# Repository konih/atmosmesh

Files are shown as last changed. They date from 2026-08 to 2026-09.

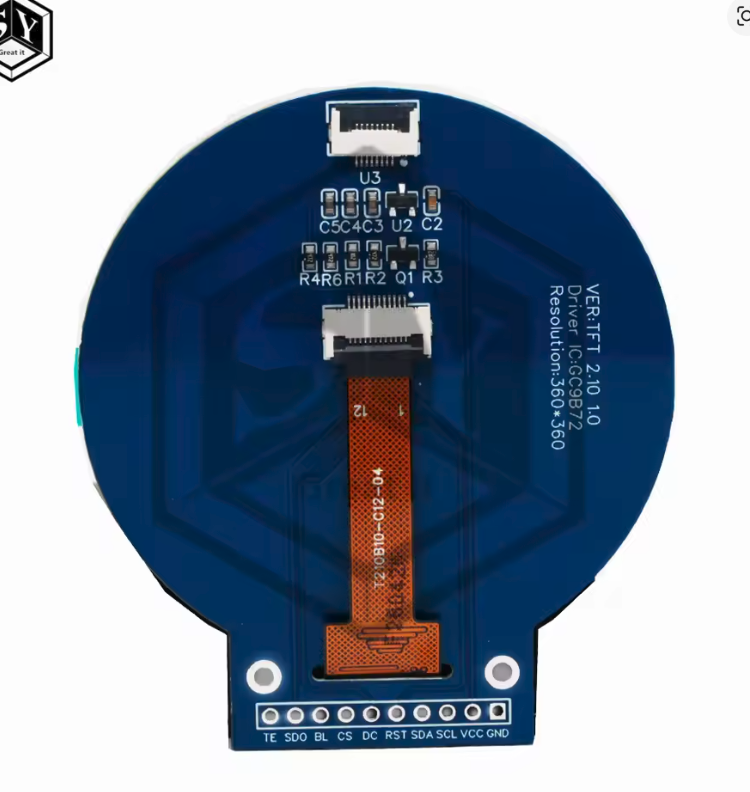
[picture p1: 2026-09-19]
docs/assets/inventory/gc9b72-round-tft-back-2026-09-19.png

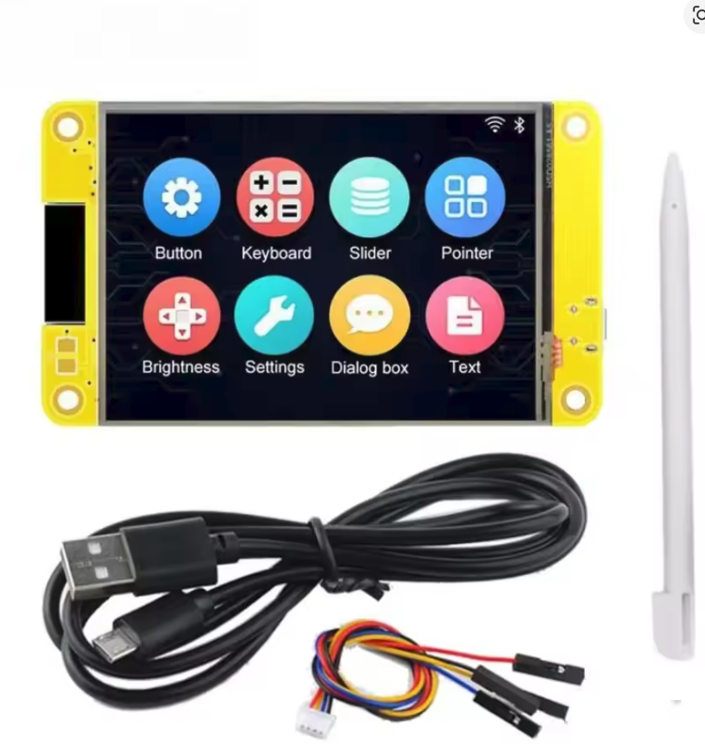
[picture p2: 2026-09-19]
docs/assets/inventory/esp32-2432s028-cyd-kit-2026-09-19.png

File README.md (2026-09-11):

<p align="center">
  AtmosMesh mark
</p>

<h1 align="center">AtmosMesh</h1>

<p align="center"><em>Local air sensing, connected as a mesh.</em></p>

<p align="center">
  
  
  
  
  
  
  
  
</p>

AtmosMesh is a family of local air-sensing firmware products, now spanning several product
variants (v1, Grove v1.5, Aqua, Room, Spot); none supersedes another.

## Firmware products

| Product | Product ID | Product variant | Controller | Sensor/display scope | Canonical build |
| --- | --- | --- | --- | --- | --- |
| **AtmosMesh v1** — **ARCHIVED** (D-034; physical station disassembled 2026-08-31) | `atmosmesh-v1` | `esp32-full-station` | ESP32-WROOM-32 | Full station: SSD1306, BMP280, AM2302, SDS011, MQ135, PIR/beeper, optional VEML7700, MQTT | `task build-v1` (not part of `task build-all`) |
| **AtmosMesh Grove v1.5** | `atmosmesh-grove-v1.5` | `atmosmesh-v1.5` | ESP8266EX / 4 MB NodeMCU-style board | Compact node: 128×32 SSD1306, BMP180, DHT11, uncalibrated D7 RC light, D0/D6 status LED, duty-cycled raw YL-38 ADC, MQTT | `task build-v1-5` |

The products share one PlatformIO project and host-tested core, with explicit composition roots
instead of copied firmware trees. See [ADR-0001](docs/adr/0001-multi-product-firmware-composition.md).

AtmosMesh v1 is **archived, not deleted** ([D-034](agent-context/decisions.md)): the physical
station was disassembled and its code/mentions are retired from the live fleet, but the source,
its tests, and the shared MQTT contract/composition pattern it established remain in the repo.
It was never a finished product — its wiring was never fully approved for unattended or
mains-powered use — and it is **not** a certified health, fire, gas, or life-safety instrument.

## AtmosMesh v1 measurements

| Sensor | Quantity | Notes |
| --- | --- | --- |
| SDS011 | PM2.5, PM10 | UART2 only (GPIO16/17). 5 V heater, 3.3 V UART |
| AM2302 / DHT22 | Temperature, humidity | GPIO18, 3V3 |
| BMP280 | Pressure, temperature | I²C 0x76 on GPIO21/19, 3V3 |
| Mini OLED (D-001) | Local live page | I²C 0x3C, SDA GPIO5, SCL GPIO4, **3V3 only** |
| MQ135 | Relative gas trend | Analog GPIO34 through a divider. **Never labelled CO₂ or ppm** |
| VEML7700 | Illuminance | Optional, I²C 0x10 on the BMP280 bus. Not fitted yet |
| PIR + beeper | Occupancy cue | GPIO33 / GPIO25 |

```text
SDS011 ─┐
AM2302 ─┤
BMP280 ─┼─> ESP32 ── OLED (local)
MQ135  ─┤       └─ MQTT (planned) ──> Mosquitto ──> Home Assistant
VEML   ─┘                         └─ metrics ─> Prometheus ─> Grafana
```

## Safety (read this first)

- ESP32 GPIOs and the `3V3` pin are **not 5 V tolerant**.
- SDS011 and MQ135 take **5 V power**; their *signals* stay at 3.3 V.
- SDS011 is **UART2 only**. Never GPIO1/TX0 or GPIO3/RX0 — those are the USB-UART
  used by `task flash` / `task monitor`.
- MQ135 analog goes through a measured divider before GPIO34. The live breadboard
  is 10 kΩ series + 20 kΩ to GND.
- Open mains PCBs stay off the breadboard and must be enclosed before they are
  energised. Mains switching is out of scope.
- Confirm every module's markings before you copy a pin table from this repo.

Full rules: [`AGENTS.md`](AGENTS.md) and [`docs/hardware/power.md`](docs/hardware/power.md).

## Quick start

Host tests need PlatformIO and Python 3.11 or 3.12 (not Homebrew 3.14):

```bash
task bootstrap-agent-python   # creates .venv with pyserial + esptool
task test                     # native Unity tests (no hardware)
task build-all                # both first-class product images
task build-v1                 # AtmosMesh v1 / ESP32
task build-v1-5               # AtmosMesh Grove v1.5 / ESP8266
```

Canonical device actions are `task flash-v1`, `task monitor-v1`, `task flash-v1-5`, and
`task monitor-v1-5`. Existing `build`/`flash`/`monitor` and `*-grove` tasks remain compatibility
aliases. Override the serial port with `ESP_PORT=/dev/…`.

Do not run `python -m esptool` with system Python. Direct wrapper: `./scripts/esp-tool version`.

Firmware details, OLED constructor, and the live pin map:
[`firmware/README.md`](firmware/README.md).

## Hardware

| Path | What |
| --- | --- |
| [`docs/hardware/inventory.md`](docs/hardware/inventory.md) | Confirmed parts and open questions |
| [`docs/elektronik-inventar.md`](docs/elektronik-inventar.md) | Full electronics stock inventory, including parts not currently assigned to a product |
| [`docs/hardware/datasheets/`](docs/hardware/datasheets/README.md) | Manufacturer datasheets and retained kit manuals |
| [`docs/hardware/power.md`](docs/hardware/power.md) | 5 V / 3.3 V domains |
| [`docs/hardware/oscilloscope-hantek-dso2d15.md`](docs/hardware/oscilloscope-hantek-dso2d15.md) | Bench scope: panel, probe setup, and the ripple / I²C / UART / rail recipes |
| [`hardware/kicad/`](hardware/kicad/README.md) | Bench carrier (KiCad 10): OLED, sensors, extras strip, fully routed. **Do not fabricate** until DevKit pin order is photographed |

The carrier board uses a **10 k / 15 k** MQ135 divider (3.0 V max on GPIO34).
Firmware still matches the **breadboard 10 k / 20 k** until that board replaces
the breadboard.

## Repository layout

| Path | Purpose |
| --- | --- |
| `firmware/` | One PlatformIO project, explicit product roots, shared core and native tests |
| `docs/adr/` | Architecture decision records |
| `docs/history/` | Superseded project notes and concept artifacts retained for provenance |
| `hardware/kicad/` | Bench-station carrier schematic and PCB |
| `docs/` | Architecture, hardware facts, datasheets |
| `deploy/` | Kubernetes / home-automation config (not packaged yet) |
| `tests/` | Host-side checks |
| `agent-context/` | Stories, decisions, and live session notes |
| `AGENTS.md` | Safety boundaries and workflow for humans and agents |

## Status

AtmosMesh v1 bench firmware drives the OLED (U8g2 SSD1306 ALT0), BMP280, AM2302,
SDS011 UART2, MQ135 ADC, PIR, and beeper. MQTT, Home Assistant, and the cluster
path are still ahead. Grove v1.5 hardware has runtime communication evidence for BMP180 and DHT11;
OLED controller initialization passed but pixels need visual confirmation. Cooperative D7 RC light
timing and Grove MQTT/HA discovery are implemented and host/build-tested. Reviewed Grove soil
firmware has produced two raw ADC 214 cycles about 30 seconds apart. The installed D6 red / D0
green LED is operator-confirmed common-anode; soil direction/threshold calibration, switched-rail
electrical behavior, MQTT receipt and OLED pixels remain unconfirmed
([roadmap](agent-context/roadmap.md)).

## License and contributors

[MIT](LICENSE). People: [CONTRIBUTORS.md](CONTRIBUTORS.md). Security:
[SECURITY.md](SECURITY.md).

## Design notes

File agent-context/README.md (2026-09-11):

# Agent context dashboard

Committed live context for humans and coding agents. Stable constraints live in `../AGENTS.md`;
this dashboard records what changes between sessions.

**Last updated:** 2026-08-28

## Active work

| Story | Status | Objective | Next action |
| --- | --- | --- | --- |
| [ROOM-01](stories/ROOM-01.md) | Blocked | Protected 60×80 mm room-station carrier and complete build plan | Obtain exact controller/SHT41/PIR/buzzer front/back photos before routing or fabrication |
| [RLS-01](stories/RLS-01.md) | Ready | Identify exact hardware and approve a safe wiring table | Photos + enclosed 5 V measurement |
| [V15-03](stories/V15-03.md) | Blocked | Finish Grove OLED/BMP180/DHT11 validation | Confirm OLED pixels |
| [V15-04](stories/V15-04.md) | Blocked | Validate bounded uncalibrated D7 RC light response | Bright/dark/saturation/timeout evidence |
| [V15-05](stories/V15-05.md) | Blocked | Validate Grove MQTT and HA discovery | Broker/HA/reconnect evidence |
| [V15-06](stories/V15-06.md) | Blocked | Add bi-color status and duty-cycled raw soil ADC | LED and switched-rail electrical validation |
| [V15-07](stories/V15-07.md) | Blocked | Replace cryptic Grove OLED rows with labelled measurements | Operator visual confirmation |
| [V15-08](stories/V15-08.md) | Blocked | Add reversible Grove OLED/LED visual diagnostic | Independent review, then operator inspection |
| [V15-09](stories/V15-09.md) | Blocked | Add calibration-safe Grove soil/system LED status | Visual confirmation and controlled dry/wet thresholds |
OLED VCC must be **3.3 V**. OLED SDA is GPIO5, SCL GPIO4 (0x3C proven). GPIO5 idle-high is usually OK for flash.

## Current blockers

- Exact ESP32 **devboard** silkscreen (`VIN`/`5V` vs `3V3`) is not confirmed (chip is ESP32-D0WDQ6).
- OLED: SSD1306 at **0x3C** on SDA=GPIO5 SCL=GPIO4 (serial-proven). Default firmware is U8g2 **SSD1306 ALT0** (sequential COM). SH1106 remains a compile fallback.
- BMP280 breakout is 6-pin (VCC GND SCL SDA CSB SDO); onboard regulator / 5 V VCC still unconfirmed.
- Candidate 5 V AC/DC `5V07 / 12V04` is unverified (5 V/700 mA vs 12 V) and still an open mains PCB.
- Shared-rail peak current (~650 mA) vs 700 mA module rating is unresolved.
- MQ135 module output range has not been measured.
- Firmware framework: PlatformIO (D-006). Cluster packaging still open (OQ-002).
- Grove OLED initialization passes at 0x3C/128×32, but visible pixels are not yet confirmed.
- Reviewed Grove head `4e4a820` is flashed. Serial proves uncalibrated D7 values of 420–492 µs, but
  bright/dark/saturation/timeout behavior and MQTT broker/HA receipt remain unvalidated.
- Grove V15-06 serial again reports raw ADC 214 with `samples=5 power=off`. The operator has now
  confirmed the fitted D6 red / D0 green LED is common-anode; only active-LOW diagnostic output
  produced the intended colors. Soil direction/threshold calibration, broker/HA receipt,
  switched-rail voltage/current, physical power-off and OLED pixels remain unconfirmed.
- Reviewed V15-09 head `8fca62d` is now flashed. Serial proves the canonical profile drove logical
  common-anode amber (`red=LOW green=LOW`) for raw soil ADC 213 with calibration disabled. Visible
  colour for this canonical run, physical power-off and dry/wet calibration references remain
  operator-unconfirmed.

## Next operator inputs

1. Photograph the front and back of the ESP32 (including `VIN`/`5V`/`3V3` labels), both mini-OLEDs,
   BMP280, DHT22, SDS011 plus adapter/cable, MQ135, and the `5V07 / 12V04` AC/DC (AC pads vs DC pads).
2. Enclose the AC/DC primary **before** applying 230 V. Measure DC out with no ESP32 attached.
3. Record whether a dummy-load measurement is possible and the observed voltage/ripple.
4. For Grove, visually confirm the flashed V15-07 four-labelled-measurement-row layout.
5. Exercise the Grove LDR under bright/dark and saturation/timeout conditions.
6. Measure controlled dry/wet raw soil values to establish direction and thresholds; verify the YL
   switched-rail voltage/current and physical power-off, then confirm MQTT broker/HA receipt and
   reconnect behavior.

Do not connect the proposed complete circuit before these checks. Do not put mains on a breadboard.

The separate **AtmosMesh Grove v1.5** board is an ESP8266EX with 4 MB flash. After authorization
and independent review, the coordinator replaced its AT firmware with AtmosMesh Grove on
2026-08-24. A second reviewed flash confirmed the explicit stable product ID at runtime. BMP180
passed runtime sampling; OLED initialized at 0x3C but pixels need visual proof. DHT11 later produced
valid frames on D5/GPIO14 (communication pass only, not accuracy proof). Details are in V15-03.

## Key context

| Topic | File |
| --- | --- |
| Delivery order | [roadmap.md](roadmap.md) |
| Decisions and open questions | [decisions.md](decisions.md) |
| Unbuilt product concepts / idea backlog | [project-ideas.md](project-ideas.md) |
| Story contracts | [stories/](stories/) |
| Hardware facts | [../docs/hardware/inventory.md](../docs/hardware/inventory.md) |
| Power architecture | [../docs/hardware/power.md](../docs/hardware/power.md) |
| Datasheets / spec comparison | [../docs/hardware/datasheets/](../docs/hardware/datasheets/), [../docs/hardware/spec-comparison.md](../docs/hardware/spec-comparison.md) |
| System architecture | [../docs/architecture.md](../docs/architecture.md) |
| Architecture decisions | [../docs/adr/](../docs/adr/) |
| Firmware | [../firmware/README.md](../firmware/README.md) |

## Workflow

1. Read `../AGENTS.md`, this dashboard, and the active story.
2. Claim a story only when all dependencies are done.
3. Update the story with evidence as criteria are verified.
4. Update the roadmap and dashboard together when status changes.
5. Add a dated handoff when stopping mid-story.

## Status legend

- `Ready`: dependencies satisfied; safe to claim.
- `Blocked`: waiting on another story, evidence, or operator input.
- `In flight`: actively being worked; owner/session recorded.
- `Done`: all acceptance criteria have evidence.
- `Optional`: outside the MVP unless explicitly promoted.

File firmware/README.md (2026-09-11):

# Firmware

PlatformIO + Arduino builds two independent, first-class products from one project:

| Product | Stable product ID | Product variant | Composition root | Canonical environment |
| --- | --- | --- | --- | --- |
| **AtmosMesh v1** — **ARCHIVED** (D-034; physical station disassembled), full ESP32 station | `atmosmesh-v1` | `esp32-full-station` | `src/products/atmosmesh_v1.cpp` | `atmosmesh-v1` (not in `task build-all`) |
| **AtmosMesh Grove v1.5** — compact ESP8266 node | `atmosmesh-grove-v1.5` | `atmosmesh-v1.5` | `src/products/atmosmesh_grove_v1_5.cpp` | `atmosmesh-grove-v1_5` |
| **AtmosMesh Spot** — ESP32-C3 SuperMini OLED presence node | `atmosmesh-spot-v1` | `atmosmesh-spot-v1` | `src/products/atmosmesh_spot_v1.cpp` | `atmosmesh-spot-v1` |

Neither product replaces the other. The composition model and version semantics are defined by the
accepted [ADR-0001](../docs/adr/0001-multi-product-firmware-composition.md).

PlatformIO source filters select the existing ESP32 runtime from its named composition root and a
separate thin, profiled Grove root. Grove health states and display formatting live under
`include/atmosmesh/` and are exercised by the same `native` host tests; Grove is not a wholesale
copy of the ESP32 application. This slice does not refactor or describe the legacy ESP32 entrypoint
as thin/profile-driven.

## Commands

Prefer `task` from the repository root so the shared agent venv is on `PATH` (`python` +
`pyserial` + `esptool`). Do not use Homebrew or Xcode `python -m esptool`.

From `firmware/` (only after `scripts/with-agent-python` or the venv `bin` is first on `PATH`):

```bash
pio test -e native          # host unit tests (required)
pio run -e atmosmesh-v1             # canonical ESP32 product
pio run -e atmosmesh-grove-v1_5     # canonical Grove product
pio run -e esp32dev                  # compatibility environment
pio run -e esp8266-grove             # compatibility environment
pio device monitor --port /dev/cu.usbserial-0001 --baud 115200
```

From the repository root use `task build-v1`, `task build-v1-5`, or `task build-all`. Canonical
device actions are `flash-v1`/`monitor-v1` and `flash-v1-5`/`monitor-v1-5`; the existing
`build`/`flash`/`monitor` and `*-grove` tasks remain compatibility aliases. The Room product adds
`build-room`/`flash-room`/`monitor-room`/`clean-room`.

After explicit authorization and independent review, the coordinator flashed AtmosMesh Grove on
2026-08-24. The former AT firmware was replaced. Reviewed head `c880afe`, including RC light, MQTT,
LED and soil support, was later flashed successfully. Serial/raw sampling evidence is described
below; visual, electrical and broker-side validation remains incomplete.

## AtmosMesh Grove v1.5 wiring

The default ID is `atmosmesh-grove-0001`; IDs remain device-based, never room names. A read-only
probe found an ESP8266EX with a 26 MHz crystal and 4 MB flash. The NodeMCU-style profile is:

Current firmware emits all identity concepts separately:

```text
product=AtmosMesh Grove product_id=atmosmesh-grove-v1.5 variant=atmosmesh-v1.5 station_id=atmosmesh-grove-0001
```

| Device | Module pin | ESP8266MOD | Notes |
| --- | --- | --- | --- |
| SSD1306 128×32 | SDA | `D2` / GPIO4 | I²C 0x3C, then 0x3D fallback |
| SSD1306 128×32 | SCL | `D3` / GPIO0 | Shared bus; boot-strap caveat below |
| BMP180 | SDA | `D2` / GPIO4 | I²C 0x77 |
| BMP180 | SCL | `D3` / GPIO0 | Shared bus |
| DHT11 | DATA | `D5` / GPIO14 | Valid communication observed; readings remain uncalibrated |
| Bare LDR RC | Measurement node | `D7` / GPIO13 | `3V3 → LDR → 1 kΩ → node`; 100 nF node-to-GND |
| Bi-color LED red | Color channel | `D6` / GPIO12 | Separate ~330 Ω resistor |
| Bi-color LED green | Color channel | `D0` / GPIO16 | Separate ~330 Ω resistor |
| YL-38 high-side switch | 2N3906 PNP base | `D1` / GPIO5 | Active LOW via 2.2 kΩ; external 100 kΩ base-emitter pull-up |
| YL-38 | AO | `A0` through 47 kΩ / 15 kΩ | 100 nF (`104`) A0-to-GND; DO unused |
| All modules | VCC/GND | `3V3` / GND | Never power their GPIO pull-ups from 5 V |

Firmware deliberately calls `Wire.begin(4, 0)`; it does not silently rewrite the physical wiring.
`D3` is GPIO0, an ESP8266 boot strap. It must stay **HIGH during reset**. If a module or fault holds
SCL low, the board enters the ROM downloader rather than starting AtmosMesh. Moving SCL to D1/GPIO5
would now conflict with the V15-06 soil control pin and requires an explicit hardware/profile
redesign; it is not the v1.5 wiring implemented here.

The 32-pixel display uses all four rows for labelled measurements, for example:

```text
T:25.0C RH:36%
P:982.7hPa
Light:401us
Soil:214
```

The page has no product row or anonymous health bits; identity and detailed health remain on serial
and the bi-color LED. Missing values retain their labels (`T:--`, `RH:--`, `P:ERR`, `Light:--`,
`Soil:--`), while valid numeric zero remains visible. Temperature is DHT11 `temperature_c`; BMP
temperature is not added to the public display/MQTT contract. Light stays raw microseconds and soil
stays raw ADC, never lux or moisture percent. Each line is bounded to 21 characters for the 5×7
font on the 128-pixel display.
Every sensor cycle probes BMP180 address 0x77: loss immediately invalidates the prior sample, while
return triggers reinitialization before a value can become valid again. Serial startup identifies
the product/station, exact pins, GPIO0 warning and every init/read state.

### Temporary OLED/LED visual diagnostic

The canonical `task build-v1-5` image always keeps the four live sensor rows above. For an operator
measurement of the physical active area and installed bi-color LED, an explicit temporary image
compiles `ATMOSMESH_GROVE_VISUAL_DIAGNOSTIC=1`:

```bash
task build-grove-visual-diagnostic
# After independent review and explicit authorization only:
ESP_PORT=/dev/cu.usbserial-0001 task flash-grove-visual-diagnostic
ESP_PORT=/dev/cu.usbserial-0001 task monitor-grove-visual-diagnostic
```

The selected diagnostic and logical geometry are announced before OLED probing, so even a missing
or failed display cannot hide which image is running:

```text
visual-diagnostic: selected oled=full-area geometry=128x32 led=red-green-amber-off phase=2000ms
```

After successful OLED initialization, the image fills the complete logical 128×32 framebuffer with
ON pixels and suppresses every later live-page redraw while sensors, LED and networking keep
running. Serial separately reports `oled-diagnostic: fill applied geometry=128x32 pixels=all-on`.
Missing-address and initialization failures instead report `fill not-applied` with
`reason=oled-not-found` or `reason=oled-init-failed`; the selection banner still appears.

At the same time, the installed D6 red / D0 green LED repeats two seconds red, two seconds green,
two seconds amber (both channels), then two seconds off. Each transition reports the expected color
and actual polarity-aware pin levels. The installed/default common-anode red phase is:

```text
visual-diagnostic-led: color=red D6=LOW D0=HIGH
```

The explicit common-cathode override inverts those levels while preserving the visible sequence.

This is a reversible diagnostic, not a product default. Leave it running until the operator
explicitly asks to restore normal firmware, then use a reviewed `task flash-v1-5`. A filled logical
framebuffer and commanded LED levels do not by themselves prove the size/condition of the physical
lit area or the visible LED colors.

The LDR is uncalibrated digital RC timing: firmware discharges D7 for 1 ms, releases it as an input,
then advances a cooperative time-to-high state machine with a 200 ms hard timeout. A valid
`light_charge_us` value is raw microseconds and **lower means brighter**. Immediate/saturated,
timeout or disconnected states are unavailable. MAX4466 remains dropped.

The firmware samples D7 synchronously immediately after changing it from driven-low to input. If
the released line is already HIGH, that cycle is saturated/unavailable rather than a small plausible
charge time. Normal charge timing continues cooperatively on subsequent loop ticks.

### Bi-color health LED

The installed and canonical Grove profile is common-anode: red D6/GPIO12 and green D0/GPIO16 are
active LOW. Each channel requires its own approximately 330 Ω resistor. Startup prints the exact
compiled polarity and HIGH/LOW levels. No WS2812 library is used. Alternative common-cathode
hardware remains an explicit build-only override:

```bash
task build-grove-common-cathode
```

The normal LED priority is deterministic:

| Priority | Color | Meaning |
| ---: | --- | --- |
| 1 | Red | DHT/BMP or explicit light/soil acquisition error |
| 2 | Red | MQTT is configured but offline; intentionally unconfigured MQTT is neutral |
| 3 | Red | Valid calibration classifies the raw soil value as dry |
| 4 | Amber (red + green) | Soil sample missing, calibration disabled/invalid, or calibrated needs-watering band |
| 5 | Green | Soil is calibrated acceptable and every higher-priority condition is healthy |

A boot-time DHT/BMP value is unknown until the first acquisition attempt and is not itself an
error: with MQTT intentionally unconfigured, the missing pre-soil state is amber. Once a DHT/BMP
cycle has actually run, a missing core reading is red. Configured-but-offline MQTT retains its
higher red priority even during startup.

A light value that is merely uncalibrated or immediately saturated does not by itself turn the LED
red. Before the first soil sample, and after a valid raw sample without validated calibration, the
LED stays amber rather than guessing moisture.

Soil calibration is compile-time metadata. The four macros are
`ATMOSMESH_GROVE_SOIL_CALIBRATION_ENABLED` (`0`/`1`),
`ATMOSMESH_GROVE_SOIL_RAW_DIRECTION` (`1` higher-is-wetter, `2` lower-is-wetter),
`ATMOSMESH_GROVE_SOIL_DRY_CUTOFF_RAW`, and
`ATMOSMESH_GROVE_SOIL_ACCEPTABLE_CUTOFF_RAW`. Both cutoffs must be raw ADC values in `0..1023`.
Higher-is-wetter requires `dry < acceptable`; lower-is-wetter requires `dry > acceptable`.
Unknown direction, out-of-range/equal cutoffs, or direction-inconsistent ordering fails safe to
uncalibrated amber. Serial reports `soil-led-status`, reason, raw value, validation, direction and
cutoffs. MQTT and Home Assistant remain raw-only.

The canonical `atmosmesh-grove-v1_5` environment (and its `esp8266-grove`,
`-visual-diagnostic`, and `-common-cathode` variants) compiles with calibration **enabled**,
from operator dry/wet observation, 2026-08-26: `ATMOSMESH_GROVE_SOIL_RAW_DIRECTION=2`
(lower-is-wetter), `ATMOSMESH_GROVE_SOIL_DRY_CUTOFF_RAW=200`,
`ATMOSMESH_GROVE_SOIL_ACCEPTABLE_CUTOFF_RAW=100` — raw ADC 200+ reads dry (red), raw ADC 100
or below reads well-watered (green), the band between reads needs-watering (amber). The
`native` host-test environment keeps calibration disabled, so its default-disabled unit tests
still exercise the fail-safe path.

### YL-38 raw ADC and switched power

The operator confirmed and physically wired a 2N3906 PNP high-side switch: emitter=3V3,
collector=YL-38 VCC, base=D1/GPIO5 through 2.2 kΩ, with an external 100 kΩ base-to-emitter pull-up.
GPIO5 drives only the base and is active LOW—never power the YL board from a GPIO. If YL VCC is
wired directly to 3V3, firmware cannot prevent continuous power and makes no duty-cycle claim.

YL AO reaches A0 through a conservative 47 kΩ top / 15 kΩ bottom divider; 100 nF (`104`) from A0
to GND filters noise. Grounds are common and YL DO is unused. This divider keeps 3.3 V AO
near 0.80 V for a bare 1.0 V ESP8266 ADC. Some NodeMCU boards already divide A0, so the combined
attenuation and raw counts depend on the exact board. Firmware therefore exposes only
`soil_adc_raw`, never calibrated moisture or percent.

Firmware latches D1 HIGH before enabling OUTPUT, waits 30 seconds between cycle starts, then drives
the PNP base control LOW, settles 100 ms, takes five samples 5 ms apart, averages them, and returns
the control pin HIGH immediately. Normal power-on time is 120 ms / 30 s = 0.4%; the 250 ms fail-off
deadline bounds the cooperative policy to 0.84% (rounded-up documented bound 0.9%). MQTT/DNS/TCP
work is not started while YL power is active. Before the first completed cycle the field is
unavailable/omitted; raw ADC zero after a completed cycle is a valid numeric reading.

### Grove MQTT contract

With generated credentials present, the Grove transport uses ESP8266WiFi and pinned PubSubClient
2.8 over the shared host-tested MQTT contract/session. Without credentials, networking is disabled
and sensors/OLED continue.

| Piece | Grove value |
| --- | --- |
| State | `home/air/atmosmesh-grove-0001/state` (not retained) |
| Availability/LWT | `home/air/atmosmesh-grove-0001/availability` (`online`/`offline`, retained) |
| Discovery | `homeassistant/sensor/atmosmesh_grove_0001/<object_id>/config` (retained) |
| Entities | `temperature_c`, `humidity_pct`, `pressure_hpa`, `light_charge_us`, `soil_adc_raw` |

State omits invalid values, so missing is distinct from a valid numeric zero. The light entity is
named **Uncalibrated RC Light Charge Time**, uses `µs`, and has no illuminance device class.
The soil entity is **Soil Probe ADC Raw**, uses `ADC count`, and has no moisture device class,
percentage or calibration claim. Every connect replays discovery, followed by retained online
availability and any pending state. Broker
retries back off from 1 to 30 seconds. DNS lookup and TCP connection share a 1000 ms transport
budget instead of the ESP8266 core's roughly five-second default. PubSubClient's subsequent MQTT
response wait is separately bounded to one second, so a complete failed attempt can occupy roughly
two seconds before the reconnect backoff resumes local work.

### Room MQTT contract

The Room image is ESP32, so it uses `esp-mqtt` over the same host-tested contract/session as
AtmosMesh v1 — not Grove's PubSubClient. Without credentials, networking is disabled and the
sensors and TFT continue.

| Piece | Room value |
| --- | --- |
| State | `home/air/atmosmesh-room-0001/state` (not retained, every 5 s) |
| Availability/LWT | `home/air/atmosmesh-room-0001/availability` (`online`/`offline`, retained) |
| Discovery | `homeassistant/{sensor,binary_sensor}/atmosmesh_room_0001/<object_id>/config` (retained) |
| Entities | `temperature_c`, `humidity_pct`, `illuminance_lx`, `pm25`, `pm10`, `motion`, `pm_alarm` |

Room uses the nested `{value, unit, valid, age_ms}` payload shape and `value_template`s of the
form `… if value_json.x.valid else none`, so an entity goes **unavailable** rather than reporting
a number the sensor did not produce. This matters more here than on Grove: an SDS011 that has
stopped sending frames must not appear in Home Assistant as clean air, and a PIR still inside its
60 s warm-up must not publish "no motion" as though it were a measurement. Particulates are
likewise invalid until the sensor's 30 s spin-up has elapsed.

`motion` is a `binary_sensor` with device class `occupancy`. `pm_alarm` is a `binary_sensor` with
device class `problem` and carries the same latch that sounds the beeper, so an automation can
react to what the room heard. State is published every 5 s, and immediately whenever `motion` or
`pm_alarm` changes, so neither waits out the interval.

The client sets an explicit client id (`atmosmesh-room-0001`), a 45 s keepalive and a 30 s
network timeout. The stock 15 s/10 s pair tore the session down about every ten seconds at the
roughly −75 dBm this board sees; `expire_after` stays 90 s, so Home Assistant still marks entities
unavailable long before a dead board could look live. Wi-Fi association is retried with a fresh
`WiFi.begin()` every 30 s while unassociated — a single `begin()` can sit in `WL_DISCONNECTED`
indefinitely on this board.

### Controlled hardware result (2026-08-24)

- Latest reviewed head `4e4a820` flashed successfully: esptool wrote 310,224 bytes, verified the
  hash and hard-reset the ESP8266EX/26 MHz board. More than 30 seconds of serial reported
  `mqtt: connected`, logical LED status `green/healthy`, DHT11 25.0 °C / 36% RH, BMP180
  25.3–25.7 °C / 982.1–982.4 hPa, raw light 420–492 µs and
  `soil: ok adc_raw=214 samples=5 power=off`. These are firmware/runtime diagnostics only: broker
  receipt/HA entities, visible LED colour/polarity and the visible four-row OLED layout remain
  operator-unconfirmed.
- OLED: controller initialization passed at 0x3C as 128×32; pixels remain visually unconfirmed.
- BMP180: runtime passed repeatedly; latest paired observation was 25.6 °C / 983.9–984.0 hPa.
- DHT11: later reported 32.0 °C / 32% RH then 31.0 °C / 32% RH on D5/GPIO14. This proves
  communication, not accuracy or calibration.
- RC light: serial showed uncalibrated 389–452 µs values; controlled bright/dark/saturation/timeout
  response remains pending. MQTT broker/HA receipt and reconnect behavior are not yet validated.
- YL-38: serial showed two cycles about 30 seconds apart, each
  `soil: ok adc_raw=214 samples=5 power=off`. This proves raw acquisition and the firmware OFF action,
  not calibration, switched-rail voltage/current or physical power-off.
- Bi-color LED wiring was subsequently confirmed by the operator as D6 red / D0 green,
  common-anode: only the active-LOW/inverted diagnostic produced the intended colors. Soil
  calibration and its threshold-driven colors remain unvalidated.
- Independently approved canonical head `8fca62d` was then flashed successfully. Serial reported
  raw soil ADC 213 and logical amber with common-anode output levels `red=LOW green=LOW`, reason
  `soil-calibration-needed`, calibration disabled, direction unknown and both thresholds unset.
  This is logical policy/pin-drive evidence, not visible colour, physical power-off or calibration
  evidence; those operator checks remain pending.
- The first captured banner from reviewed head `a681990` contained product name, variant and station
  ID but no separate `product_id`. A second reviewed flash of final head `50ca2f3` captured the exact
  four-field banner documented above.

## AtmosMesh Spot (SP-01 / SP-02)

ESP32-C3 SuperMini with the 0.42 inch OLED on the 14 × 20 carrier
([wiring](../hardware/kicad/atmosmesh-spot/wiring.md)). One 3.3 V domain, USB powered. Needs
`espressif32` 7.x (Arduino core 3.x, RISC-V toolchain); the shared agent venv does not carry
PlatformIO on Linux, see `tools/c3scan/README.md` for the venv recipe and two gotchas.

```bash
pio run -e atmosmesh-spot-v1                                   # build
pio run -e atmosmesh-spot-v1 -t upload --upload-port /dev/ttyACM0   # flash over native USB
pio device monitor --port /dev/ttyACM0 --baud 115200
```

or `task build-spot` / `ESP_PORT=/dev/ttyACM0 task flash-spot` / `task monitor-spot`. The board
enumerates as `Espressif USB JTAG/serial debug unit` (303a:1001); the user needs `dialout`.

| Device | SuperMini pin | GPIO | Notes |
| --- | --- | --- | --- |
| OLED SSD1306 72×40 | on board | SDA 5 / SCL 6 | `0x3C`, U8g2 `72X40_ER`, 100 kHz |
| SHT41 (`SHT4X` board) | `5` / `6` | same bus | `0x44`, raw I²C, host-tested CRC |
| VEML7700 (`HW-900`) | `5` / `6` | same bus | `0x10`, Adafruit driver, auto-ranging lux |
| HLK-LD2410S `OT2` | `3` | GPIO3 | presence, HIGH = somebody, `INPUT_PULLDOWN` |
| HLK-LD2410S `OT1` (its TX) | `RX` | GPIO20 | UART0 RX, 115200 8N1, minimal + standard frames |
| HLK-LD2410S `RX` | `TX` | GPIO21 | UART0 TX |
| DS18B20 probe | `4` | GPIO4 | 1-Wire, powered mode, 4.7 kΩ on the carrier |
| BOOT button / IO8 LED | on board | GPIO9 / GPIO8 | next display page / heartbeat toggle |

**U8g2 on Arduino core 3.x:** construct the display **without** pin numbers and start `Wire`
yourself. Given pins, U8g2's GPIO init calls `pinMode()` on SDA and SCL, the core's peripheral
manager hands the pins back from the I²C driver, and `oled.begin()` never returns — observed on
the first unit on 2026-09-05 (sensors answered before the OLED init, nothing after).

**The radar's UART, four things learned the hard way (2026-09-05):**

1. **Never leave a pull-down on the RX pin.** The C3 attaches UART0 RX to GPIO20 through its
   direct mux and does not touch the pull resistors, so a `pinMode(20, INPUT_PULLDOWN)` from a
   wiring check stays on the line. The LD2410S's `OT1` is a weak driver: it reads LOW against
   that pull-down and HIGH against a pull-up, and its frames only decode with the pull-up. The
   firmware reads the line against both pulls at boot (`pull-down->LOW pull-up->HIGH` is the
   healthy reading on this module; LOW under the pull-up means a joint), then leaves
   `GPIO_PULLUP_ONLY` on RX after `Serial0.begin()`.
2. **The module needs a break to start streaming.** After a reset it sends two or three frames
   and waits; a 200 ms low on its RX (our TX) starts the continuous report. The boot kick is
   break plus end-configuration, and the same nudge repeats if the stream stops; a full
   enable/read-version/output-mode/end sequence follows if that fails. Every ACK is logged.
3. **IDF logging is silenced** (`esp_log_level_set("*", ESP_LOG_NONE)`): the IDF console is
   UART0, i.e. the radar's RX, and the module answers log lines with an enable-config ACK every
   time esp-mqtt retried. The ROM and bootloader lines at reset still reach it; they are what
   produced the "ACK at every reset" that first proved the transmitter alive.
4. **The VEML7700 is read at a fixed gain (1/4, 100 ms) without waiting.** `VEML_LUX_AUTO`
   took 5.1 s per sample in a dark room and stalled the radar drain, the presence poll and the
   button. Every 5 s line ends with the slowest loop stage; it is now the 43 ms OLED redraw.

`radar: OT1 line … pull-down->LOW pull-up->LOW - HELD LOW` is the one boot line that means a
wiring fault; RX LOW with TX HIGH under the pull-down means `OT1` landed on the TX pin (the UART
is then run crossed for that boot and the log says so).

### Spot MQTT contract

Same `esp-mqtt` transport as Room, through `esp32_mqtt_runtime.cpp`, which takes the product
contract as a parameter (Room still runs its own file). Without credentials the sensors and OLED
continue and networking stays off.

| Piece | Spot value |
| --- | --- |
| State | `home/air/atmosmesh-spot-0001/state` (not retained, every 5 s, immediately on a presence flip) |
| Availability/LWT | `home/air/atmosmesh-spot-0001/availability` (`online`/`offline`, retained) |
| Discovery | `homeassistant/{sensor,binary_sensor}/atmosmesh_spot_0001/<object_id>/config` (retained) |
| Entities | `temperature_c`, `humidity_pct`, `illuminance_lx`, `probe_temperature_c`, `presence_distance_cm`, `presence_state`, `wifi_rssi_dbm`, `presence` |

Nested `{value, unit, valid, age_ms}` payloads as on Room. `presence` is a `binary_sensor` with
device class `occupancy` from `OT2` through a 50 ms debounce and a 5 s hold, valid once a radar
is known to be attached (frames seen, or `OT2` ever high) and the 10 s warm-up is over.
`presence_distance_cm` (device class `distance`) and `presence_state` (the radar's raw byte:
0/1 nobody, 2/3 somebody; the manual defines nothing finer) come from the UART report and are
valid only while frames keep arriving. `probe_temperature_c` goes unavailable after three bad
scratchpads and the probe is searched for again every 10 s. Wi-Fi TX power is limited to
8.5 dBm at start-up (the SuperMini's ceramic antenna drops off the network at full power).

### First unit (2026-09-05)

Soldered carrier: bus scan `0x10 0x3C 0x44`. Product image: SHT41 27.7 °C / 61 %RH, VEML7700
9–68 lx, DS18B20 probe 24.9 °C, presence occupied from `OT2`, Wi-Fi −72 dBm channel 11 with the
limit applied, `mqtt: connected` as `atmosmesh-spot-0001`; RAM 12.6 %, flash 72.7 %. The radar's
`OT1` was genuinely open at first (the pin floated, no edge on any free GPIO, no ACK to a version
command); the operator reflowed the module's chip, after which the four points above were found
one by one. End state: `<- ack end-config status=0` at boot and a continuous minimal-frame stream
(about 3–4 frames/s, distance and state on the display and in MQTT). The SHT41 sits about 3 K
above the probe and climbs as the board warms. The radar kept reporting a target at ~71 cm after
the operator said they had left the room — the empty-room test in SP-01 is next.

## AtmosMesh v1 bench OLED wiring (D-001)

Mini I²C SSD1306 on the DevBoard (serial-proven 0x3C):

| OLED | ESP32 |
| --- | --- |
| VCC | **3V3 only** |
| GND | GND |
| SDA | D5 / GPIO5 (firmware retries GPIO4 if this mapping is silent) |
| SCL | D4 / GPIO4 |

Boot diagnostic: five 2 px bars at y=0, 16, 32, 48, 62 for ~1.5 s (`oled: bars y=0,16,32,48,62 —
say which you see`), then a **3-row** live page packed into the **lower 32 px** (glyph tops at
y=34/46/58): T/RH, hPa/gas index, PM2.5/PM10. Serial prints `oled: flip=0` (rebuild with
`-DATMOSMESH_OLED_FLIP=1` if COM is inverted). Serial still prints full BMP T/P, AM2302, SDS011
PM, and MQ135 **raw ADC / GPIO volts** (never CO₂). Firmware prefers I²C **0x3C**, then **0x3D**.
LCD backpack addresses (0x27/0x3F) are not the display.

**Default constructor is `U8G2_SSD1306_128X64_ALT0_F_HW_I2C` (sequential COM).** Do not send
mux `0x2F`. Do not use `U8G2_SSD1306_128X32_UNIVISION_F_HW_I2C` as the default — that only
lights the top ~32 px of 128×64 glass. I²C clock is **100 kHz**. **OLED VCC = 3V3**; 5 V on
VCC with pull-ups to VCC can kill GPIO5/4.

## AtmosMesh v1 sensor wiring (operator 2026-08-14)

| Device | ESP32 | Notes |
| --- | --- | --- |
| GY-BMP280 SDA | GPIO21 | VCC=3V3, CSB=3V3, SDO=GND → 0x76 |
| GY-BMP280 SCL | GPIO19 | Not GPIO22 |
| AM2302 DATA | GPIO18 | VDD=3V3. GPIO18 high matches the 3.3 V flash-voltage strap; keep idle-high |
| SDS011 TX | GPIO16 / RX2 | Sensor TX → **D16/RX2**. VCC=**5 V**. UART **3.3 V**. **Not** TX2, **not** RX0/GPIO3 |
| SDS011 RX | GPIO17 / TX2 | ESP32 TX2 → sensor RX (commands). Do not put sensor TX on TX2. **Not** TX0/GPIO1 |
| MQ135 AOUT | GPIO34 via divider | Analog, not UART. Neither RX2/TX2 nor RX0/TX0 |
| Beeper SIG | GPIO25 | 3-pin VCC/GND/SIG. 50 ms HIGH at boot; 50 ms on PIR rising edge |
| PIR D-SUN OUT | GPIO33 | 3-pin. Digital. Was reserved 27 — **use 33** |
| VEML7700 lux | GPIO21/19 (Wire1) | I²C **0x10** with BMP280. VCC 3V3. **Not fitted yet.** No extra GPIO |

Two I²C buses: OLED on Wire (GPIO5/4), BMP280 on Wire1 (GPIO21/19). UART2 is SDS011 only.
**Do not wire SDS011 (d011v2) to RX0/TX0** (GPIO3/GPIO1). Those pins are the CP2102 USB-UART used
by `task flash` / `task monitor`. Firmware uses `Serial2` on GPIO16/17 and will not move to UART0.

**MQ135 is analog, not UART, and not a CO₂ sensor.** Heater power is **5 V**, never `3V3`. Analog
belongs on GPIO34 after the divider. Operator bench (2026-08-14): **10 kΩ series** AOUT→GPIO34,
**20 kΩ** GPIO34→GND. GPIO sees **2/3** of AOUT. At 5 V AOUT the pin sits at **3.33 V** — at the
ESP32 3.3 V max there is **no headroom**. Firmware logs `mq135: raw=… gpio_mv=… aout_mv=…` (estimated
AOUT from the inverse ratio). If raw stays ~0, check AOUT/GND/5 V heater wiring. **Never apply 5 V
to GPIO34.** Serial also warns; do not label the reading `CO2` or `ppm`.

GPIO5 (OLED SDA) has an internal pull-up and wants idle-high at boot; that is usually compatible
with I²C. GPIO18 (AM2302) idle-high is OK (3.3 V flash voltage).

**VEML7700 lux** shares **Wire1** with BMP280 (SDA=GPIO21, SCL=GPIO19), I²C **0x10**, VCC **3V3**.
The part is **not fitted yet**: boot logs `veml7700: not found (ok until fitted)` and the OLED shows
`-- lx` on the hPa line. When present: serial `veml7700: lux=…` and e.g. `1013 hPa   123 lx`.
**No microphone. No clap.** GPIO22 and GPIO35 are unused.

## Layout

| Path | Role |
| --- | --- |
| `include/atmosmesh/` | Shared headers, product metadata and host-testable contracts |
| `src/products/atmosmesh_v1.cpp` | AtmosMesh v1 composition root; existing ESP32 runtime moved without behavior changes |
| `src/products/atmosmesh_grove_v1_5.cpp` | Thin AtmosMesh Grove v1.5 composition root |
| `src/display_text.cpp` | Host-testable OLED string clipping (128×64 / 128×32 pages) |
| `src/oled_profile.cpp` | Host-testable controller/geometry/COM selection (SSD1306 vs SH1106) |
| `src/oled_address.cpp` | Host-testable SSD1306 address selection (0x3C then 0x3D) |
| `src/bmp_address.cpp` | Host-testable BMP280 address pick |
| `src/am2302_frame.cpp` | Host-testable AM2302 checksum/parse |
| `src/sds011_frame.cpp` | Host-testable SDS011 `AA C0 … AB` checksum/parse |
| `src/i2c_bus.cpp` | ESP32 I²C scan |
| `src/mq135_scale.cpp` | Host-testable ADC→mV and 2/3-divider inverse (never CO₂) |
| `src/digital_edge.cpp` | Host-testable PIR debounce + serial labels |
| `src/veml7700_text.cpp` | Host-testable VEML7700 0x10 / lux OLED+serial formatters |
| `src/mqtt_contract.cpp` | Host-testable MQTT topics, state JSON, HA discovery payloads |
| `src/mqtt_session.cpp` | Host-testable reconnect backoff and publish sequencing |
| `src/mqtt_runtime.cpp` | ESP32-only async Wi-Fi + `esp_mqtt` (excluded from native) |
| `src/grove_mqtt_runtime.cpp` | Thin ESP8266WiFi/PubSubClient Grove transport (excluded from native) |
| `include/atmosmesh/product_profile.hpp` | Host-tested identity and explicit pin/geometry metadata for both products |
| `src/grove_status.cpp` | Shared, host-tested Grove missing/value/health formatting |
| `src/grove_visual_diagnostic.cpp` | Host-tested temporary OLED-fill and LED-cycle policy/logging |
| `src/rc_light.cpp` | Host-tested cooperative RC discharge/time-to-high policy |
| `src/soil_sampler.cpp` | Host-tested cooperative active-low power/sample/fail-off policy |
| `src/status_led.cpp` | Host-tested health/color/polarity mapping |
| `include/atmosmesh/secrets.hpp.example` | Copy to gitignored `secrets.hpp` for Wi-Fi/MQTT |
| `test/test_native/` | Unity sensor/OLED tests (`pio test -e native`) |
| `test/test_mqtt/` | Unity MQTT contract/session tests |

## MQTT / Wi-Fi credentials for both products

Preferred: put secrets in a **gitignored** `.envrc` at the main checkout (see `.envrc.example`):

```bash
export WIFI_SSID="your-ssid"
export WIFI_PASSWORD="your-wifi-password"
export MQTT_HOST="kum3-lan-address"
export MQTT_PORT="1883"
export MQTT_USER="homeassistant"
export MQTT_PASSWORD="from-kumulus-sops"
```

Then `direnv allow` and use `task build-v1`, `task build-v1-5`, `task build-room`, or
`task build-all` (and the matching
reviewed flash command only when authorized). Both product build/flash tasks run
`scripts/gen-secrets-from-env`, which writes gitignored
`firmware/include/atmosmesh/secrets.hpp` (also works from a git worktree by reading the
main-checkout `.envrc`).

Alternative: copy `include/atmosmesh/secrets.hpp.example` → `secrets.hpp` by hand.
Without Wi-Fi + MQTT credentials, either image still samples sensors and drives the OLED;
networking is skipped. Topics and HA discovery are in `docs/architecture.md` (D-007/D-013).

## Bluetooth mouse jiggler

The standalone C3 OLED image is documented in [jiggler.md](../docs/jiggler.md).
Build with `task build-jiggler`; it replaces the sensor-station application on that board.

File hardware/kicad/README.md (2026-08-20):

# AtmosMesh bench station — KiCad PCB

A 2-layer, all-through-hole carrier board for the **bench** revision: an ESP32-WROOM-32 DevKit sits
in two 1×15 sockets, the three 3.3 V sensors get proper connectors, and the future 5 V sensors get
connectors in a visually and electrically separated block. **No mains on this board** — the AC/DC
module stays off-board and enclosed ([`docs/hardware/power.md`](../../docs/hardware/power.md)).

Board outline is **139 × 58 mm**, 1.6 mm, 2 copper layers, GND poured on both.

## Files

| Path | What it is |
| --- | --- |
| `atmosmesh-bench/atmosmesh-bench.kicad_pro` | Project file — open this one |
| `atmosmesh-bench/atmosmesh-bench.kicad_sch` | Single-sheet schematic (A3) with named nets |
| `atmosmesh-bench/atmosmesh-bench.kicad_pcb` | Board: placement, netlist, outline, keepout, GND pours |
| `atmosmesh-bench/atmosmesh.kicad_sym` | Project symbol library (all symbols, vendored) |
| `atmosmesh-bench/atmosmesh.pretty/` | Project footprint library (all footprints, vendored) |
| `atmosmesh-bench/sym-lib-table`, `fp-lib-table` | Point the project at those two libraries |
| `atmosmesh-bench/atmosmesh-bench-schematic.pdf` | Rendered schematic, for review without KiCad |

## Opening it

Written in **KiCad 9 file format** (`.kicad_sch` 20250114, `.kicad_pcb` 20241229,
`.kicad_sym` 20241209) and validated with **KiCad 10.0.5**. Opens in KiCad 9 and 10.

```sh
open -a KiCad hardware/kicad/atmosmesh-bench/atmosmesh-bench.kicad_pro
```

Every symbol and footprint is **vendored into the project** (`atmosmesh:*`), so nothing depends on a
global library table — the project opens, ERCs and DRCs identically on any machine. The geometry of
the standard parts is copied verbatim from the KiCad 10.0.5 stock libraries; only the ESP32 DevKit
socket is original.

## Authoritative pin map (operator, 2026-08-14)

This is the **rewired bench** map. It supersedes every earlier D2/GPIO18 arrangement.

| Function | ESP32 pin | Net | Socket pin | Connector |
| --- | --- | --- | --- | --- |
| OLED 0x3C I²C **SDA** (D-001) | **GPIO5** (D5) | `SDA_LCD` | U1.23 | J1.3 |
| OLED 0x3C I²C **SCL** (D-001) | **GPIO4** (D4) | `SCL_LCD` | U1.26 | J1.4 |
| OLED VCC / GND | — | `+3V3` / `GND` | U1.30 / U1.29 | J1.2 / J1.1 |
| BMP280 **SDA** | **GPIO21** | `SDA_SENS` | U1.20 | J2.4 |
| BMP280 **SCL** | **GPIO19** (D19) | `SCL_SENS` | U1.21 | J2.3 |
| BMP280 **CSB** → 3V3 (I²C mode) | — | `+3V3` | — | J2.5 |
| BMP280 **SDO** → GND (addr **0x76**) | — | `GND` | — | J2.6 |
| BMP280 VCC | — | `+3V3` | U1.30 | J2.1 |
| AM2302 / DHT22 **DATA** | **GPIO18** (D18) | `DHT_DATA` | U1.22 | J3.2 |
| AM2302 VDD / GND | — | `+3V3` / `GND` | — | J3.1 / J3.3 |
| SDS011 TXD → ESP32 RX2 | GPIO16 | `PM_TX` | U1.25 | J4.3 |
| SDS011 RXD ← ESP32 TX2 | GPIO17 | `PM_RX` | U1.24 | J4.4 |
| MQ135 analog out | — | `MQ_AOUT` | — | J5.3 → R2 |
| MQ135 divider output | GPIO34 (ADC1, input-only) | `MQ_ADC` | U1.4 | R2/R3 |
| DevKit `VIN`, through JP1 | — | `ESP_VIN` | U1.15 | JP1.2 |
| Beeper **SIG** | **GPIO25** | `BEEP_SIG` | U1.8 | J_BEEP.3 |
| Beeper VCC (3V3 default, JP_BEEP → +5V) | — | `BEEP_VCC` | — | J_BEEP.1 / JP_BEEP.2 |
| PIR D-SUN **SIG** (digital in, **not 27**) | **GPIO33** | `PIR_OUT` | U1.7 | J_PIR.3 |
| PIR VCC (3V3 default, JP_PIR → +5V for HC-SR501) | — | `PIR_VCC` | — | J_PIR.1 / JP_PIR.2 |
| VEML7700 lux **SCL** (shared sensor bus) | **GPIO19** | `SCL_SENS` | U1.21 | J_VEML.3 |
| VEML7700 lux **SDA** (shared sensor bus, addr 0x10) | **GPIO21** | `SDA_SENS` | U1.20 | J_VEML.4 |
| VEML7700 VCC / GND (3V3 only) | — | `+3V3` / `GND` | — | J_VEML.1 / J_VEML.2 |
| **GPIO2** | **GPIO2** | *no-connect* | U1.27 | — |

`R1` is the **10 kΩ pull-up from `DHT_DATA` to `+3V3`**. `R4`/`R5` are optional 4k7 pull-ups on the
sensor I²C bus, fitted as **DNP** because the GY-BMP280 breakout already carries pull-ups.

### Named nets

`+3V3` `+5V` `GND` `ESP_VIN` · `SDA_LCD` `SCL_LCD` · `SDA_SENS` `SCL_SENS` · `DHT_DATA` ·
`PM_TX` `PM_RX` · `MQ_AOUT` `MQ_ADC` · `LED_A` ·
`BEEP_VCC` `BEEP_SIG` · `PIR_VCC` `PIR_OUT`

Signals use **global labels**, so the board net names match the sheet exactly (no `/` prefix).
Deliberately unused pins carry no-connect flags and therefore appear as KiCad's
`unconnected-(…)` nets on the board — that is intended, not an omission.

### J7 — 3.3 V flying-lead harness

An alternative to the socket: bring the DevKit in on jumper wires if its pin order turns out to
differ from the assumption below. **Populate U1 or J7, never both.**

| 1 | 2 | 3 | 4 | 5 | 6 | 7 | 8 | 9 | 10 | 11 | 12 |
| --- | --- | --- | --- | --- | --- | --- | --- | --- | --- | --- | --- |
| +3V3 | GND | GPIO4 | GPIO5 | GPIO18 | GPIO19 | GPIO21 | GPIO16 | GPIO17 | GPIO34 | GND | +3V3 |

### Extras strip — J_BEEP / J_PIR / J_VEML (2026-08-14)

Live extras from the breadboard (`agent-context/extra-peripherals.md`), placed in their own silk
box at the right board edge. `J_BEEP` and `J_PIR` are **1×3, pin order VCC / GND / SIG**; SIG is
always 3.3 V. `J_BEEP` (silk `BEEPER`, SIG=GPIO25) and `J_PIR` (silk `D-SUN PIR`, SIG=GPIO33 —
**not 27**) get a 3-pin VCC-select jumper (`JP_BEEP` / `JP_PIR`: 1=+3V3 default, 2=VCC out,
3=+5V — 5 V position only for 5 V-powered modules). `J_VEML` (silk `VEML7700 LUX`) is a 1×4
VCC/GND/SCL/SDA header on the **shared sensor I²C bus** (GPIO21/GPIO19, same bus as the BMP280;
VEML7700 addr 0x10, BMP280 0x76 — no clash), 3V3-only. The HC-20/DC-20 mic was removed from the
bench (2026-08-14); GPIO22 and GPIO35 are free. **No J_TFT** — the colour TFT was dropped.

## Electrical rules built into the board

1. **No 5 V on any ESP32 GPIO or on `+3V3`.** The 5 V nets touch only J6 (input), J4/J5 (future
   sensors), C1/C4, R6/D1, JP1, and pin 3 of the VCC-select jumpers JP_BEEP / JP_PIR. **Common GND
   only** — the two domains share nothing else. The jumpers feed module **power** only; SIG pins
   are always 3.3 V.
2. `+3V3` is an **output** of the DevKit's onboard LDO (U1.30). Nothing back-feeds it; the 3.3 V AC/DC
   spare must not be paralleled onto it.
3. **`JP1` stays OPEN on the bench.** It is the only path from the 5 V rail to the DevKit `VIN`.
   Close it only after the AC/DC module has been measured and enclosed, and **never together with
   USB** — USB/VIN coexistence on this board is unverified.
4. The 5 V block is fenced off on the silkscreen (`5V DOMAIN - NEVER TO A GPIO`) and sits in the
   bottom-right corner, physically away from the 3.3 V connectors.
5. `MQ135` on the schematic still shows `R2`/`R3` as 10 k / 15 k (3.0 V at 5.0 V in). The **live
   bench** (2026-08-14) is **10 kΩ series + 20 kΩ to GND** → 3.33 V at 5.0 V AOUT, **no GPIO
   headroom**. Firmware logs that warning. Never put 5 V on GPIO34, and never label MQ135 as CO₂.

### GPIO2

**GPIO2 is left free and unconnected** — it is a download strap and must stay unloaded so USB
flashing works without unplugging anything. There is no display jumper any more: the display (OLED,
D-001) moved to GPIO5/GPIO4, so the old "unplug to flash" workaround is gone. GPIO5 is also a
strap, but the module's I²C pull-up keeps it idle-high, which is the correct boot level.

## Before you fabricate: verify the DevKit pin order

The DevKit's silkscreen has **not been photographed yet**
([`docs/hardware/inventory.md`](../../docs/hardware/inventory.md) still lists the board name and pin
labels as unconfirmed). `U1` assumes the common DOIT-style 30-pin order, USB at the `+Y` end:

- **Left row, pins 1–15:** EN, GPIO36/VP, GPIO39/VN, GPIO34, GPIO35, GPIO32, GPIO33, GPIO25, GPIO26,
  GPIO27, GPIO14, GPIO12, GPIO13, GND, VIN
- **Right row, pins 16–30:** GPIO23, GPIO22, GPIO1/TX0, GPIO3/RX0, GPIO21, GPIO19, GPIO18, GPIO5,
  GPIO17/TX2, GPIO16/RX2, GPIO4, GPIO2, GPIO15, GND, 3V3

The board also carries `VERIFY DEVKIT PINOUT / GPIO2 FREE` on the front silkscreen. If the physical
board differs, fix `U1`'s pin names in `atmosmesh.kicad_sym` (the footprint pads are positional, so
only the symbol mapping changes) — or ignore the socket and wire through **J7**. Two row spacings are
provided: `ESP32_DevKit_1x15x2_P25.40mm` (placed) and `ESP32_DevKit_1x15x2_P22.86mm` (0.9 in
variants).

## State of the board — placed AND routed

The board is **fully routed**: all signal and power nets are on copper, GND is carried by the
poured zones on `F.Cu` and `B.Cu` (fills are saved in the file). Routing was generated
programmatically (grid router, 0.25/0.32 mm clearance, 0.4 mm signals / 0.6 mm power per the
netclasses) and verified with KiCad DRC: **0 violations at all severities, 0 unconnected items,
0 schematic parity issues**. 27 vias total; B.Cu carries short crossings only, so the ground
plane stays largely intact.

- Edge cuts, four M3 mounting holes, and a `User.Drawings` keepout marking the DevKit body plus
  the USB cable exit (the module deliberately overhangs the bottom edge so the cable clears the
  PCB).
- Every footprint carries a `path` link to its schematic symbol, so **Update PCB from
  Schematic** matches existing footprints instead of re-adding them.
- Review the routes in pcbnew before fabricating — they are machine-generated; eyeball the
  5 V / 3V3 domain boundaries and re-run DRC after any manual edit.

## Validation with kicad-cli

The macOS app bundle does **not** put `kicad-cli` on `PATH`. Use the absolute path:

```sh
export KCLI=/Applications/KiCad/KiCad.app/Contents/MacOS/kicad-cli
cd hardware/kicad/atmosmesh-bench

# version
"$KCLI" version

# Electrical rules check, all severities, non-zero exit if anything is found
"$KCLI" sch erc --severity-all --exit-code-violations \
  -o atmosmesh-bench-erc.rpt atmosmesh-bench.kicad_sch

# Design rules check, including schematic/PCB parity, with zones refilled in memory
"$KCLI" pcb drc --severity-all --schematic-parity --refill-zones \
  -o atmosmesh-bench-drc.rpt atmosmesh-bench.kicad_pcb

# Netlist and a reviewable schematic PDF
"$KCLI" sch export netlist -o atmosmesh-bench.net atmosmesh-bench.kicad_sch
"$KCLI" sch export pdf -o atmosmesh-bench-schematic.pdf atmosmesh-bench.kicad_sch
```

The PCB file is KiCad 10 format (the schematic still opens in KiCad 9 and 10). Zone fills are
saved in the file; refill with `B` in pcbnew after moving anything.

## Fabrication output — gerbers **and drill**

A gerber set without drill files is a board with **no holes**: JLCPCB's viewer shows a bare outline
and the order is rejected. `pcb export gerbers` never emits drill data — `pcb export drill` is a
**separate command** and is the step that is easy to forget. Always run both, and always upload the
zip that this recipe builds rather than hand-picking files.

```sh
export KCLI=/Applications/KiCad/KiCad.app/Contents/MacOS/kicad-cli
cd hardware/kicad/atmosmesh-bench
rm -rf gerbers && mkdir gerbers

# 1. Copper / mask / silk / paste / outline. Protel extensions are what JLCPCB expects.
"$KCLI" pcb export gerbers --check-zones \
  -l F.Cu,B.Cu,F.Paste,B.Paste,F.Silkscreen,B.Silkscreen,F.Mask,B.Mask,Edge.Cuts \
  -o gerbers atmosmesh-bench.kicad_pcb

# 2. Excellon drill — separate PTH/NPTH, plus a drill map and a hit report to review.
"$KCLI" pcb export drill --format excellon --drill-origin absolute \
  --excellon-units mm --excellon-zeros-format decimal --excellon-separate-th \
  --generate-map --map-format pdf \
  --generate-report --report-path gerbers/atmosmesh-bench-drill-report.rpt \
  -o gerbers atmosmesh-bench.kicad_pcb

# 3. One zip — this is the file to upload.
(cd gerbers && zip -j atmosmesh-bench-jlcpcb.zip \
  *.gtl *.gbl *.gts *.gbs *.gto *.gbo *.gtp *.gbp *.gm1 *.drl *.gbrjob)
```

Pass **no origin flags to either command**. Both default to the absolute page origin, so leaving
them alone is what keeps holes aligned to pads; `--use-drill-file-origin` on the gerber side would
plot copper against a different datum and produce the classic "holes offset from pads" rejection.

`gerbers/` is gitignored — it is regenerated output, not source.

### Verify before uploading

Existence of a `.drl` is not enough. Check all three:

1. **Hole counts** — read `atmosmesh-bench-drill-report.rpt`. Expect **132 plated** holes
   (including 27 × 0.4 mm, the vias) and **4 unplated** at **3.2 mm** — the M3 mounting holes. A
   missing NPTH file passes a naive existence check and still ships a board you cannot bolt down.
2. **Alignment** — the drill coordinates must sit inside the `Edge_Cuts` outline. Edge cuts span
   X `100.0 … 239.0`, Y `-118.0 … -60.0` mm; the four M3 holes sit at X `104.0`/`235.0`,
   Y `-64.0`/`-114.0` — 4 mm in from each edge. Drill near zero while the outline sits at an
   offset (or vice versa) means the origins diverged — see the flag warning above.
3. **File count** — the zip must hold **12** files: 9 gerbers, `PTH.drl`, `NPTH.drl`, `.gbrjob`.

Note that `.gbrjob` lists only the gerber layers; it never references the drill files, so it cannot
be used to confirm step 1.

### Results — KiCad 10.0.5, 2026-08-14

| Check | Result |
| --- | --- |
| `sch erc --severity-all` | **0 violations** (0 errors, 0 warnings) |
| `pcb drc --severity-all` | **0 violations** |
| Netlist ↔ PCB pad diff | **104 pins, 0 mismatches** |
| `pcb drc --schematic-parity` | **0 parity issues** |
| Unconnected items | **0** — fully routed |

## Follow-up: firmware matches — except the MQ135 divider constant

[`firmware/include/atmosmesh/pins.hpp`](../../firmware/include/atmosmesh/pins.hpp) now matches this
board's GPIO map (`kOledSdaGpio = 5`, `kOledSclGpio = 4`, `kSensorSclGpio = 19`,
`kAm2302DataGpio = 18`, SDS011 on GPIO16/17, MQ135 on GPIO34). J1 is the **OLED** header
(D-001); the historical `SDA_LCD`/`SCL_LCD` net names were kept to avoid churning the netlist.

One deliberate divergence remains: **R3 is 15 kΩ on this board** (10 k/15 k divider → 3.0 V max on
GPIO34), while firmware `kMq135GndOhms = 20000` matches the **live breadboard's** 10 k/20 k
divider (3.33 V at 5 V AOUT — no headroom). When this carrier board replaces the breadboard, set
`kMq135GndOhms = 15000` in the same change — see `agent-context/INBOX.md`.

## Provenance

Standard part geometry is copied from the KiCad 10.0.5 stock libraries (`Connector_Generic`,
`Connector`, `Device`, `Mechanical`, `power`, `Connector_PinHeader_2.54mm`, `Resistor_THT`,
`Capacitor_THT`, `LED_THT`, `TerminalBlock_Phoenix`, `MountingHole`) into the project libraries, with
3D-model references dropped. The ESP32 DevKit socket symbol and its two footprints are original —
KiCad ships no 30-pin ESP32 DevKit part. The initial geometry was laid out programmatically; from
here on **the KiCad files are the source of truth** and should be edited in KiCad.

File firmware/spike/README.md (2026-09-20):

# AtmosMesh Aura — one-day bring-up spike

**This is not the product and it is not a second firmware.** It is a throwaway ESPHome
configuration whose only job is to answer, in one day and with no C++ written, five questions that
the [Aura design](../../docs/design/atmosmesh-aura.md) otherwise leaves open until story AU-09.

Chosen by the operator on 2026-09-20 in response to the
[adversarial review](../../agent-context/inbox/2026-09-20-aura-adversarial-review.md), whose
verdict was BLOCK. The review's CRITICAL C3 was that ESPHome had never been evaluated, and an
argument about it cannot be settled by more argument. This spike settles it with a board.

Delete this directory once the questions below have answers recorded in `inventory.md`.

## What it answers

| # | Question | Otherwise answered at | How this answers it |
| --- | --- | --- | --- |
| Q1 | Which display controller is fitted, ILI9341 or ST7789? | AU-01 | A full-width RGB test card. Geometry and colour identify the part empirically |
| Q2 | Does the CN1 I²C bus work, and do all three sensors ACK? | AU-02 | `scan: true` prints every responding address at boot |
| Q3 | How bad is the self-heating offset? | **AU-09** | A live template sensor showing AHT20 (on the hot gas module) minus BME280 (on the pigtail) |
| Q4 | Is typing a password on resistive touch tolerable for a gift? | AU-05 | An LVGL keyboard and text field. A human types a real password and judges |
| Q5 | Is ESPHome's LVGL good enough to skip seven stories of C++? | never | You look at it |

Q3 and Q5 are the valuable ones. Q3 is the risk §4.1 calls *"a broken gift"* and the plan does not
test until story nine. Q5 is the BLOCK.

## Running it

ESPHome is **not** part of this repo's toolchain and this spike does not make it one. It is
installed in the workspace tooling directory alongside PlatformIO:

```bash
# one-off, if the venv is not there yet
python3 -m venv /home/koni/Projects/PlatformRelay/.tooling/python/esphome
/home/koni/Projects/PlatformRelay/.tooling/python/esphome/bin/pip install esphome

# validate the config without a board
.tooling/python/esphome/bin/esphome config firmware/spike/aura-bringup.yaml

# flash over USB — use ONE of the two USB sockets, never both
.tooling/python/esphome/bin/esphome run firmware/spike/aura-bringup.yaml
```

**Before flashing, take the stock backup seriously.** Unit 1's is already at
`PlatformRelay/.tooling/firmware-backups/esp32-2432s028_20500d34463c_stock-factory_2026-09-19.bin`.
If you use the *other* unit, back it up first — its MAC is not yet recorded anywhere.

Run it **once with no Wi-Fi in range or the AP unjoined.** That is requirement G4, and the sensors
and display must work anyway. If they do not, that is a finding.

## Wiring for the spike

Only the CN1 4-pin header is used. Nothing here needs 5 V and nothing has a fan.

| CN1 pin | To |
| --- | --- |
| GND | both sensor modules' GND |
| GPIO27 | both modules' SDA |
| GPIO22 | both modules' SCL |
| 3V3 | both modules' VIN/VCC |

Put the **BME280 at the far end of the pigtail**, as physically distant from the board as the cable
allows, and leave the **ENS160+AHT20 module wherever is convenient** — the point of Q3 is to measure
the difference between a sensor in still, warm air and one out in the room.

Expected I²C scan: `0x38` (AHT20, fixed), `0x52` or `0x53` (ENS160), `0x76` (BME280, SDO low).
A missing address is a wiring or pull-up problem, not a dead sensor. The breakouts carry their own
10 kΩ pull-ups, so do not add more until a scan has actually failed.

## If the display stays black or wrong

In order, because the cheap checks come first:

1. **Blank, backlight on** — the panel is being lit but not addressed. Suspect the SPI pin map
   before anything else; it is community reference, not measured.
2. **Photographic-negative colours** — uncomment `invert_colors: true`.
3. **Garbled, shifted, or a dead band at one edge** — switch `model: ILI9341` to `model: ST7789V`.
   The dual USB sockets on these units point that way, and it is the fault the `cyd-dashboard`
   firmware already showed on this board.
4. **Taps land in the wrong place** — expected. Adjust the `calibration:` block and record the
   numbers; the product will need them stored per unit regardless.

## Record the answers here, then in `inventory.md`

Fill this in as you go. An empty cell is an honest answer; a guessed one is not.

| Question | Result | Notes |
| --- | --- | --- |
| Q1 display controller | | ILI9341 / ST7789V, and whether `invert_colors` was needed |
| Q1 which unit | | MAC, so this is attributable to a board |
| Q2 I²C addresses seen | | verbatim from the boot log |
| Q2 pull-ups needed? | | were the on-module 10 kΩ enough |
| Q3 **offset, AHT20 − BME280** | | after ≥ 30 min warm, steady state. **This is the AU-09 number** |
| Q3 BME280 vs a real thermometer | | the offset that actually matters to a recipient |
| Q4 typing verdict | | tolerable / irritating / unacceptable as a gift |
| Q4 touch calibration values | | the four numbers that worked |
| Q5 LVGL verdict | | is this close enough to skip the bespoke build |
| ENS160 warm-up observed | | how long until TVOC/AQI stopped being nonsense |
| LVGL `buffer_size` that worked | | **direct input to the RAM budget the review says is missing** |
| Flash size of the built image | | ESPHome prints it. Compare against a 1.28 MB OTA slot |

## What this spike deliberately does not do

- **No MQTT, no Home Assistant, no credentials.** There is nothing to leak from this file, and the
  fleet broker password must not appear in it — see D-038 for the decision about the *product*.
- **No LDR reading.** ESP32 errata 3.11: sampling ADC1 briefly pulls GPIO36/39 low, and those are
  the touch IRQ and MISO. Mixing that in would confound Q4. Test night-dimming separately, after
  the touch verdict is in.
- **No controller ID-register read.** ESPHome cannot do it, which is itself a small finding for Q5.
  Empirical identification is good enough to unblock the design; AU-01 can still read the register
  properly if the bespoke route wins.
- **It does not settle the flash and RAM budget.** It gives two real data points — a working
  `buffer_size` and an image size — where the design currently has estimates.

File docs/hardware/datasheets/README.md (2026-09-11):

# Datasheets

Manufacturer PDFs retrieved on **2026-08-14** for the AtmosMesh planned bill of materials.
Use these, not vendor-blog summaries, when comparing voltages, logic levels, and current.

Chip-level sheets describe the **silicon**. Breakout modules (GY-BMP280, 4-pin OLED, MQ135
board) add regulators, pull-ups, and pin order that these files cannot confirm. RLS-01 photos
still win for connector orientation.

Start with [spec-comparison.md](../spec-comparison.md).

## Files

| File | Part | Issuer | Document |
| --- | --- | --- | --- |
| [4duino-sensorkit-40-in-1-manual.pdf](4duino-sensorkit-40-in-1-manual.pdf) | 4duino SensorKit 40 in 1 | 4duino | Retained kit manual; exact edition and publication date are not stated in the vault record |
| [espressif-esp32-wroom-32.pdf](espressif-esp32-wroom-32.pdf) | ESP32-WROOM-32 module (ESP32-D0WDQ6, 4 MB flash) | Espressif | Datasheet v3.7, NRND |
| [espressif-esp32-soc.pdf](espressif-esp32-soc.pdf) | ESP32 series SoC | Espressif | Series datasheet v5.3 |
| [silabs-cp2102.pdf](silabs-cp2102.pdf) | CP2102/9 USB-UART | Silicon Labs | CP2102/9 data sheet |
| [nova-sds011.pdf](nova-sds011.pdf) | SDS011 laser PM sensor | Nova Fitness | Specification V1.3 |
| [aosong-am2302-dht22.pdf](aosong-am2302-dht22.pdf) | DHT22 / AM2302 | Aosong (SparkFun copy) | DHT22 product sheet |
| [aosong-am2302.pdf](aosong-am2302.pdf) | AM2302 wired module | Aosong (Adafruit copy) | AM2302 product sheet |
| [bosch-bmp280.pdf](bosch-bmp280.pdf) | BMP280 pressure sensor | Bosch Sensortec | BST-BMP280-DS001-26 |
| [winsen-mq135.pdf](winsen-mq135.pdf) | MQ135 semiconductor gas sensor | Winsen | Manual v1.4 |
| [solomon-ssd1306.pdf](solomon-ssd1306.pdf) | SSD1306 OLED controller | Solomon Systech | Candidate for the 4-pin OLED |
| [sino-wealth-sh1106.pdf](sino-wealth-sh1106.pdf) | SH1106 OLED controller | Sino Wealth | Candidate for the 4-pin OLED |
| [hi-link-hlk-ld2410s-user-manual.pdf](hi-link-hlk-ld2410s-user-manual.pdf) | HLK-LD2410S 24 GHz low-power presence radar | Shenzhen Hi-Link | User manual V1.3 (retrieved 2026-09-04) |
| [hi-link-hlk-ld2410s-serial-protocol.pdf](hi-link-hlk-ld2410s-serial-protocol.pdf) | HLK-LD2410S | Shenzhen Hi-Link | Serial communication protocol V1.00, 2024-08-23 (retrieved 2026-09-04) |
| [hi-link-hlk-ld2410s-operation-guide.pdf](hi-link-hlk-ld2410s-operation-guide.pdf) | HLK-LD2410S | Shenzhen Hi-Link | Operation Guide 1.0: wiring to a CH340 board, default report, health check by command, tool FAQ (retrieved 2026-09-05) |

### HLK-LD2410S — what the manual settles (read 2026-09-04)

Table 2-1 and Table 3-2 of the user manual, confirmed identical in section 1 of the protocol
document:

| Fact | Value | Where |
| --- | --- | --- |
| Supply | 3.0–3.6 V, typ. 3.3 V, on J2 pin 1 `3V3` | Table 2-1, Table 3-2 |
| Current | average 0.04 / 0.12 / 0.6 mA (min / typ / max, "office scene"); the tool screenshots on page 4 show peaks near 118 mA | Table 2-1, section 2 |
| J2 pin order, as printed on the silkscreen | 1 `3V3`, 2 `GND`, 3 `OT1` = UART_TX, 4 `RX` = UART_RX, 5 `OT2` = "IO which is used to report the detection status: the high level is manned, and the low level is unmanned" | Table 3-2 |
| Logic level of `OT1`, `RX`, `OT2` | 0–3.3 V | Table 3-2 |
| J1 | SWD (GND, DIO, CLK, 3V3), not for the carrier | Table 3-1 |
| UART | 115200 baud, 1 stop bit, no parity, little-endian | Protocol section 2 |
| Minimal report frame (default) | `6E` · state (0/1 nobody, 2/3 somebody) · distance 2 bytes cm · `62` | Protocol Table 2-1 |
| Standard frame | head `F4 F3 F2 F1`, length, type `0x01`, state, distance, reserved, 64 energy bytes, tail `F8 F7 F6 F5` | Protocol Table 2-1 |
| Range | 10 m moving, 4 m stationary (wall-mounted at 1.5 m); refresh cycle 1–60 s configurable | Table 2-1 |
| Size, temperature | 20 × 20 mm, −40 to 85 °C; 10 dBm EIRP; 24–24.25 GHz | Table 2-1 |

**Consequence:** the module is a 3.3 V part end to end. It may be fed from a 3.3 V rail and its
`OT2` and `OT1` may drive a 3.3 V GPIO directly; nothing on it can put more than 3.3 V on a pin.
The presence pin is `OT2`, not `OT1` — `OT1` is the UART transmit line. Header pitch is not stated;
the photographs show a standard five-pin header, to be measured on the part.

### HLK-LD2410S — what the Operation Guide adds (read 2026-09-05)

- **Reports continuously by default**, not on change: the guide's serial-tool capture shows
  `6E 02 23 00 62` repeating at the report rate, with `6E 00 00 00 62` once the target leaves.
- **Health check:** send enable-configuration `FD FC FB FA 04 00 FF 00 01 00 04 03 02 01`;
  a working module replies and stops reporting for its 3 s configuration window. No reply on a
  correctly wired module is a hardware fault, not a mode.
- **No low-power switch, no jumper setting.** Every parameter (distances, report rates, response
  speed, no-one delay, thresholds) is written over UART. Nothing is selected by a pad.
- **The pads on the module** (wiring photo, page 1): three small footprints in a column between
  the chip and the header at the `RX`/`OT1` height, under the `HLK-LD2410S` silkscreen. On
  Hi-Link's reference unit the top and bottom carry a resistor and the middle one is empty, and
  that unit works — so those are the series links of the UART lines (and one option left open),
  and a missing or open link in the `OT1` position leaves the header pin floating. That is the
  first thing to meter on a module whose `OT2` works and whose `OT1` is silent (SP-01, first
  unit, 5 September 2026 — an open joint, fixed by reflowing the chip).
- **`OT1` is a weak driver** (first unit, measured): it reads LOW against the ESP32-C3's internal
  pull-down (~45 kΩ) and HIGH against its pull-up, and frames only decode with a pull-up on the
  line. Give it a pull-up (the host's internal one, or 10 kΩ to 3V3 on the carrier), never a
  pull-down.
- **A break on `RX` starts the stream.** After the host resets, the module sends two or three
  frames and then waits; holding its `RX` low for 200 ms makes it report continuously. It also
  answers any unparseable bytes on `RX` (boot-loader text, IDF logs) with the enable-config ACK,
  so keep the host's console off that pin.

## Provenance

| File | Retrieved from | SHA-256 |
| --- | --- | --- |
| 4duino-sensorkit-40-in-1-manual.pdf | Moved from the personal Obsidian vault on 2026-09-05; original download URL was not recorded | `811c922695b69c23fa92c742d6180df83bea8bc07c8282131a6d96513e2fcb53` |
| espressif-esp32-wroom-32.pdf | https://www.espressif.com/sites/default/files/documentation/esp32-wroom-32_datasheet_en.pdf | `a88f0a4376106498732580d8371009b4e6260358db2e9f3ab2deb0ee3e4fa5b6` |
| espressif-esp32-soc.pdf | https://www.espressif.com/sites/default/files/documentation/esp32_datasheet_en.pdf | `a7917e6b47528c9dcab06837a49d452e582751335797db879f1cf2d17cd29adf` |
| silabs-cp2102.pdf | https://www.silabs.com/documents/public/data-sheets/CP2102-9.pdf | `f025d9c738e4906544bbae493d5ff4a8d9746df247c92a329f4ed94799220e59` |
| nova-sds011.pdf | https://www-sd-nf.oss-cn-beijing.aliyuncs.com/官网下载/SDS011 laser PM2.5 sensor specification-V1.4.pdf | `4bf53f81b5eb5978c12e923d3e44f71782367c193c8d1033c6c4b007cd73bac7` |
| aosong-am2302-dht22.pdf | https://www.sparkfun.com/datasheets/Sensors/Temperature/DHT22.pdf | `c91441a385cdf58f5f0ae50b194f294d5d1f0faeaac9a010efacb7ecf21be448` |
| aosong-am2302.pdf | https://cdn-shop.adafruit.com/datasheets/Digital+humidity+and+temperature+sensor+AM2302.pdf | `e2827d9b41ae5e3d578580bc4f9c13865169a2ea6336f5a85d8d13d0279b2b43` |
| bosch-bmp280.pdf | https://www.bosch-sensortec.com/media/boschsensortec/downloads/datasheets/bst-bmp280-ds001.pdf | `473ff27d9df698b4757e36b36209f83b9f637b592c999d5fabe2a9453a488da6` |
| winsen-mq135.pdf | https://www.winsen-sensor.com/d/files/PDF/Semiconductor Gas Sensor/MQ135 (Ver1.4) - Manual.pdf | `a881e0d8211f87b40d271f44d73d1dd9d2f8e7c6d516bc7ee92265f1d12a19c1` |
| solomon-ssd1306.pdf | https://cdn-shop.adafruit.com/datasheets/SSD1306.pdf | `d55f875357de96d8c0e92153a389acc57e8bab4db7a0687f2e0bd3362f0036f6` |
| sino-wealth-sh1106.pdf | https://www.displayfuture.com/Display/datasheet/controller/SH1106.pdf | `d872cf078afa1b3df7412bbd6f7aac3aa3db3236f747096d898df28c0b8af2cc` |
| hi-link-hlk-ld2410s-user-manual.pdf | Hi-Link's official Drive folder for the LD2410S (linked from https://www.hlktech.net/index.php?id=1176), file id `1eX8C0SujX_pARyRFToD1Ohh2PwLNKFlS`, fetched via https://drive.usercontent.google.com/download?id=1eX8C0SujX_pARyRFToD1Ohh2PwLNKFlS&export=download. The tinytronics mirror was behind a bot check | `6c4c2fd31c9c53fbc2d8d2552614cd997a559079ab38896080780d50603369a6` |
| hi-link-hlk-ld2410s-serial-protocol.pdf | Same folder, file id `1LFyf6w9nOxW7b5z0rg5I3mPkk2KjQviE`, fetched via https://drive.usercontent.google.com/download?id=1LFyf6w9nOxW7b5z0rg5I3mPkk2KjQviE&export=download | `8d120eccdb3b0a03ca3eaaa92c95d4f01623ee429d038ea1eeb2880908238e98` |
| hi-link-hlk-ld2410s-operation-guide.pdf | Same folder ("HLK-LD2410S Operation Guide1.0 .pdf"), downloaded by the operator on 2026-09-05 | `1839747e9098ed91d1f12f5aa77db2daa5fba598561d96ca9b75a3ad5275159a` |

The SDS011 URL is labelled V1.4; the PDF itself is **Version V1.3** (2015-10-09). Treat it as V1.3.

Adafruit’s file named `DHT22.pdf` is the **AM2303** sheet (DS18B20 temperature element, −40…125 °C). It was discarded. Do not use it for this project.

## Not included

- ESP32 hardware design guidelines PDF — Espressif’s former direct PDF URL now returns HTML.
- Exact ESP32 **devboard** schematic — USB probe identified a CP2102 + ESP32-D0WDQ6, not a named DevKit revision.
- GY-BMP280 / OLED / MQ135 **breakout** schematics — unknown until photos.
- 5 V bench supply — not selected.

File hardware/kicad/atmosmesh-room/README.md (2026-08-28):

# AtmosMesh Room carrier — provisional design

**DO NOT ENERGISE THIS BOARD YET.** The controller and every module connector order are now
identified, but no supply voltage or output swing has been measured on the 5 V modules. This project is a protected, reviewable starting point, not a wiring
approval.

The controller is the **ideaspark ESP32 1.14 inch TFT LCD board** (ESP32-WROOM-32), confirmed from
[`docs/hardware/ideaspark-esp32-tft-pinout.png`](../../../docs/hardware/ideaspark-esp32-tft-pinout.png).
Its 30 pins and their order are therefore no longer provisional: pads 1–15 are the left column and
16–30 the right column, both counted from the USB/button end. What remains unmeasured is the
physical **row spacing**: 25.4 mm is still an assumption, so MEASURE THE ROW SPACING before
cutting a socket or committing a hole pattern.

**The integrated display is SPI, not I²C.** It occupies GPIO23 (MOSI), GPIO18 (SCLK), GPIO15 (CS),
GPIO2 (DC), GPIO4 (RST) and GPIO32 (backlight). GPIO21/22 carry no onboard device, so the carrier
supplies the only I²C pull-ups it has.

## Files

| File | Purpose |
| --- | --- |
| `atmosmesh-room.kicad_pro` | KiCad 10 project; open this file |
| `atmosmesh-room.kicad_sch` | Reviewable electrical contract |
| `atmosmesh-room.kicad_pcb` | **Parked.** Kept only as a netlist/silkscreen cross-check — not the build target |
| `perfboard.md` | **The build target**: 31×27 hole plan, orientation rules and build order |
| `atmosmesh-room-perfboard-drawing.svg` | Zoomable front, mirrored back and logical wiring planning drawing |
| `atmosmesh-room-perfboard-drawing.png` | Rendered preview of the planning drawing |
| `validate_room_perfboard.py` | Deterministic structural check on the perfboard plan |
| `room.pretty/`, `fp-lib-table`, `sym-lib-table` | Local THT library contract |
| `BOM.csv` | Values, fitting policy and verification notes |
| `wiring.md` | Connector contract and staged pre-power checks |
| `validate_room_carrier.py` | Deterministic structural safety check |
| `generate_project.py` | Reproducible project generator; KiCad source remains editable |
| `requirements-generator.txt` | Pinned generator-only Python dependency |

## Safety architecture

- ESP32 GPIO and `3V3` must **never receive 5 V**.
- **Never wire GPIO23, 18, 15, 2, 4 or 32** — the dev board's own TFT drives them. GPIO12 is the
  flash-voltage strap (high at boot can stop the board starting) and GPIO1/GPIO3 are the CP2102
  USB-UART used by `task flash` and `task monitor`. `generate_project.py` refuses to emit a net on
  any of them and `validate_room_carrier.py` fails if one appears.
- GPIO21/SDA and GPIO22/SCL reach the external sensor branch through 330 Ω series resistors. Those
  resistors limit fault current and damp edges; they are not a measurement noise source.
- `R_PU_SDA` and `R_PU_SCL` (3.3 kΩ to 3.3 V) are the bus pull-ups. They are required because the
  display is SPI: nothing on the controller board pulls I²C up. They sit on the sensor side of the
  330 Ω resistors so the series resistance stays a fault limit rather than part of the pull-up
  divider. With both breakouts populated the parallel result is roughly 2.0 kΩ, about 1.6 mA at
  3.3 V, inside the I²C 3 mA sink limit, so they stay fitted rather than DNP. Every resistor value
  on this board is justified in `wiring.md`'s sizing table.
- Both sensors receive direct 3.3 V and local 220 nF decoupling. There is deliberately no diode or
  resistor in a sensor supply: a breakout's pull-ups reference its own VDD, so dropping sensor VDD
  drags the pull-ups down with it and buys nothing, while adding a droop path under the SHT41's
  measurement current bursts. The build uses 100 nF for `C1`, `C3`, `C4`
  and `C7` — the confirmed ceramic stock value, inside D-022's own 47–220 nF range.
- The confirmed five-pin VEML7700 connector is `VIN`, `3Vo`, `GND`, `SCL`, `SDA`: `VIN` receives
  3.3 V and `3Vo` is regulator output and remains NC.
- PIR power can come only from a confirmed USB/5 V pin, through `JP_PIR_5V` which is **DEFAULT
  OPEN**, then a 1N5819. PIR OUT drives a 2N3904 through 10 kΩ; GPIO33 sees only the collector and a
  10 kΩ pull-up to 3.3 V. Motion logic is active-low.
- The buzzer is a confirmed Keyes 3-pin module, header order `S`/`VCC`/`−`. GPIO25 drives `S`
  directly through `R_BEEP_S` 100 Ω, active HIGH, exactly as AtmosMesh v1 drives the same part. The
  low-side NPN and flyback diode are gone because the transducer is **self-oscillating inside the
  can** — the breakout PCB carries no parts, so the middle `VCC` pin is a no-op and GPIO25 sources
  the whole operating current. The evidence is that v1 sounds this part with a bare 50 ms DC
  `digitalWrite(HIGH)`, which neither a piezo disc nor a passive coil can do. That type is inferred,
  not measured: one ohmmeter reading across `S` and `−` settles it, and `R_BEEP_S` is **never
  raised** — see the table in `wiring.md` before changing anything.
- `JP_5V_SRC` selects where `+5V_DOMAIN` comes from: the board's `VIN` (pins 1–2) or an external
  bench supply on `J_5V_EXT` (pins 2–3). A 3-pin header takes exactly one shunt, so the two sources
  can never be bridged back into the host's USB port. Use the external, current-limited supply for
  first power-up and whenever the SDS011 fan runs.
- The SDS011 takes 5 V through `JP_SDS_5V`, **DEFAULT OPEN**, with **no series diode**: its minimum
  is 4.7 V and a Schottky at fan current drops below that. Its UART is crossed — sensor TXD to
  GPIO16/RX2, GPIO17/TX2 to sensor RXD — each through a 1 kΩ series resistor that bounds a driver
  fight to about 3.3 mA. The generator refuses both a straight-through UART and a diode on that
  rail.
- Three indicator LEDs show which domains are live. `D_LED_SDS` and `D_LED_PIR` draw **through**
  their own default-open jumpers, so a lit LED is direct evidence that the jumper it reports on is
  closed. Use red or green: a blue or white LED's ~3.0 V forward drop leaves too little across
  `R_LED_3V3` on the 3.3 V rail.
- No Zener clamp is used. This is now positively evidenced rather than assumed: the Zener
  assortment in `docs/elektronik-inventar.md` is the 1N47xx series starting at **1N4733 = 5.1 V**,
  which clamps far too late to protect a 3.3 V GPIO. A 3.3 V part (1N4728) is not held.

## The build target is perfboard

The operator builds this by hand on a **31 × 27 hole** perfboard, so no board is fabricated. The
schematic is the electrical contract and [`perfboard.md`](perfboard.md) is the build plan.

`atmosmesh-room.kicad_pcb` is **parked**: it is still generated from the netlist and still carries
the safety silkscreen, which is why its checks remain in `validate_room_carrier.py`, but its
placement is not maintained as a fabrication candidate. Do not order it.

## Placement and routing state

The VEML7700 sits at a board edge and must be optically shielded from the TFT backlight. The SHT41 sits at
the opposite ventilated edge, away from the ESP32 regulator, PIR electronics and buzzer. The 5 V
PIR block is fenced at the right edge. The antenna clearance is marked on `User.Drawings` and silk;
its final copper keepout/overhang cannot be fixed until the exact board orientation is photographed.

Copper is intentionally unrouted because the Ideaspark row spacing and orientation, plus each
module connector order, are unverified. This prevents a plausible-looking provisional drawing
from being mistaken for a fabrication-ready board. Do not "finish the ratsnest" by assuming a
generic ESP32 DevKit image.

The complete net table, double-sided through-hole placement guidance, assembly order, unpowered
checks, staged commissioning and stop conditions are in [`wiring.md`](wiring.md).

## Validation

From this directory:

```sh
python3.12 -m venv .generator-venv
.generator-venv/bin/pip install -r requirements-generator.txt
.generator-venv/bin/python generate_project.py
python3 validate_room_carrier.py
kicad-cli sch erc --severity-all --exit-code-violations \
  -o atmosmesh-room-erc.rpt atmosmesh-room.kicad_sch
kicad-cli pcb drc --severity-all --schematic-parity --refill-zones \
  -o atmosmesh-room-drc.rpt atmosmesh-room.kicad_pcb
kicad-cli sch export pdf -o atmosmesh-room-schematic.pdf atmosmesh-room.kicad_sch
```

DRC reports the deliberately unrouted nets as unconnected; schematic parity must remain clean and
there must be no other DRC violation. Routing stays blocked until the exact physical parts are
verified.

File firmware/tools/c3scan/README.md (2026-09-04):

# c3scan — I²C pin-pair scanner for the ESP32-C3 SuperMini OLED

A standalone PlatformIO project (its own `platformio.ini`, independent of `firmware/`) that
flashes the ESP32-C3 SuperMini OLED board and reports which SDA/SCL pin pair answers and at which
addresses. Written for SP-01's open question 1 ("which GPIOs carry the OLED?") and kept because
it is the quickest way to prove a fresh SuperMini and a fresh sensor before they go on a carrier.

It is also the first ESP32-C3 build in this repository: `platform = espressif32` 7.1.0 with the
Arduino core 3.20017 and the RISC-V toolchain built it on 2026-09-04 (the SP-02 toolchain spike,
in effect).

## Use

From this directory, with a PlatformIO venv on `PATH` (the shared agent venv does not carry
PlatformIO; `uv venv && uv pip install platformio pip` in a scratch directory is enough):

```sh
pio run                      # build only
pio run -t upload            # flash over the board's native USB (/dev/ttyACM0)
pio device monitor           # 115200 baud; a scan pass prints every 15 s
```

The board enumerates as `Espressif USB JTAG/serial debug unit` (303a:1001) on `/dev/ttyACM0`.
That device belongs to `root:dialout`; the user flashing needs to be in `dialout` (log out and
in after `sudo usermod -aG dialout $USER`) or the port opened for the session
(`sudo chmod a+rw /dev/ttyACM0`).

## What it prints

Chip model, revision and MAC, then for each of the pin pairs `(5,6) (6,5) (4,3) (3,4) (7,10)
(10,7) (2,1) (1,2) (0,1) (1,0) (20,21) (21,20) (8,9) (9,8)` the addresses that ACK between
`0x08` and `0x77`, with the usual suspects named (`0x3C` OLED, `0x44` SHT4x, `0x10` VEML7700,
`0x76` BME/BMP280). With nothing plugged into the module the only expected hit is the on-board
OLED at `0x3C`; the pair it appears on is the answer to SP-01's open question 1.

## PlatformIO gotchas seen on 2026-09-04

- A venv created with `uv` has no `pip`; PlatformIO 6.x needs it to install `tool-esptoolpy`
  2.41100.x (a pip package now) and otherwise fails with `MissingPackageManifestError`. Fix:
  `uv pip install --python <venv>/bin/python pip`, delete `~/.platformio/packages/tool-esptoolpy`,
  run again.
- The build flags `-DARDUINO_USB_MODE=1 -DARDUINO_USB_CDC_ON_BOOT=1` are what make `Serial`
  talk over the board's native USB; without them the output goes to the unconnected UART0 pins.

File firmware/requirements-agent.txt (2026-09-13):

# Host-side ESP32 tools. Import name for pyserial is `serial`.
# Install into a venv, not with system python:
#   task bootstrap-agent-python
#   # or: python3.12 -m venv .venv && .venv/bin/pip install -r firmware/requirements-agent.txt
pyserial==3.5
esptool==5.4.0

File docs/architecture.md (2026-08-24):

# Architecture

## Product variants

AtmosMesh keeps the existing **AtmosMesh v1** ESP32 station entrypoint and full sensor/MQTT stack.
**AtmosMesh Grove v1.5** is the smaller ESP8266 variant (`atmosmesh-grove-0001` by default) with a
thin profiled entrypoint for its 128×32 OLED, BMP180, DHT11 and uncalibrated D7 RC light response.
The Grove root also composes a polarity-aware D0/D6 status LED and cooperative D1-switched raw
YL-38 ADC policy; neither adds calibrated moisture claims.
PlatformIO source filters keep target transports/runtimes separate, while measurement validity,
display decisions, MQTT identity/discovery/state formatting and reconnect sequencing are shared,
host-testable utilities. This does not claim the legacy ESP32 composition root is thin/profile-driven.

Both composition roots are explicitly named under `firmware/src/products/`; the ESP32 source was
moved there without behavior changes. Compile-time identity metadata now exists for both products,
while incremental ESP32 adoption remains migration work. The full proposal, alternatives and
version rules are in [ADR-0001](adr/0001-multi-product-firmware-composition.md).

Grove v1.5 has its own ID-based MQTT product contract and a thin ESP8266WiFi/PubSubClient transport;
hardware network validation remains pending. It does not inherit claims for ESP32-only SDS011,
MQ135, PIR, VEML7700 or beeper devices. YL-38 uses the operator-wired 2N3906 PNP high-side switch
and divided A0 raw input; runtime validation remains pending. MAX4466 is dropped.

## Context

The system has three independently testable boundaries:

1. **Device:** sensors, local display, validation, health, Wi-Fi, and MQTT publication.
2. **Messaging/platform:** broker, persistence, metrics ingestion, and service health.
3. **User experience:** Home Assistant entities, Grafana history, and alerting.

## Intended data flow

```text
Sensors -> validation -> device state -> OLED
                                  └-> MQTT state + availability
                                                    ├-> Home Assistant
                                                    └-> metrics bridge -> Prometheus -> Grafana
```

## Device power (station target)

See `docs/hardware/power.md` and decision D-005. One enclosed isolated 5 V rail feeds ESP32 `VIN`/`5V`
and 5 V sensors. The DevBoard LDO feeds 3.3 V logic and small 3.3 V loads. GPIOs are 3.3 V; 5 V
signals are not connected directly. Bench flashing stays on USB until that rail is enclosed and
measured.

## Device responsibilities

- Sample sensors independently; one failed sensor must not block the others.
- Carry value, unit, validity, and age as separate concepts.
- Never convert a missing value into numeric zero.
- Keep the local display useful while Wi-Fi or MQTT is unavailable.
- Reconnect with bounded backoff and publish MQTT Last Will availability.
- Avoid credentials in source-controlled files.

## MQTT contract (RLS-05)

Frozen identity (no room name in any topic — Home Assistant areas are assigned later):

| Piece | Value |
| --- | --- |
| Device id | `atmosmesh-v1` |
| Station id | `atmosmesh-0001` |
| State topic | `home/air/atmosmesh-0001/state` (JSON, not retained) |
| Availability | `home/air/atmosmesh-0001/availability` (`online` / `offline`, retained + LWT) |
| Discovery | `homeassistant/{sensor\|binary_sensor}/atmosmesh_0001/<object_id>/config` (retained) |
| Broker | LAN plain MQTT `:1883`, username `homeassistant`, no TLS (kumulus Mosquitto) |

State JSON includes `"id":"atmosmesh-0001"` and `"device":"atmosmesh-v1"`. Each reading is
`{value, unit, valid, age_ms}`; invalid readings omit `value` entirely. MQ135 publishes
`gas_index` (unit `index`) and optional `mq135_raw` — never `co2` / `ppm`. Lux is omitted until
a light sensor is fitted. Discovery configs are re-published on every MQTT connect because the
kumulus broker runs with persistence off.

Credentials live in a gitignored `.envrc` (see `.envrc.example`). Both canonical product build and
flash tasks run `scripts/gen-secrets-from-env` to materialise
`firmware/include/atmosmesh/secrets.hpp`. Without those credentials, sensors and OLED
still run; Wi-Fi/MQTT stay off.

### Grove v1.5 MQTT contract (D-013)

| Piece | Value |
| --- | --- |
| Product id | `atmosmesh-grove-v1.5` |
| Station id | `atmosmesh-grove-0001` |
| State topic | `home/air/atmosmesh-grove-0001/state` (JSON, not retained) |
| Availability | `home/air/atmosmesh-grove-0001/availability` (`online` / `offline`, retained + LWT) |
| Discovery | `homeassistant/sensor/atmosmesh_grove_0001/<object_id>/config` (retained) |

Grove state uses optional scalar keys `temperature_c`, `humidity_pct`, `pressure_hpa` and
`light_charge_us`, plus raw `soil_adc_raw`; invalid readings are omitted while valid numeric zero
remains publishable. Home Assistant discovery covers exactly those five entities and is replayed on
every connect. Light is
an **uncalibrated RC charge time** in `µs`, lower meaning brighter; it is never lux/illuminance or
percent. Both product builds use the same generated, gitignored secrets. Missing credentials or
network/broker loss leaves local sensing and OLED work active.
Soil is an uncalibrated ADC count with no moisture device class or percent claim. Pending state
survives earlier discovery/availability failures, including the optional soil value.

The shared session separates planning a state action from acknowledging transport acceptance.
PubSubClient acknowledgement follows its successful boolean result; ESP-MQTT acknowledgement
follows a nonnegative publish message ID (`0` is QoS 0 success, `-1` is failure). A failed publish
therefore remains pending for retry instead of being lost, while an accepted state is not emitted on
every firmware loop tick.

## Deployment responsibilities

- Declarative, reproducible configuration.
- Persistent configuration/history where required.
- Secrets provided outside committed manifests.
- Health checks appropriate to each workload.
- A stable broker address reachable from the home network without exposing it publicly by default.

## Out of scope for the MVP

- Mains control, open mains on the bench, or safety automation.
- Certified environmental or health monitoring.
- Battery optimization.
- Custom PCB.
- 480×320 local graphical UI.
- True CO₂ until a confirmed NDIR sensor is available.

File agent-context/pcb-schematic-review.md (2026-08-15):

# AtmosMesh bench — schematic/PCB fix list (other-session)

> ## ⚠️ VERIFIED INVALID in the PCB session (2026-08-14, later) — do not apply §1–§4
>
> The geometric premise of the blocking fixes is wrong. KiCad **symbol libraries store pin
> offsets y-up, while the schematic sheet is y-down**: a placed pin sits at `anchor_y − rel_y`,
> not `anchor_y + rel_y`. Re-deriving every attachment with the correct convention shows the
> labels this review calls "off-pin" or "reversed" sit **exactly on the intended pins** (e.g.
> `MQ_ADC` at y=119.38 = 129.54 − 10.16 = **U1.4 GPIO34**, not U1.12).
>
> Evidence, current files:
> - `kicad-cli sch erc --severity-error --severity-warning`: **0 errors, 0 warnings** on the
>   untouched sheet. (Applying §1's moves produces 6 errors/6 warnings — tested, then reverted.)
> - Netlist export diffed pin-by-pin against PCB pad nets: **89 pins, 0 mismatches** — schematic
>   and board already agree completely, including U1, J1–J7, JP1 and all passives.
> - Consequence: `Update PCB from Schematic` would be a no-op net-wise; the §"Hard rule" hazard
>   does not exist. Routing can proceed whenever the DevKit pinout photo lands.
>
> What was real and is now **done**: §2/§6 J1 identity — Value `LCD1602_I2C` → `OLED_I2C` in
> schematic and PCB, silkscreen `LCD1602` → `OLED 0x3C` (module SDA/SCL order still to be
> photo-verified before copper). §5 R3 divider: real divergence, decision logged in `INBOX.md`
> (board stays 10 k/15 k; firmware switches to 15000 when the carrier board replaces the
> breadboard — not before, the live breadboard is physically 10 k/20 k). The stale
> `hardware/kicad/README.md` firmware paragraph was rewritten.

**Date:** 2026-08-14 (re-read of current files; PCB has grown / been re-laid-out, still unrouted).
**Do not fabricate. Do not flash. Do not merge or commit KiCad.** This file is the work order.

**Files (read-only until the PCB session edits them in KiCad):**

| Path | Role |
| --- | --- |
| `hardware/kicad/atmosmesh-bench/atmosmesh-bench.kicad_sch` | Single sheet; KiCad 9 sch format (`20250114`) |
| `hardware/kicad/atmosmesh-bench/atmosmesh-bench.kicad_pcb` | Placement + net names; **KiCad 10** (`20260206`, pcbnew 10.0). Title block: signals intentionally unrouted. No `segment`/`via` traces. |
| `hardware/kicad/atmosmesh-bench/atmosmesh.kicad_sym` | Vendored symbols, including `ESP32_DevKit_V1_Socket` |
| `firmware/include/atmosmesh/pins.hpp` | Authoritative GPIO map (main). `.worktrees/atmosmesh-oled-u8g2` GPIO numbers **match**; only the OLED driver comment differs. |

**Live bench truth (operator 2026-08-14) — firmware already matches this:**

| Function | Wiring | Nets (intended) |
| --- | --- | --- |
| Mini OLED 0x3C | SDA=GPIO5, SCL=GPIO4, VCC=3V3 | `SDA_LCD`, `SCL_LCD`, `+3V3` |
| GY-BMP280 | SDA=21, SCL=19, CSB=3V3, SDO=GND | `SDA_SENS`, `SCL_SENS` |
| AM2302 | GPIO18 | `DHT_DATA` |
| SDS011 | sensor TX→GPIO16, GPIO17→sensor RX, **5 V on sensor VCC only** | `PM_TX`, `PM_RX`, `+5V` |
| MQ135 | AOUT 10 kΩ series to GPIO34, 20 kΩ to GND (firmware `10000`/`20000`) | `MQ_AOUT`, `MQ_ADC` |
| GPIO2 | free (download strap) | no-connect on U1.27 |
| UART0 | USB/CP2102 only | U1.18 TX0 / U1.19 RX0 no-connect |
| 5 V | never on a GPIO | 5 V block only: J6, J4, J5, C1/C4, R6/D1, JP1 |

`hardware/kicad/README.md` still says firmware carries the *old* LCD/GPIO18 map. That paragraph is **stale**. `pins.hpp` on main is the live map.

---

## Hard rule — Do **not** Update PCB from Schematic

Until every U1 (and J1–J7) **symbol pin number** carries the net that the **pad of the same number** should have, **Tools → Update PCB from Schematic** will smash the board.

Today the **PCB pad nets follow the intended pinout** (README / silkscreen). The **schematic wires follow geometry as if pin 1 were at the bottom of each `Conn_01xN` / as if U1 EN/GPIO23 were at the VIN/3V3 end**. KiCad `Conn_01xN` and `ESP32_DevKit_V1_Socket` put **pin 1 at +Y (top of the symbol)**.

Evidence that the board is still the “good pad-number” side:

- U1 pad 4 = `MQ_ADC`, pad 20 = `SDA_SENS`, pad 21 = `SCL_SENS`, pad 22 = `DHT_DATA`, pad 23 = `SDA_LCD`, pad 24 = `PM_RX`, pad 25 = `PM_TX`, pad 26 = `SCL_LCD`, pad 27 unconnected (GPIO2), pad 29 `GND`, pad 30 `+3V3`.
- J2 pads: 1 `+3V3`, 2 `GND`, 3 `SCL_SENS`, 4 `SDA_SENS`, 5 `+3V3` (CSB), 6 `GND` (SDO).
- J1 pads: 1 `GND`, 2 `+3V3`, 3 `SDA_LCD`, 4 `SCL_LCD`.
- J4 pads: 1 `+5V`, 2 `GND`, 3 `PM_TX`, 4 `PM_RX`.

Fix the **schematic attachments** (move wires/labels onto the correct pin electrical points, or mirror/re-number). Then ERC. Only then update the PCB — and only if a pad net actually disagrees. Prefer **never** letting a bulk update rewrite U1.

If you only need copper: **route the existing PCB nets**; do not re-import.

---

## Blocking fixes (do these first)

Root cause for 1–4: labels were placed as if **pin 1 = bottom** (`−Y`). KiCad symbols use **pin 1 = top** (`+Y`). Several “last” pins landed **2.54 mm off the symbol**, so they are not on any pin (ERC can still be quiet if the orphan is a power symbol).

### 1. U1 — wires sit on the wrong pin numbers

Symbol `atmosmesh:ESP32_DevKit_V1_Socket` at `(95.25, 129.54)`. Electrical X: left `77.47`, right `113.03`. Pin 1 EN is at **+Y** (`y=147.32`), pin 15 VIN at **−Y** (`y=111.76`).

| Net (label) | Attached today (symbol pin / name) | Must attach to |
| --- | --- | --- |
| `ESP_VIN` | **U1.1 EN** (`y=147.32`) | **U1.15 VIN** (`y=111.76`) |
| `GND` (left) | **U1.2 GPIO36/VP** (`y=144.78`) | **U1.14 GND** (`y=114.30`) |
| `MQ_ADC` | **U1.12 GPIO12** (`y=119.38`) | **U1.4 GPIO34** (`y=139.70`) |
| `+3V3` (right) | **U1.16 GPIO23** (`y=147.32`) | **U1.30 3V3** (`y=111.76`) |
| `GND` (right) | **U1.17 GPIO22** (`y=144.78`) | **U1.29 GND** (`y=114.30`) |
| `SDA_SENS` | **U1.26 GPIO4** (`y=121.92`) | **U1.20 GPIO21** (`y=137.16`) |
| `SCL_SENS` | **U1.25 GPIO16/RX2** (`y=124.46`) | **U1.21 GPIO19** (`y=134.62`) |
| `DHT_DATA` | **U1.24 GPIO17/TX2** (`y=127.00`) | **U1.22 GPIO18** (`y=132.08`) |
| `SDA_LCD` | U1.23 GPIO5 (`y=129.54`) | **keep** (only signal that already matches) |
| `PM_RX` | **U1.22 GPIO18** (`y=132.08`) | **U1.24 GPIO17/TX2** (`y=127.00`) |
| `PM_TX` | **U1.21 GPIO19** (`y=134.62`) | **U1.25 GPIO16/RX2** (`y=124.46`) |
| `SCL_LCD` | **U1.20 GPIO21** (`y=137.16`) | **U1.26 GPIO4** (`y=121.92`) |

Leave **no-connect** on: EN, VP/VN, GPIO35–13, GPIO23/22, **GPIO1/TX0**, **GPIO3/RX0**, **GPIO2**, GPIO15. Today TX0/RX0/GPIO2 happen to be NC — keep them NC after the move.

**How:** select the wire + global label on each U1 pin and move them 1:1 onto the pin of the **name** in the third column. Do not rename pads in the footprint. Do not “fix” this by swapping pin numbers inside the symbol unless you also change the footprint pad order (you must not).

After this, a netlist pin-number export must match the PCB pad table above.

### 2. J1 — `SCL_LCD` is off-pin; header still named LCD1602

`J1` `Conn_01x04` at `(185.42, 39.37)`. Pin 1 at `+2.54` (`y=41.91`), pin 4 at `−5.08` (`y=34.29`).

| Pin | Intended | Schematic today |
| --- | --- | --- |
| J1.1 | `GND` | **`SDA_LCD`** (`y=41.91`) |
| J1.2 | `+3V3` | `+3V3` (`y=39.37`) — only this matches by accident |
| J1.3 | `SDA_LCD` | **`GND`** (`y=36.83`) |
| J1.4 | `SCL_LCD` | **no connection** — label `SCL_LCD` sits at `y=44.45` (**2.54 mm above pin 1**) |

PCB pads already have GND / 3V3 / SDA_LCD / SCL_LCD on 1–4. **Do not update PCB.** Move the four attachments onto pins 1–4.

**Rename** Value `LCD1602_I2C` → **`OLED_I2C`** (or `SSD1306_SH1106`). Silkscreen `LCD1602` on the PCB (`gr_text` near J1) must become **OLED**. D-001: 1602 is spare, not the station display.

**OLED pin order (GND-VCC-SDA-SCL vs GND-VCC-SCL-SDA):** J1 and the PCB silkscreen are **GND, 3V3, SDA=5, SCL=4**. Many 4-pin 0.96″ modules are **GND, VCC, SCL, SDA** (clock on pin 3). Photograph the module before copper. If the glass is SCL-then-SDA, either swap J1.3/J1.4 nets **or** document a crossed jumper — do not guess.

### 3. J2 — `SDO` GND is off-pin; SCL/SDA sit on the wrong pin numbers

`J2` `GY-BMP280` `Conn_01x06` at `(185.42, 69.85)`. Pin 1 at `+5.08` (`y=74.93`), pin 6 at `−7.62` (`y=62.23`).

| Pin | Intended (module + silkscreen) | Schematic today |
| --- | --- | --- |
| J2.1 VCC | `+3V3` | `+3V3` (this is the **CSB** row’s geometry — pin 1 is the *top*) |
| J2.2 GND | `GND` | **`SDA_SENS`** (`y=72.39`) |
| J2.3 SCL | `SCL_SENS` (GPIO19) | `SCL_SENS` (`y=69.85`) — matches because it is the middle |
| J2.4 SDA | `SDA_SENS` (GPIO21) | **`GND`** (`y=67.31`) |
| J2.5 CSB | `+3V3` | `+3V3` (`y=64.77`) |
| J2.6 SDO | `GND` (addr 0x76) | **no connection** — extra `GND` at `y=77.47` (**2.54 mm above pin 1**) |

PCB pads 1–6 are already the intended nets. Silkscreen `3V3 / GND / SCL=19 / SDA=21 / CSB / SDO` is the target. Move labels onto pin 1…6; put SDO’s `GND` on **J2.6**, not in space.

### 4. Same pin-1-at-top bug on J3, J4, J5, J7

Same `Conn_01xN` convention. PCB pads are the intended order; schematic pin numbers are reversed or missing the last pin.

**J3 AM2302** at `(185.42, 105.41)` — intended 1=`+3V3`, 2=`DHT_DATA`, 3=`GND`. Today pin 1=`GND`, pin 2=`DHT_DATA`, pin 3=`+3V3`.

**J4 SDS011** at `(185.42, 154.94)`:

| Pin | Intended | Schematic today |
| --- | --- | --- |
| J4.1 | `+5V` | **`PM_TX`** (`y=157.48`) |
| J4.2 | `GND` | `GND` |
| J4.3 | `PM_TX` (sensor TX → GPIO16) | **`+5V`** (`y=152.40`) |
| J4.4 | `PM_RX` (GPIO17 → sensor RX) | **off-pin** `y=160.02` |

**J5 MQ135** — intended 1=`+5V`, 2=`GND`, 3=`MQ_AOUT`, 4=NC. Today pin 1=`MQ_AOUT`, pin 2=`GND`, pin 3=`+5V`, NC flag at `y=195.58` (above pin 1). PCB pad 4 is already `unconnected-(J5-Pin_4-Pad4)`.

**J7 ESP32_Harness** `Conn_01x12` at `(299.72, 69.85)`, pin 1 at `+12.7` (`y=82.55`). Intended (README): 1 `+3V3` … 12 `+3V3`. Labels run `+3V3` at `y=57.15` (near **pin 11**) through `+3V3` at `y=85.09` (**2.54 mm above pin 1** — off-pin). PCB pads 1–12 already match the README table. Populate **U1 or J7, never both**.

### 5. R3 is still 15 kΩ; firmware is 20 kΩ

`R2` = `10k` series `MQ_AOUT`→`MQ_ADC`. `R3` = **`15k`** `MQ_ADC`→`GND`. Firmware `kMq135GndOhms = 20000`. Live breadboard is 10 k / 20 k.

| Ratio | GPIO at 5.0 V AOUT | Headroom vs 3.3 V abs max |
| --- | --- | --- |
| 10 k / 15 k (schematic now) | 3.00 V | 300 mV |
| 10 k / 20 k (bench + firmware) | 3.33 V | **none** |

**Recommendation:** keep **10 k / 15 k on copper** (R2=`10k`, R3=`15k`), then set firmware `kMq135GndOhms = 15000` and the AOUT reconstruction to 15/25 in the **same** change. Alternative: set R3=`20k` and leave firmware at 20000 — worse for GPIO stress, matches the breadboard only.

Do **one** pair everywhere (schematic value, silkscreen, `pins.hpp`, inventory). Do not ship 15 k on the board with 20 k in firmware.

### 6. J1 product identity + OLED SCL/SDA order

Covered under §2: rename LCD→OLED; confirm module pin 3/4 against a photo before locking copper. GPIO map (SDA=5, SCL=4) does not by itself define header order.

---

## Passive rationale (fit vs DNP)

| Ref | Value | Domain | Fit? | Why |
| --- | --- | --- | --- | --- |
| R1 | 10 k | 3V3 | **Fit** | AM2302 data pull-up to `+3V3` if the module has none. Harmless if the module already has one. |
| R2 | 10 k | 5 V analog | **Fit** | Series from `MQ_AOUT` to GPIO34. Never omit — 5 V AOUT must not hit the pin. |
| R3 | 15 k (see §5) | 5 V analog | **Fit** | Divider to GND. Must match firmware. |
| R4 | 4k7 DNP | 3V3 I²C | **DNP** | Optional `SDA_SENS` pull-up. GY-BMP280 already has pull-ups. Fitting both can over-stiffen the bus. Flag is already `dnp yes`. |
| R5 | 4k7 DNP | 3V3 I²C | **DNP** | Same for `SCL_SENS`. `dnp yes`. |
| R6 | 1 k | 5 V | **Fit** | Series for D1. 5 V domain only. |
| C1 | 100 µ / 16 V | 5 V | **Fit on PCB; optional on breadboard** | Bulk on `+5V`. SDS011 is a noisy 5 V load; keep on copper. Breadboard can skip if the PSU is stiff and local. |
| C2 | 10 µ | 3V3 | **Fit on PCB; optional on breadboard** | Bulk on DevKit `+3V3`. DevKit already has ceramics; extra bulk helps OLED/BMP280. |
| C3 | 100 n | 3V3 | **Fit on PCB; optional on breadboard** | HF on `+3V3`. |
| C4 | 100 n | 5 V | **Fit on PCB; optional on breadboard** | HF on `+5V`. |
| D1 | LED_5V | 5 V | **Fit** | Rail present indicator. Not a GPIO. |
| JP1 | VIN_LINK | 5 V → `ESP_VIN` | **Open on bench** | Close only after enclosed, measured PSU, and **never with USB**. |

OLED I²C pull-ups: not on this sheet (module + GPIO5 idle-high). Do not add a GPIO2 load.

---

## What is already OK (do not “fix”)

- **Firmware GPIO map** on `main` (`pins.hpp`) matches live bench. Worktree `.worktrees/atmosmesh-oled-u8g2` same GPIOs.
- **GPIO2** free: schematic NC on U1.27; PCB `unconnected-(U1-GPIO2-Pad27)`.
- **UART0** unused on copper: U1 pads 18/19 unconnected. Keep USB as the only UART0 user.
- **No 5 V net on a GPIO pad.** `+5V` touches J6, J4, J5, C1, C4, R6, D1, JP1 only. MQ135 hits GPIO34 only through R2/R3 as `MQ_ADC`.
- **R4/R5** already `dnp yes`.
- **PCB connector pad nets** already match the intended J1–J5 / J7 / U1 pinout. That is why a schematic→PCB update is dangerous, not because the copper pinout is unknown.
- **JP1** description: open on bench, never with USB.
- **BMP280 straps** on the *intended* J2 table: CSB=`+3V3`, SDO=`GND` → 0x76. Only the schematic *pin numbers* are wrong.
- Board still **unrouted** (ratsnest only). File growth is placement/silkscreen/KiCad 10 rewrite, not finished traces.

---

## Suggested edit order in KiCad

1. **U1 only** — move wires to the named pins in the table. ERC. Export netlist; diff U1 pin nets against the PCB pad list. **Do not update PCB.**
2. **J1–J5, J7** — same: move onto pin 1 = top. Park off-pin labels onto the last pin. Rename J1 OLED. ERC.
3. **R3 vs firmware** — pick 10k/15k (preferred) or 10k/20k; change the other side in the same session.
4. Silkscreen: `LCD1602` → OLED; confirm SCL/SDA legend vs module photo.
5. Only then: route, or Update PCB **with a pin-by-pin net diff**. Do not `--save-board` DRC if you still need KiCad 9 PCB files — this PCB is already KiCad 10.
6. Re-export `atmosmesh-bench-schematic.pdf` after the sheet is honest (PDF today will still show LCD1602 and the wrong U1 attachments).

## Out of scope for the PCB session

- Flashing, merging, committing product code (unless `pins.hpp` must change with R3=15k).
- Photographing the DevKit (U1 order is still provisional in the title block; silkscreen `VERIFY DEVKIT PINOUT`).
- Closing JP1 or paralleling a 3.3 V AC/DC onto `+3V3`.

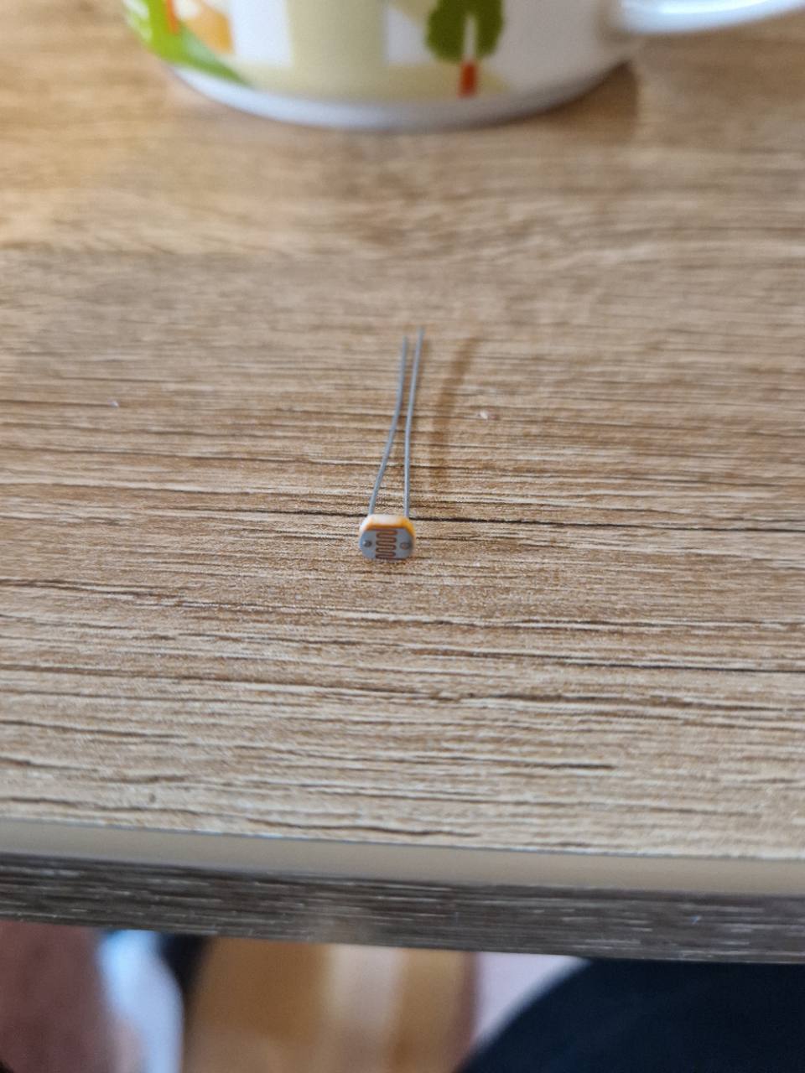
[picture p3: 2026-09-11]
docs/assets/inventory/electronics-ldr-2026-08-17.jpg

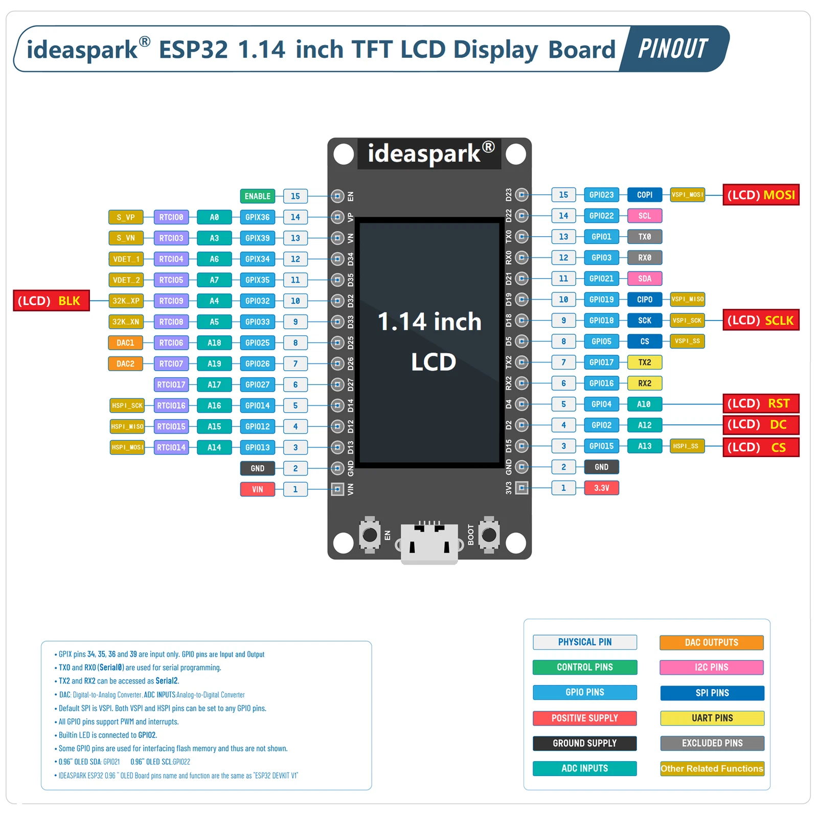
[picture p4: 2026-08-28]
docs/hardware/ideaspark-esp32-tft-pinout.png

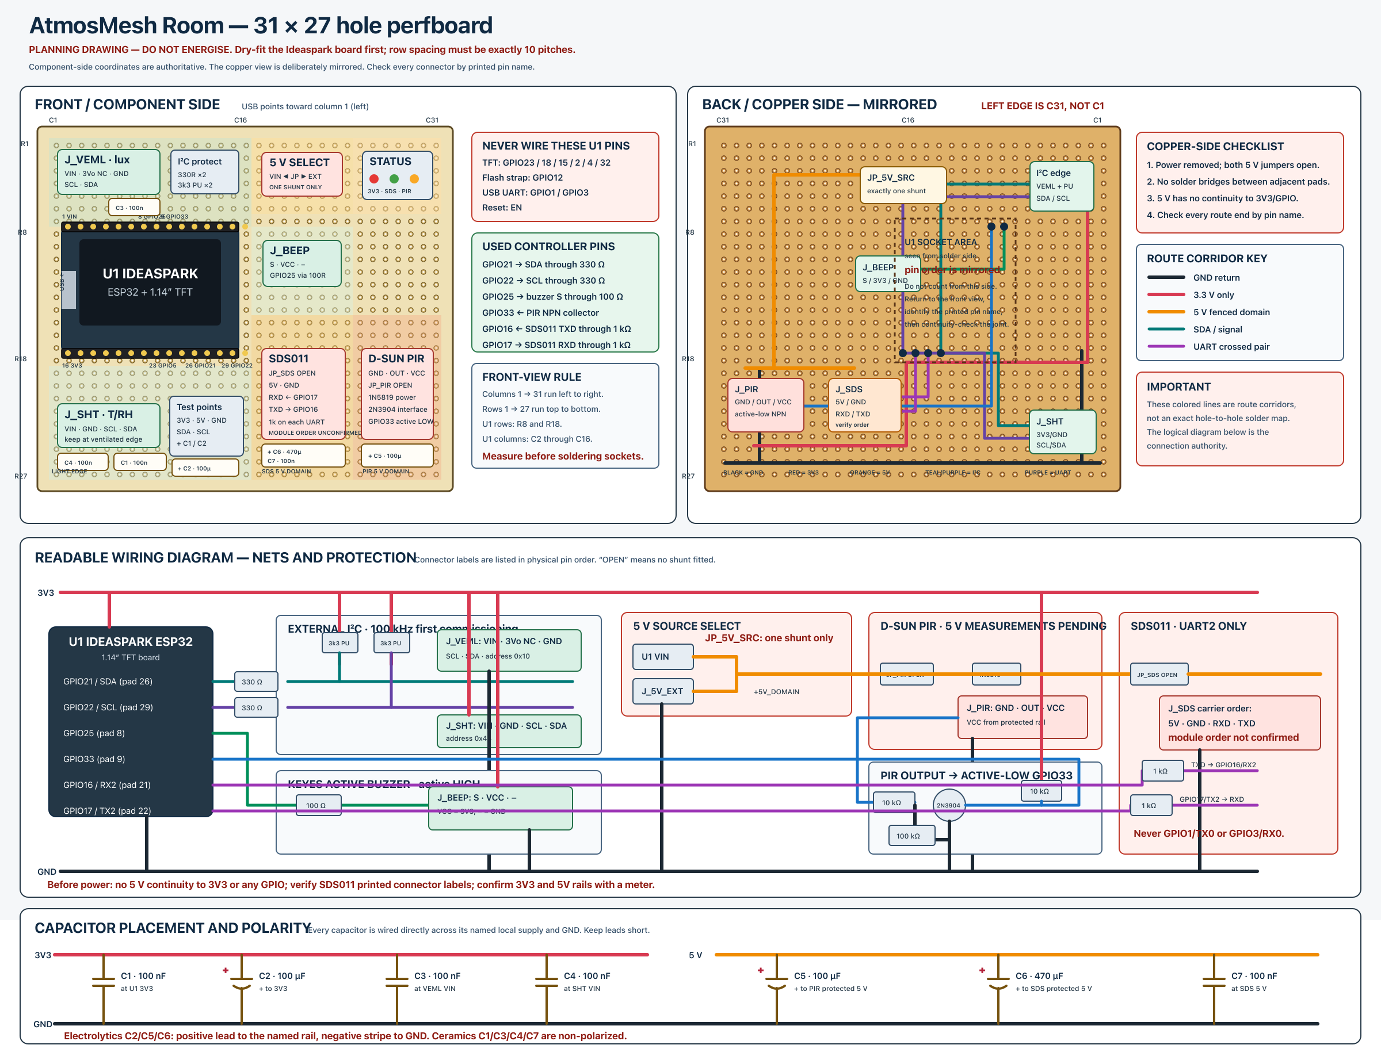
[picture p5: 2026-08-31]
hardware/kicad/atmosmesh-room/atmosmesh-room-perfboard-drawing.png

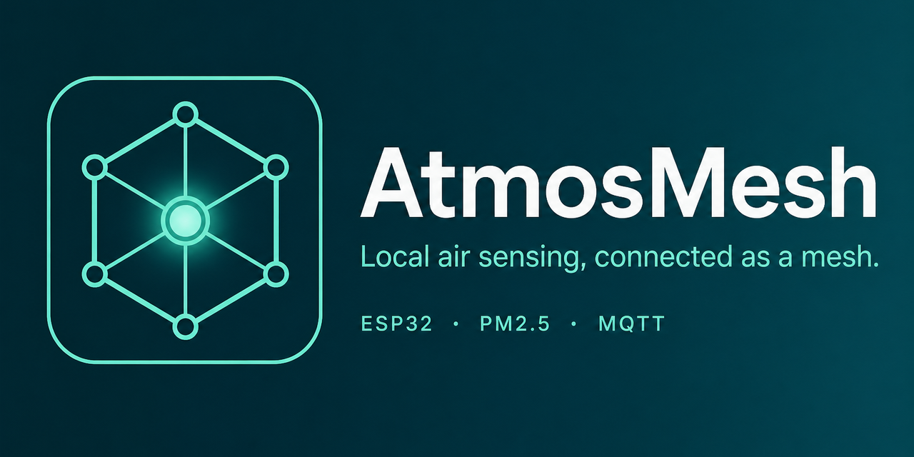
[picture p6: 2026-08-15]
docs/assets/social-preview.png

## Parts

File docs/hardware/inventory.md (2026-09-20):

# Known hardware and safety status

This file contains only project-relevant hardware. Exact module variants remain unverified until
RLS-01 records front/back photos and markings. Manufacturer PDFs and a chip-level comparison live
in [datasheets/](datasheets/README.md) and [spec-comparison.md](spec-comparison.md).

| Component | Intended role | Supply | Interface | Verification status |
| --- | --- | --- | --- | --- |
| ESP-WROOM-32 devboard | Controller, Wi-Fi, MQTT | Station: `VIN`/`5V` from the 5 V rail. Bench: USB until PSU is enclosed and measured | 3.3-V GPIO | USB probe 2026-08-14: ESP32-D0WDQ6 rev 1.0, 4 MB flash, CP2102, MAC `ac:67:b2:37:26:78`. `VIN`/`5V` silkscreen still pending |
| ESP8266EX / ESP8266MOD, NodeMCU-style D labels | **AtmosMesh Grove v1.5** controller | USB; fitted modules from `3V3` | 3.3-V GPIO | Probe: ESP8266EX, 26 MHz, 4 MB. Reviewed AtmosMesh Grove image flashed and booted 2026-08-24; former AT firmware replaced under authorization |
| SDS011 (Nova; board often labelled d011v2) | PM2.5 and PM10 | 5 V (4.7–5.3 V, > 1 W) | UART2 9600 8N1, 3.3-V TTL | **GPIO16/17 only.** Never RX0/TX0 (GPIO3/1) |
| DHT22 / AM2302 | Temperature and humidity | **3V3** | Single-wire data on GPIO18 | Operator: data = D18/GPIO18. Idle-high; 10 kΩ pull-up to 3V3 if the module has none |
| GY-BMP280 | Pressure and temperature | **3V3** (chip 1.71–3.6 V) | I²C (6-pin module) | Operator: VCC, GND, SCL, SDA, CSB, SDO. Straps below. Regulator/5 V still unconfirmed |
| Mini OLED, 4 pins | Station local status (D-001) | **3V3** | I²C **0x3C** (fallback 0x3D) | Serial 2026-08-14: ACK at 0x3C, SDA=GPIO5, SCL=GPIO4. Cheap 0.96" SSD1306: alternate COM 0x12 skips rows; firmware default is U8g2 SSD1306 ALT0 (COM 0x02 sequential). SH1106 is compile fallback ID=1 |
| LCD 1602 I²C | Not the product display | **3V3 only** if reused | I²C backpack 0x27/0x3F | Spare. Station firmware drives the OLED, not this panel |
| 2.54 mm Dupont connection assortment | Passive prototype interconnects | None (passive) | Male and female contacts/headers, single-row housings (~1–10 positions), and 40-pin male headers | Project stock confirmed sufficient; exact quantity not verified. Inspect each crimp, current requirement, and pin assignment before use |
| Radial aluminum electrolytic capacitor assortment | Passive filtering and energy storage | None (passive) | Polarized; 36 variants spanning 1–1500 µF and 10–63 V | Photo-confirmed label 2026-09-04: 925 pieces. Check polarity and rated voltage on each capacitor; never reverse-bias or exceed its voltage rating. No quality, ESR, or ripple-current rating inferred from the photo |
| Diode assortment kit | Passive rectification, protection, and switching | None (passive) | 100 pieces across 8 types: 1N4148 ×25, 1N4007 ×25, 1N5819 ×10, 1N5408 ×5, 1N5399 ×10, FR107 ×10, FR207 ×10, 1N5822 ×5 | User-read inventory 2026-09-04; not photo-verified. Before use, verify type, polarity/cathode band, and permitted voltage, current, and switching parameters from the actual marking and a matching datasheet; types are not interchangeable |
| MQ135 modules (~2 total) | Experimental gas trend | 5 V heater | Analog through divider | Bench 10 kΩ series + 20 kΩ to GND on GPIO34. Never label as CO₂. Approximate total stock user-confirmed 2026-09-04 |
| Open AC/DC `5V07 / 12V04` | Candidate station 5 V rail | 230 V AC primary | DC output unverified | **Must measure** before use. Family is 5 V/700 mA *or* 12 V/~400 mA. Open mains PCB — enclose first. See [power.md](power.md) |
| SANMIM SM-PLG06A / SM-104-3.3V-02 | Spare 3.3 V AC/DC | 230 V AC primary | 3.3 V | Not required for MVP; do not parallel with ESP32 `3V3`. Open mains PCB |

## Heltec WiFi LoRa 32 V2 — USB probe (2026-09-05)

`esptool` probe on `/dev/ttyUSB0` after the board arrived, full flash backup, then (operator go-ahead the same
day) a Meshtastic listener image for the coverage test.
Board plan and idea list: [lora-remote-node.md](lora-remote-node.md).

| Fact | Value |
| --- | --- |
| USB-UART | Silicon Labs CP2102 (`10c4:ea60`) |
| Chip | ESP32-D0WDQ6 revision v1.0, 40 MHz crystal — a **V2** board (the V3 is an ESP32-S3) |
| Flash | 8 MB, 3.3 V (manufacturer `ef`, device `4017`) |
| MAC | `3c:61:05:0e:04:ec` |
| Auto-reset | RTS works |
| Stock firmware | Heltec factory test; boot prints `LoRa Initial success!` and `ESP32ChipID=EC040E05613C`, then nothing more on serial |
| Backup | `PlatformRelay/.tooling/firmware-backups/heltec-wifi-lora32-v2_3c61050e04ec_stock-factory_2026-09-05.bin` (full 8 MB) |
| Current firmware | Meshtastic 2.7.26 `meshtastic-diy-v1` (written 2026-09-05: `*.factory.bin` at `0x0`, `mt-esp32-ota.bin` at `0x260000`, `littlefs-*.bin` at `0x300000`, all hash-verified). Region `EU_868`, LongFast, node `!050e04ec` |
| Radio init | `RF95 init success` on the diy-v1 pin map (cs 18, irq 26) — so the radio is SX127x class and the V2's LoRa SPI/DIO0 wiring matches diy-v1 |
| LoRa listen 2026-09-05 | ~10 min on 869.525 MHz LongFast across two windows: `num_packets_rx=0`, `num_packets_tx=0`, no other node in `--nodes`, noise floor −107 to −110 dBm. TX not yet seen on the serial log (see the bring-up handoff) |
| Radio, antenna, battery connector polarity, OLED | **Not verified** — need front/back photos and a meter before any wiring |

## User-confirmed component stock (2026-09-04)

These are rough stock counts, not wiring approval. Unless a row says otherwise, the identity was
read or described by the user without front/back photo verification. Exact module revision,
markings, supply, pin order, signal levels, and electrical limits remain unverified where noted;
inspect the actual part before it enters an RLS-01 or ROOM-01 wiring decision.

| Component | Quantity | User-stated identity / role | Verification and safety status |
| --- | ---: | --- | --- |
| Adjustable PIR motion module | 5 | HC-SR501 | Exact board revision, front/back markings, supply, pin order, and signal level unverified |
| ESP32-C6 module | 5 | Exact marking may be an ESP32-C6-MINI family part | Exact module identity, revision, and flash size are not photo-verified |
| Gas-trend sensor breakouts | 1 each | SGP41 (VOC/NOx trends) and GY-SGP40 (VOC trend) | Keep separate; exact breakout supply and pins unverified. Neither is a CO₂ sensor |
| Classic ESP32 DevKit | 2 | USB-C, CH340C, ESP-WROOM-32; seller-described Wi-Fi/Bluetooth dual-core boards | Exact board revision and pin labels unverified; never apply 5 V to GPIO or `3V3` |
| 0.96-inch 128×64 I²C OLED | 4 | Probably SSD1306; user reports 2 blue, 1 yellow, 1 white | Controller and board implementation unverified. Seller's 3.3–5 V claim is not wiring approval; use **3V3** until regulator and I²C pull-ups are checked |
| Loose narrow 128×32 OLED | 1 | Additional loose display; not the fitted Grove OLED | Controller, color, interface, supply, and pins unverified |
| Encapsulated DS18B20 temperature probe | 2 | Each has a 2.5 m cable; “waterproof” is a product claim | Cable colors and pin order must be verified before use; no ingress rating confirmed |
| PCB screw terminals | 30 total | 10 × 2-pin, 10 × 3-pin, 10 × 4-pin | Pitch and electrical ratings unverified |
| BME280 sensor breakout | 5 (6 with the one found later) | Humidity, pressure, and temperature; distinct from the known BMP280 | **One of six photo-verified 2026-09-04:** purple `GY-BM E/P 280`, 6-pin `VCC GND SCL SDA CSB SDO`, no regulator (3.3 V only), four 10 kΩ, SDO low → `0x76`; see the photo-pass row below. Compare the other five against that description before use; a board with a regulator or another pin order is a separate variant |
| ESP32-C3 SuperMini OLED developer board | 5 | ESP32-C3, 0.42-inch OLED, ceramic antenna | Exact board and OLED revisions unverified; chip family is C3, not C9 |
| 230 V AC to 5 V DC switching supply | 2 | One labelled/described 5 A; one labelled/described 1 A | Unverified inventory only. Check enclosure, isolation, terminals, and nameplate; never energize an open mains PCB. No mains wiring approval |
| Capacitive soil-moisture module | 5 | Board marking “Soil Sensor v2.0.0” | Supply, output range, pin order, sealing, and calibration unverified; raw output is not a moisture claim without calibration |
| RTC module | 1 | Exact type unknown | Identity, battery arrangement, supply, interface, and pins unverified |
| MQ-series gas modules | 1 each | MQ-7 and MQ-3; separate from the ~2 MQ135 modules above | Not CO₂ sensors. Verify exact module, 5 V heater requirements, output range, and signal conditioning before connection |
| Four-row I²C character LCD | 1 | Four visible rows; “LCM1602” was read from the module/backpack | Exact geometry, controller/backpack type, address, supply, and I²C levels unverified; do not classify it as 1602 from that marking alone |
| 24 GHz presence-radar module | 1 each | HLK-LD2450 and probably HLK-LD2410S | Exact suffixes, supply, pins, and signal levels unverified; inspect both sides before wiring |
| Sensirion SPS30 particulate sensor | 1 | SPS30; `DE50F3959A7612A8` is an individual device/batch identifier, not the model | Connector pin order, interface choice, and supply must be verified on the actual unit |
| JST-PH connector and cable set | 1 set | Receptacles/extensions and pre-crimped 24 AWG silicone wire | Pole counts, quantities, pin order, crimp quality, and current rating unverified |
| Clip-on ferrite core | 10 | Cable interference suppression | Material, impedance curve, usable frequency range, and fit unverified |
| CTK-014 universal oscilloscope probe set | 1 | Measurement accessory set | Contents and ratings must be checked before measurement |
| RXEF PPTC assortment | 50 total | 72 V max; 10 each: RXEF020 0.20 A, RXEF030 0.30 A, RXEF050 0.50 A, RXEF075 0.75 A, RXEF110 1.10 A | Listed currents are **hold currents**, not trip currents. Verify markings and datasheets; not for 230 V mains |
| Hantek DSO2D15 oscilloscope | 1 | Two-channel DSO2000-series bench scope with built-in generator | How to use it, and the project's ripple / I²C / UART / rail recipes: [oscilloscope-hantek-dso2d15.md](oscilloscope-hantek-dso2d15.md). Bandwidth, sample rate and firmware version still to be read off the instrument |
| G6000 oscilloscope probe | 1 | Switchable 1×/10× probe | Verify switch position, compensation, grounding, and voltage/category rating before measurement |
| VEML7700 light-sensor breakout | 3 (the German inventory says 4 — resolve at the next count) | I²C ambient-light modules; actual stock now present | **One photo-verified 2026-09-04:** `HW-900`, `VIN 3VO GND SCL SDA`, regulator + level shifter + `103` array; see the photo-pass row below and compare the others against it before use. Earlier note: the earlier “not fitted” bench result does not test these spares |
| BMI160 I²C module | 4 | 6 DoF: 3-axis accelerometer plus 3-axis gyroscope; no magnetometer | Exact breakout variant, address straps, supply, and pins unverified; “Tenstar” is at most a seller label |
| Sensirion SCD41 module | 1 | True CO₂ sensing by photoacoustic NDIR, plus temperature and relative humidity | Exact breakout, supply, and pin order require inspection before wiring; validate readings for the intended enclosure |
| INA226 current/voltage measurement module | 1 | Read as CJMCU-226 I²C breakout | Exact breakout variant, shunt value, supply, pins, common-mode range, and current range unverified |

## AtmosMesh Grove v1.5 — fitted 3.3 V slice (2026-08-24)

This is a separate ESP8266 product variant, not a replacement for the ESP32 station above.

| Component | Interface | Grove wiring | Status |
| --- | --- | --- | --- |
| 128×32 SSD1306 OLED | I²C, normally 0x3C (0x3D fallback) | SDA=`D2`/GPIO4, SCL=`D3`/GPIO0, VCC=`3V3` | **Initialization pass:** `oled: ok addr=0x3C geometry=128x32`; pixels not visually confirmed |
| BMP180 | I²C, 0x77 | Shares SDA=`D2`/GPIO4 and SCL=`D3`/GPIO0, VCC=`3V3` | **Runtime pass:** repeated; latest four samples, 24.6–24.7 °C and 984.3 hPa |
| Blue DHT11 | Single-wire | DATA=`D5`/GPIO14, VCC=`3V3` | **Communication pass:** valid frames observed (32.0→31.0 °C, 32% RH); not accuracy/calibration evidence |
| Bare LDR RC | Digital RC timing | `3V3 → LDR → 1 kΩ → D7`/GPIO13 node; 100 nF node-to-GND | **Runtime communication pass:** 389–452 µs observed. Bright/dark/saturation/timeout response pending; raw µs only, lower means brighter, never lux/percent |
| Bi-color LED | Two digital channels | Red=`D6`/GPIO12, green=`D0`/GPIO16; separate ~330 Ω resistors | **Operator-confirmed:** installed LED is common-anode/active LOW; only the inverted diagnostic produced the intended D6 red / D0 green colors. Canonical Grove profile now matches; common-cathode is an explicit alternative build |
| YL-38 + probe | Switched analog | AO→47 kΩ→A0, 15 kΩ A0→GND; 100 nF (`104`) A0→GND; DO unused | **Runtime raw pass:** two cycles about 30 s apart, each ADC 214 averaged from five samples. No calibration claim |
| 2N3906 PNP high-side switch | YL-38 VCC control | Emitter=3V3, collector=YL VCC, base=`D1`/GPIO5 through 2.2 kΩ, 100 kΩ base-emitter pull-up | Confirmed alternative physically wired by operator; active LOW, fail-safe OFF |

### Controlled Grove flash and boot (2026-08-24)

With explicit authorization and independent approval of head `a681990`, the coordinator ran
`ESP_PORT=/dev/cu.usbserial-0001 task flash-v1-5`. Esptool identified the same ESP8266EX, 26 MHz
crystal and 4 MB flash recorded earlier, wrote 287,920 bytes, verified the hash and hard-reset the
board. Boot reported:

```text
product=AtmosMesh Grove variant=atmosmesh-v1.5 station_id=atmosmesh-grove-0001
i2c: SDA=D2/GPIO4 SCL=D3/GPIO0 clock=100000 Hz
boot-warning: D3/GPIO0 must remain HIGH during reset
```

This replaced the working AT firmware under authorization. AtmosMesh v1 and its ESP32 were not
flashed or otherwise changed. For DHT11, do not infer a cause from the error alone: verify actual
DATA joint/pin, 3.3 V/GND orientation and a 4.7–10 kΩ pull-up (or resistor on the module). A serial
OLED init line proves controller communication, not visible pixels.

The captured `a681990` banner above had no separate stable product ID. After independent approval
of final head `50ca2f3`, the coordinator ran `task flash-v1-5` again. Esptool identified the same
ESP8266EX/4 MB board, wrote 287,952 bytes, verified the hash, hard-reset it and captured:

```text
product=AtmosMesh Grove product_id=atmosmesh-grove-v1.5 variant=atmosmesh-v1.5 station_id=atmosmesh-grove-0001
```

The I²C configuration and power/boot warnings were correct. OLED initialization again passed at
0x3C/128×32, but pixels remain visually unconfirmed. BMP180 passed four samples at 24.6–24.7 °C /
984.3 hPa. DHT11 remained unavailable in all four observed cycles.

`D3` is ESP8266 GPIO0, a boot strap. It must remain high during reset; if the I²C bus or a
module pulls it low, the board enters ROM download mode. Firmware preserves the actual wiring with
`Wire.begin(4, 0)` and logs the constraint rather than silently assigning another pin.

The DHT11 later returned valid frames on D5/GPIO14 while BMP180 reported 25.6 °C and
983.9–984.0 hPa. This is a communication pass, not DHT11 accuracy proof.

MAX4466 will not be used. The installed LDR uses bounded D7 RC timing; V15-06 assigns A0 only to the
divided YL-38 AO path and exposes raw ADC counts. GPIO never powers the YL board. If its VCC is tied
directly to 3V3, firmware cannot limit probe duty and must not claim corrosion control.

After independent approval of the light/MQTT product diff at `e5d83e1` and green CI, an authorized
follow-up upload rebuilt the image and generated secrets successfully. Before esptool opened the
port, `/dev/cu.usbserial-0001` disappeared; upload ended with `FileNotFoundError`. No chip connection
or write began, so zero bytes from `e5d83e1` reached the board and its prior firmware is unchanged.
At that point `ls /dev/cu.*` showed no USB serial device and ioreg showed hubs only. Reconnect and
confirm the serial port before retrying light/MQTT validation.

The USB serial device later reappeared. After independent approval of head `c880afe`, the
coordinator ran `ESP_PORT=/dev/cu.usbserial-0001 task flash-v1-5`. Esptool identified ESP8266EX,
26 MHz crystal and MAC `2c:3a:e8:43:7c:16`, wrote 310,288 bytes, verified the hash and hard-reset.
More than 60 seconds of 115200-baud serial contained two soil cycles about 30 seconds apart, both
exactly `soil: ok adc_raw=214 samples=5 power=off`. DHT11 was stable at 25.0 °C / 36–37% RH,
BMP180 at 24.4–24.5 °C / 982.6–982.8 hPa, uncalibrated light at 389–452 µs and core sensor health
was okay. The OFF text proves the firmware action, not switched-rail voltage or current. LED
colors/polarity, physical power-off, probe calibration, MQTT broker/HA receipt and OLED pixels
remain unconfirmed.

On 2026-08-24, reviewed head `4e4a820` was flashed to the same ESP8266EX/26 MHz board: esptool
wrote 310,224 bytes, verified the hash and hard-reset. More than 30 seconds of serial reported
`mqtt: connected`, logical status `green/healthy`, DHT11 25.0 °C / 36% RH, BMP180
25.3–25.7 °C / 982.1–982.4 hPa, raw light 420–492 µs and
`soil: ok adc_raw=214 samples=5 power=off`; DHT/BMP/light health was okay. This does not prove
broker-side receipt/HA entities, visible OLED pixels/layout,
switched-rail voltage/current, physical power-off or sensor calibration.

The later operator visual diagnostic established that the fitted D6 red / D0 green LED is
common-anode (active LOW). Raw soil ADC 214 is still not a moisture classification: calibration
direction and dry/warning/acceptable cutoffs remain unset pending controlled measurements.

Reviewed canonical head `8fca62d` was subsequently flashed on 2026-08-24. Esptool wrote 480,976
bytes and verified the image. Serial reported raw soil ADC 213 from five samples, followed by
logical common-anode amber (`red=LOW green=LOW`) because calibration was disabled, direction was
unknown and thresholds were unset. This validates the firmware policy and logical pin drive only;
visible LED colour, physical power-off and controlled dry/wet calibration references remain
pending.

## USB identity of the connected controller (2026-08-14)

Read-only `esptool` probe on `/dev/cu.usbserial-0001`. Nothing was flashed.

| Fact | Value |
| --- | --- |
| USB-UART | Silicon Labs CP2102 (`10c4:ea60`), serial `0001` |
| Chip | ESP32-D0WDQ6 revision v1.0 |
| Flash | 4 MB, 3.3 V |
| Crystal | 40 MHz |
| MAC | `ac:67:b2:37:26:78` |
| Auto-reset | RTS works (BOOT button not required for esptool) |

This matches the ESP32-WROOM-32 module datasheet (embedded ESP32-D0WDQ6, 4 MB flash, 40 MHz).
The **devboard** name and pin labels are still unconfirmed.

## GY-BMP280 — 6-pin module (operator, 2026-08-14)

Confirmed labels: **VCC, GND, SCL, SDA, CSB, SDO**. That is the usual GY-BMP280 (I²C + SPI).
Bosch sheet: I²C vs SPI is selected by CSB; the 7-bit address LSB is SDO. Neither strap may float.

| Module pin | Role | Bench wiring for I²C |
| --- | --- | --- |
| VCC | Module supply | ESP32 **3V3** (not 5 V until a regulator on the breakout is photographed) |
| GND | Ground | ESP32 GND |
| SCL | I²C clock | **GPIO19** (operator, 2026-08-14). Not GPIO22 |
| SDA | I²C data | **GPIO21** |
| CSB | Interface select | **3V3** — high = I²C. Low = SPI. Leave-open is invalid |
| SDO | I²C address LSB | **GND** → address **0x76**. Tie to 3V3 → 0x77 |

CSB and SDO are local straps to 3V3/GND. They do not go to ESP32 GPIOs for I²C.

If VCC is 5 V and the module’s I²C pull-ups sit on VCC, SDA/SCL become 5 V and will damage the ESP32. Until the back of the board is photographed, **3V3 only**.

## Provisional signal map — not approved for construction

| Signal | ESP32 pin | Notes |
| --- | --- | --- |
| I²C SDA (GY-BMP280) | GPIO21 | Operator, 2026-08-14 |
| I²C SCL (GY-BMP280) | GPIO19 | Operator, 2026-08-14. Not GPIO22 or GPIO18 |
| BMP280 CSB | 3V3 | I²C mode; not an ESP32 GPIO |
| BMP280 SDO | GND | Address 0x76; not an ESP32 GPIO |
| I²C SDA (SSD1306 OLED) | GPIO5 / D5 | D-001; serial-proven 0x3C. Idle-high pull-up is usually OK for boot |
| I²C SCL (SSD1306 OLED) | GPIO4 / D4 | Power OLED VCC from 3V3, never 5 V |
| AM2302 data | GPIO18 / D18 | Operator, 2026-08-14. Idle-high OK (3.3 V flash-voltage strap) |
| SDS011 TX | GPIO16 / RX2 | Sensor TX → ESP32 RX2. **Not** RX0 / GPIO3 |
| SDS011 RX | GPIO17 / TX2 | ESP32 TX2 → sensor RX. **Not** TX0 / GPIO1 |
| USB console (CP2102) | GPIO1 TX0, GPIO3 RX0 | `task flash` / `task monitor` only. Leave the USB cable as the only UART0 user |
| MQ135 analog | GPIO34 / ADC1 | Input-only. Bench divider **10 kΩ series + 20 kΩ to GND** (GPIO = 2/3 AOUT). 5 V AOUT → **3.33 V** on GPIO34 — **no headroom**. Never 5 V on the pin. Not UART. Firmware logs raw/mV, never CO₂ |

## Bench mix-up (2026-08-14) — SDS011 on RX0/TX0

Operator wired **d011v2** (SDS011 v2) to **RX0/TX0** (GPIO3/GPIO1). That is the USB-UART used for
`task flash` / `task monitor`. Firmware talks to SDS011 on **UART2 only** (`Serial2` on GPIO16/17);
it will not be moved to UART0. Unplug the sensor from RX0/TX0 immediately. Correct: sensor TX →
GPIO16, GPIO17 → sensor RX, **5 V on sensor VCC only**, UART **3.3 V**. USB cable stays on the
DevKit as the only UART0 user. A live SDS011 on UART0 garbles the boot log, can stall the app
(OLED looks “dead”), and fights the CP2102.

## Bench mix-up (2026-08-14) — MQ135 vs SDS011 on UART2

Operator wired a module called “MQ13” to RX2/TX2 (GPIO16/17). **MQ135 is analog AOUT + 5 V heater;
it has no UART.** SDS011 is the UART sensor on those pins (sensor TX → GPIO16, ESP TX → GPIO17).
Firmware does not bit-bang analog on GPIO16/17. If the gas board is still on RX2/TX2, unplug it
before applying 5 V. OLED blanking with a live `oled: init ok` is not explained by UART2; a 5 V
short onto GPIO can brown out `3V3` and blank the glass — serial on 2026-08-14 showed **no**
brownout and I²C 0x3C/0x76 still present.

## Bench bring-up (2026-08-17) — 3V3 sensors pass, both 5 V sensors fail

First capture with everything soldered, 20 s window, board stable (`rst:0x1 (POWERON_RESET)`,
one boot banner, no loop). Follows the LDO replacement in
[incident-2026-08-17-ldo.md](incident-2026-08-17-ldo.md).

| Sensor | Rail | Result |
| --- | --- | --- |
| AM2302 | 3V3 | **Pass** — `t=28.4C rh=39.2–41.4%`, stable |
| BMP280 | 3V3 | **Pass** — `t=29.7C p=973.2 hPa` |
| SSD1306 OLED | 3V3 | **I²C pass** — `init ok … addr=0x3C 128x64`. Pixels unconfirmed |
| PIR | 3V3 | Inconclusive — `pir: idle` proves the pull-down only |
| VEML7700 | 3V3 | Not fitted — `not found (ok until fitted)` |
| **SDS011** | **5 V** | **Fail** — 1546 no-frame lines / 20 s, **0 valid frames** |
| **MQ135** | **5 V** | **Fail** — erratic `raw=` 1097, 119, 0, 38, 724, 123 |

**The failures partition exactly along the supply rail:** every 3.3 V device works, both 5 V
devices do not. Per [power.md](power.md), SDS011 and MQ135 are the only 5 V loads.

This is a **lead, not a conclusion**. At least two stories fit equally well:

1. A common 5 V feed is dead or marginal.
2. Two unrelated faults — MQ135 strapped to 3V3 via `3V3_5V_SEL`, *and* SDS011 UART wired
   straight-through instead of crossed. The bench schematic has an independent `3V3_5V_SEL`
   strap, so the two rails are not necessarily one net.

Parsimony is not evidence. Discriminate physically before rewiring anything:

- **Is the SDS011 fan spinning?** Spinning → it has 5 V, so its fault is the UART and the
  rail story collapses to MQ135 alone. Still → no 5 V.
- **Is the MQ135 warm after a minute?** A powered heater is unmistakably warm to the touch.
  Cold means unpowered whatever a meter reads at the header.

Supporting note on MQ135: it read ~1250 in a narrow band *before* soldering (floating pin) and
now reads mostly 0–123 with occasional spikes. With the 10 k series + 20 k-to-GND divider fitted
and nothing driving AOUT, the pin is pulled toward ground — *consistent with* an undriven AOUT.
Not proof; a faulty ADC would look similar.

### SDS011 UART crossing (the rule the current wiring may violate)

From the pin table above — the sensor connector is **crossed**, not straight-through:

| SDS011 pin | Goes to | Never |
| --- | --- | --- |
| **TX** (datasheet pin 7) | **GPIO16 / RX2** | not TX2/GPIO17, not RX0/GPIO3 |
| **RX** (datasheet pin 6) | **GPIO17 / TX2** | not RX2/GPIO16, not TX0/GPIO1 |

Wiring sensor TX → TX2 also puts two push-pull outputs on one net (ESP32 TX2 drives, sensor TX
drives). That is contention, not just silence.

Firmware says this itself on every failed poll: `sds011: no AA C0 frame (listening GPIO16/RX2;
sensor TX must not sit on TX2/GPIO17)`.

**Listen-only test if desoldering is expensive:** flash with `Serial2.begin(9600, SERIAL_8N1,
17, -1)`. Frames appear → sensor TX is on GPIO17 and the pair is straight-through. Use `-1` for
TX so GPIO16 is never driven into the sensor's TX if the wiring was in fact correct.

### SDS011 confirmed wired straight-through — and GPIO17 has two drivers on it

Operator verified 2026-08-17: **SDS011 TX → TX2/GPIO17, SDS011 RX → RX2/GPIO16.** That is
straight-through. The pin table above requires it **crossed**: sensor TX → GPIO16, GPIO17 →
sensor RX. This fully explains 0 valid frames — the ESP32 listens on GPIO16, where only the
sensor's *receive* pin is connected, so nothing ever arrives.

> **Contention hazard, live right now.** The firmware configures GPIO17 as UART2 **TX**, a
> push-pull output. The SDS011's TX is also a push-pull output. Both are soldered to the same
> net and fight whenever they drive opposite levels — roughly 10 ms in every second, each time
> the sensor transmits its 10-byte frame at 9600 baud. ESP32 GPIO absolute max is 40 mA and a
> driver fight can exceed it. Fix this before leaving the bench powered for long runs.

Two fixes, and they are not equivalent:

| Fix | Effort | Consequence |
| --- | --- | --- |
| **A. Re-solder crossed** | Desolder two joints | Bench matches the pin table, the KiCad board and every doc. Contention gone. |
| **B. Swap firmware constants** — `kSds011RxGpio = 17`, `kSds011TxGpio = 16` | One-line, no iron | Works, and also ends the contention (GPIO17 becomes an input). But the bench now **diverges** from the routed PCB and the pin table, so both must be annotated or the next board repeats the fault. |

B is the faster confirmation that the diagnosis is right, since UART2 remaps freely through the
ESP32 GPIO matrix and both pins are ordinary I/O. A is the correct end state for a board whose
schematic is already routed. Either way the ESP32 stops driving GPIO17.

Note the SDS011 reports autonomously at 1 Hz and needs no commands, so the ESP32→sensor
direction is optional; only "sensor TX → an ESP32 receive pin" actually matters.

### Flashing is intermittent, not blocked by a dead pin

Attempting `pio run -t upload` now fails, twice, identically:

```text
Download mode successfully detected, but getting no sync reply:
The serial TX path seems to be down.
```

Read that carefully — it is **directional**:

| Direction | Path | State |
| --- | --- | --- |
| ESP32 → host | GPIO1 / TX0 → CP2102 | **Works** — 52 kB of boot + app log read back |
| Host → ESP32 | CP2102 → GPIO3 / RX0 | **Intermittent** — 12 kB written, then no sync reply |
| Auto-reset | DTR/RTS → EN, IO0 | Works — download mode *is* entered |

The chip and its reset circuit are healthy. The wording "TX path seems to be down" is esptool's
guess after one lost reply and should not be read as a dead pin — see the correction below.

**Corrected 2026-08-17: this is not a dead GPIO3.** An earlier revision of this note blamed a
loaded RX0. Two pieces of evidence refute it:

1. Operator verified the SDS011 joints: its TX is on **TX2/GPIO17**, its RX on **RX2/GPIO16**.
   Nothing is on RX0/GPIO3.
2. The first upload attempt logged `Writing at 0x00001000... (100 %)` — a **fully successful
   host→chip write of 12 kB** — before losing the connection. A dead receive pin cannot do that.

So the link is **intermittent, not broken**. Prime suspect is the USB path, consistent with the
`tcsetattr: Invalid argument` wedge seen on the same port earlier the same day: `ioreg` showed
the CP2102 sitting behind a **VIA Labs USB2.0 hub chain**. Try a direct port on the Mac, a
different cable, and a lower `upload_speed` before suspecting the board.

**The old app survived this attempt** — by luck of ordering, not by design. esptool announced
`Flash will be erased from 0x00010000 to 0x00062fff`, but the erase evidently never executed:
the board still boots clean (`POWERON_RESET`) and `bmp280`, `am2302`, `mq135` and
`oled: init ok` all still report. Note that this was verified over serial, which is the very
channel now proven half-broken — treat it as good evidence, not proof.

> **Improve the USB link before the next flash attempt.** The hazard is the retry itself: an
> upload that gets one step further erases the app region and can then still fail to write it,
> leaving the board with no application. That is recoverable — the link is intermittent, not
> dead — but only by flashing again, so do not spend the working app on a link that is known
> flaky. Direct USB port, known-good cable, lower `upload_speed` first; then flash once.

### Firmware issues found in the same capture

- `firmware/src/products/atmosmesh_v1.cpp` — the SDS011 no-frame log is emitted every `loop()`
  iteration with no rate limit: **~93 lines/s, 96.6 % of all serial output**. It buries every other
  subsystem.
  MQ135 (gated at 2 s by `kAm2302MinIntervalMs`) appears at roughly 1 line per 300. Needs a
  `millis()` throttle.
- `firmware/src/display_text.cpp:85` — `(void)mq135_raw_adc;` discards the MQ135 value, so it
  **cannot** appear on the OLED regardless of wiring.
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

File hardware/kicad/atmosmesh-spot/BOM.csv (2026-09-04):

Ref | Qty | Part | Value or type | Stock source | Note
U1 | 1 | ESP32-C3 SuperMini with 0.42in OLED | 3.3 V logic; on-board LDO; rev 4; 4 MB; MAC E4:EC:E6:92:05:D4 | 1 of 5 | pin map photo-verified 2026-09-04: row A 5V GD 3V RX TX 2 1 0 / row B 10 9 8 7 6 5 4 3 from the USB end; rows 7 pitches apart (dry-fit confirmed); OLED at 0x3C on GPIO5/GPIO6 by scan
U2 | 1 | SHT41 breakout marked SHT4X | I2C 0x44; 662K LDO + level shifter on board; no host-side pull-ups | 1 of 4 | J_SHT; VIN GND SCL SDA photo-verified
U3 | 1 | VEML7700 breakout HW-900 | I2C 0x10; LDO + level shifter + 103 array (~10k per line) | 1 of 3 | J_VEML; VIN 3VO GND SCL SDA photo-verified; 3VO left unwired
U4 | 1 | HLK-LD2410S | 24 GHz presence radar; 3.0-3.6 V; all pins 0-3.3 V | 1 of 1 | J_RAD; silkscreen 3V3 GND OT1 RX OT2 photo-verified against the manual
U5 | 1 | DS18B20 encapsulated probe 2.5 m | 1-Wire | 1 of 2 | J_1W; ring out cable colours; the only part that may leave the room
PCB | 1 | perfboard 14 x 20 holes double-sided (4 x 6 cm) | 2.54 mm | stock | elongated edge pads on both short edges; the row-1 strip sits under the USB overhang
S1;S2 | 2 | female header strip 8-pin | 2.54 mm | header stock | U1 socket rows at col 4 (row A) and col 11 (row B) rows 3-10
J_SHT | 1 | female header 4-pin | 2.54 mm | header stock | row 15 cols 1-4
J_VEML | 1 | female header 5-pin | 2.54 mm | header stock | row 15 cols 7-11
J_RAD | 1 | female header 5-pin | 2.54 mm (measure radar pins) | header stock | row 20 cols 1-5; radar upright; label side outward
J_1W | 1 | PCB screw terminal 3-pole | 5.08 mm assumed (measure) | 1 of 10 | row 20 cols 8/10/12; probe lead
R_PU_SDA;R_PU_SCL | 2 | resistor | 4.7 kOhm | E24 kit | row 14; bus stays on the board
R_1W | 1 | resistor | 4.7 kOhm | E24 kit | row 17; 1-Wire pull-up
C1;C_SHT;C_VEML;C_RAD | 4 | ceramic capacitor | 100 nF | ceramic assortment | one per supply pin
C_RAD_BULK | 1 | electrolytic capacitor low ESR | 100 uF >= 6.3 V | Elko assortment | row 18; radar transmit peaks ~118 mA; observe polarity
TP_3V3;TP_GND;TP_SDA;TP_SCL | 4 | test-point pin |  | stock | row 17

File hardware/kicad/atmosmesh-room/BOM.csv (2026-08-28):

Reference | Quantity | Value | Package | Fitting/verification note
U1 | 1 | ideaspark ESP32 1.14in TFT LCD board | 2x15 socket 2.54 mm THT | Pin names and order CONFIRMED from the operator pinout; 25.4 mm row spacing still to measure
J_VEML | 1 | 1x5 keyed header | 2.54 mm THT | CONFIRMED order VIN/3Vo/GND/SCL/SDA (operator 2026-08-28); 3Vo MUST BE NC
J_SHT | 1 | 1x4 keyed header | 2.54 mm THT | CONFIRMED order VIN/GND/SCL/SDA (operator 2026-08-28)
J_PIR | 1 | 1x3 keyed header | 2.54 mm THT | CONFIRMED order GND/OUT/protected-5V (operator 2026-08-28); verify supply voltage before closing JP_PIR_5V
J_BEEP | 1 | 1x3 keyed header | 2.54 mm THT | CONFIRMED Keyes 3-pin order S/VCC/- (operator 2026-08-28); active HIGH as on AtmosMesh v1
J_5V_EXT | 1 | 1x2 header | 2.54 mm THT | External 5 V input from the current-limited bench supply; GND common with the board
JP_5V_SRC | 1 | 1x3 header + ONE shunt | 2.54 mm THT | 5 V source select: 1-2 = board VIN, 2-3 = external. Exactly one shunt fits, by design
JP_PIR_5V | 1 | 2-pin jumper | 2.54 mm THT | DEFAULT OPEN
J_SDS | 1 | 1x4 keyed header | 2.54 mm THT | Carrier order 5V/GND/RXD/TXD; VERIFY the SDS011 module connector order before plugging in
JP_SDS_5V | 1 | 2-pin jumper | 2.54 mm THT | DEFAULT OPEN. Measure VIN under Wi-Fi load first: the SDS011 minimum is 4.7 V
R_SDS_RX R_SDS_TX | 2 | 1k | Axial THT 7.62 mm | UART series protection; bounds a driver fight to about 3.3 mA. NEVER omit
R_SDA R_SCL | 2 | 330R | Axial THT 7.62 mm | External I2C short-current limiting and edge damping; not a noise source
R_PU_SDA R_PU_SCL | 2 | 3.3k | Axial THT 7.62 mm | External I2C pull-ups. REQUIRED: the TFT board is SPI and has no onboard I2C device. 3k3 not 4k7 - see the sizing table in wiring.md
R_PIR_IN R_PIR_PU | 2 | 10k | Axial THT 7.62 mm | PIR base limit and GPIO33 pull-up
R_PIR_PD | 1 | 100k | Axial THT 7.62 mm | PIR base-emitter pull-down
R_LED_3V3 | 1 | 470R | Axial THT 7.62 mm | 3V3 live indicator series resistor; about 2.8 mA
R_LED_SDS R_LED_PIR | 2 | 1k | Axial THT 7.62 mm | 5 V domain live indicator series resistors; about 3 mA each
D_LED_3V3 D_LED_SDS D_LED_PIR | 3 | LED 3mm or 5mm | THT | RED or GREEN only - blue/white Vf ~3.0 V is too high for the 3V3 indicator. Cathode = short lead/flat to GND
R_BEEP_S | 1 | 100R | Axial THT 7.62 mm | Series protection GPIO25 to buzzer S. If silent step 100->47->22R measuring under 20 mA; wire link is a last resort
Q_PIR | 1 | 2N3904 | TO-92 CBE | Verify actual lead order; PIR active-low interface
D_PIR | 1 | 1N5819 | Axial THT 7.62 mm | Series in PIR 5 V only; band/cathode toward protected PIR rail
C1 C3 C4 C7 | 4 | 100nF | Ceramic THT 5 mm | Confirmed ceramic stock value (elektronik-inventar.md tops out at 100 nF); D-022 already allows 47-220 nF
C2 | 1 | 100uF >=6.3V | Radial THT 2 mm | Main 3.3 V bulk; observe polarity
C5 | 1 | 100uF >=10V | Radial THT 2 mm | PIR protected-5 V bulk; observe polarity
C6 | 1 | 470uF >=10V | Radial THT 2 mm | SDS011 protected-5 V bulk sized for the fan; observe polarity. CLOSE JP_SDS_5V BEFORE applying USB power, not while live
TP_3V3 TP_5V TP_GND TP_SDA TP_SCL | 5 | 2-pin test point pair | THT | Each signal/rail paired with GND for safe measurement
H1 H2 H3 H4 | 4 | M3 mounting hole | 3.2 mm NPTH | Keep metal hardware clear of wiring

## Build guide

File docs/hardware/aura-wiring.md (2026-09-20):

# AtmosMesh Aura — sensor wiring (CYD CN1)

Bench wiring for the [ESPHome spike](../../firmware/spike/README.md) and, later, the product.
Two I²C modules on one bus, on the only header the CYD gives us.

> **Read this first.** The CN1 pin order below comes from the community reference, not from a meter
> on *your* board. Reversing 3V3 and GND will destroy both sensor modules. **Verify with a
> multimeter before connecting anything** — the procedure is at the bottom and takes one minute.

Supersedes the four-module ENS160 + AHT20 + BME280 + VEML7700 arrangement. The gas sensor is now
the SGP40 alone and the light sensor is gone; see D-036 for why.

## The bus

Nothing here needs 5 V, nothing has a fan, and nothing draws enough to trouble the CYD's LDO.

```text
        CYD  ESP32-2432S028
   ┌──────────────────────────┐
   │                      CN1 │  4-pin 1.25 mm JST (the kit pigtail fits this)
   │                    ┌─────┤
   │                    │ 1 ● │──── GND ──────────┬──────────────┬─────────┐
   │                    │ 2 ● │──── GPIO22 = SCL ─┼────┬─────────┼────┐    │
   │                    │ 3 ● │──── GPIO27 = SDA ─┼─┬──┼─────────┼─┐  │    │
   │                    │ 4 ● │──── 3V3 ──────┬───┼─┼──┼───┬─────┼─┼──┼─┐  │
   └────────────────────┴─────┘               │   │ │  │   │     │ │  │ │  │
                                              │   │ │  │   │     │ │  │ │  │
                              10 µF ──────────┴───┼─┼──┼───┘     │ │  │ │  │
                              (at the branch,     │ │  │         │ │  │ │  │
                               + to 3V3, − to GND)│ │  │         │ │  │ │  │
                                                  │ │  │         │ │  │ │  │
        SGP40  "GY-SGP40"  @ 0x59  ───────────────┴─┴──┘         │ │  │ │  │
        ┌──────────────────────────┐                             │ │  │ │  │
        │ VCC / VIN  ←── 3V3       │   NOT photo-verified.       │ │  │ │  │
        │ GND        ←── GND       │   Read the silkscreen and   │ │  │ │  │
        │ SCL        ←── GPIO22    │   check for a regulator     │ │  │ │  │
        │ SDA        ←── GPIO27    │   before connecting.        │ │  │ │  │
        └──────────────────────────┘                             │ │  │ │  │
                                                                 │ │  │ │  │
        BME280  "GY-BM E/P 280"  @ 0x76  ────────────────────────┴─┴──┴─┴──┘
        ┌──────────────────────────┐
        │ VCC  ←── 3V3             │   PHOTO-VERIFIED 2026-09-04.
        │ GND  ←── GND             │   6-pin, front order:
        │ SCL  ←── GPIO22          │     VCC GND SCL SDA CSB SDO
        │ SDA  ←── GPIO27          │   No regulator → 3.3 V ONLY.
        │ CSB  ── leave open       │   CSB→VCC (I²C) and SDO→GND (0x76)
        │ SDO  ── leave open       │   are already strapped on the board.
        └──────────────────────────┘
```

| CN1 pin | Signal | To |
| ---: | --- | --- |
| 1 | GND | both modules' GND, capacitor − |
| 2 | GPIO22 | both modules' **SCL** |
| 3 | GPIO27 | both modules' **SDA** |
| 4 | 3V3 | both modules' VCC/VIN, capacitor + |

Four wires leave CN1 and fan out to both modules in parallel. That is all.

## Addresses — no collisions

| Device | Address | Set by |
| --- | --- | --- |
| SGP40 | `0x59` | fixed, not selectable (the SGP41 shares it — one or the other, never both) |
| BME280 | `0x76` | `SDO` strapped to GND on the purple board |

A boot scan showing exactly these two, and nothing else, is Q2 answered.

## Verify the SGP40 breakout before it goes on the bus

Its `inventory.md` row is operator-dictated, not photo-verified: supply and pin order are
**unconfirmed**. Before soldering, read the board and check three things.

- **Pin order.** `GY-` boards are not consistent between `VCC GND SCL SDA` and `VIN GND SDA SCL`.
  Trust the silkscreen on the part in your hand, not this diagram.
- **Regulator.** Look for a `662K`-marked SOT-23-5, the same XC6206-class LDO as the SHT41 board.
  Either way **3V3 is the correct feed**: the SGP40 die runs 1.7–3.6 V, so even after an LDO's
  dropout it stays well inside range. Never feed it 5 V on a "5 V tolerant" assumption.
- **Pull-ups.** If it carries a fitted `103` array, it contributes ~10 kΩ per line like the BME280.
  If the host-side pads are empty — as on the SHT41 board — the BME280's pull-ups carry the bus
  alone at ~10 kΩ, which is still fine at 100 kHz.

## Capacitors: one, and one place it must not go

- **Fit one 10 µF** across 3V3/GND where the pigtail branches to the two modules. The SGP40's
  hotplate is pulsed, and down thin pigtail wire that pulse droops the rail at the sensor — which
  modulates the very temperature the measurement depends on. The cap keeps the droop local.
- **100 nF at each module's supply pins is optional.** The photo-verified BME280 carries exactly
  one capacitor and no regulator; adequate for a part drawing microamps, but if the iron is already
  hot it removes a class of flaky behaviour you cannot diagnose inside a sealed gift.
- **Never put a capacitor on SDA or SCL.** I²C allows 400 pF of total bus capacitance and a long
  pigtail already spends part of it. Extra capacitance there slows the edges and turns a working
  bus into intermittent NAKs.

## Pull-ups: fit nothing

Both breakouts are expected to carry their own ~10 kΩ, so the bus sees roughly 5 kΩ per line.
**Do not add the 4.7 kΩ the original design sketched** — that would land near 2.4 kΩ, which is
legal but pointlessly stiff. Only revisit this if a scan actually fails.

## Placement matters more than the wiring

This is the part that decides whether the temperature reading is honest.

- **BME280 as far from the board as the pigtail allows**, out in moving room air. It is the reading
  the screen shows, and it is also the SGP40's humidity/temperature compensation source.
- **SGP40 near it but not touching it.** It is the only heater left in the build now that the
  ENS160 is gone, and it is a small one — which is precisely why dropping the ENS160 turned the
  self-heating question from a design risk into a footnote.
- Keep both off the back of the PCB. The ESP32, the TFT driver and the backlight all run warm, and
  a sensor pressed against them reads several degrees high.

## Verify before you connect — one minute, saves two modules

With the CYD powered over USB and **nothing** plugged into CN1:

1. Black probe on a known ground (the USB shell or a GND pad), red probe on each CN1 pin in turn.
2. Expect exactly one pin at **~3.3 V** and one at **0 V**. The two signal pins will read somewhere
   in between or float — that is fine, they are idle I²C lines with pull-ups.
3. **Confirm the 3.3 V pin is the one this document calls pin 4, and the 0 V pin is pin 1.**
   If the order is reversed — and pigtail wire colours are not trustworthy — re-map before wiring.
4. Note what you measured in `inventory.md`. That turns the community pin map into a measured one
   for this board, which is the whole point of the exercise.

If anything is unexpected, stop and say so rather than connecting. The modules cost little; the
hour spent working out why a bus is dead costs more.

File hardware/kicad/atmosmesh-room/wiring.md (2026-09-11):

# ROOM-01 wiring, protection, assembly and commissioning plan

This is the complete construction contract for the room carrier. It defines the intended nets and
safe build order, but it is **not approval to apply power**. The board is built by hand on a 31 × 27
perfboard ([`perfboard.md`](perfboard.md)), not fabricated.

The controller, VEML7700, SHT41, D-SUN PIR and buzzer connector orders are now operator-confirmed.
Still outstanding: the controller's physical row spacing, the SDS011 module's own connector order,
and every 5 V measurement. Never infer pin order or connector orientation from a generic product
photograph.

## Design decisions

### One 3.3 V domain for the controller and I²C sensors

The VEML7700 and SHT41 are powered directly from the Ideaspark board's confirmed `3V3` output. No
series diode and no 50 Ω sensor-supply resistor network is fitted. Every pull-up on this bus —
`R_PU_SDA`/`R_PU_SCL` and any on a breakout — references the same 3.3 V the sensors run from, so
dropping sensor VDD would drag the pull-ups down with it and buy no protection, while adding a
droop path under the SHT41's measurement current bursts. Direct 3.3 V keeps sensor VDD and every
pull-up on one rail.

An earlier revision justified this by the integrated OLED holding SDA/SCL at 3.3 V. That reasoning
was wrong for this hardware: the ideaspark 1.14 inch board's display is SPI and never touches
GPIO21/22. The conclusion stands, the reason does not.

Protection is instead provided by keyed connectors, staged measurements, local decoupling and
330 Ω series resistors in the *external* SDA/SCL branch. Those resistors limit current during a
signal short or wiring mistake and damp fast edges. They do **not** create appreciable measurement
noise. `C1`, `C3` and `C4` decouple power; their job is different from the series resistors.

`C1`, `C3`, `C4` and `C7` are **100 nF**. The recorded ceramic assortment in
[`elektronik-inventar.md`](../../../docs/elektronik-inventar.md) tops out at 100 nF, and D-022
already accepts anything from 47 nF to 220 nF here, so 100 nF is both stocked and correct. Do not
substitute electrolytics for these high-frequency ceramic capacitors.

### The carrier supplies the I²C pull-ups

Nothing on the controller board pulls SDA or SCL up: its display is SPI. `R_PU_SDA` and `R_PU_SCL`,
3.3 kΩ from `SDA_EXT`/`SCL_EXT` to 3.3 V, are therefore **required**, not optional. Without them a
build populated with only the SHT41, or with a breakout whose pull-ups are unfitted, leaves the bus
floating and every transaction fails.

They sit on the sensor side of `R_SDA`/`R_SCL` so the 330 Ω series resistors remain a fault-current
limit rather than part of the pull-up divider. If both breakouts carry their own 10 kΩ pull-ups the
parallel result is about 2.0 kΩ — roughly 1.6 mA at 3.3 V, inside the I²C 3 mA sink limit — so keep
them fitted. After assembly, measure the unpowered resistance from SDA to 3.3 V and SCL to 3.3 V,
then verify idle-high voltage when powered.

### Domain indicators

Both 5 V jumpers are default-open, and the build plan tells you to leave them open until the
measurements are recorded. Until now there was no way to see whether a domain was live.

| LED | Rail | Resistor | Current | Lit means |
| --- | --- | --- | ---: | --- |
| `D_LED_3V3` | `+3V3` | `R_LED_3V3` 470 Ω | ~2.8 mA | the board has 3.3 V |
| `D_LED_SDS` | `SDS_5V_PROTECTED` | `R_LED_SDS` 1 kΩ | ~3.0 mA | `JP_SDS_5V` is **closed** |
| `D_LED_PIR` | `PIR_5V_PROTECTED` | `R_LED_PIR` 1 kΩ | ~3.0 mA | `JP_PIR_5V` is **closed** |

Each 5 V indicator draws through its own jumper. That is the feature, not a side effect: the LED
cannot light unless the jumper it reports on is actually closed.

> **Use a red or green LED, not blue or white.** The sizing assumes a forward voltage near 2.0 V.
> A blue or white LED drops about 3.0 V, which leaves 0.3 V across `R_LED_3V3` on the 3.3 V rail —
> roughly 0.6 mA, and it will look dead. On the 5 V rails a blue LED still works but runs dim.

Anode to the rail through the resistor, cathode to GND. On a bare LED the **short lead and the flat
on the rim are the cathode**; do not infer polarity from lead length alone on a used part.

### Resistor sizing

The operator holds a complete E24 kit, so every value below is the electrically chosen one, not the
nearest thing in a drawer.

| Ref | Value | Why this value |
| --- | ---: | --- |
| `R_PU_SDA`, `R_PU_SCL` | 3.3 kΩ | Rise time is the binding constraint on hand-wired perfboard. At 100 kHz I²C allows 1000 ns. Assuming ~200 pF of hand-soldered bus capacitance, 4.7 kΩ gives 940 ns — right on the limit — while 3.3 kΩ gives 660 ns. Sink stays at 1.0 mA alone, or 1.6 mA with two 10 kΩ breakout pull-ups in parallel, against the 3 mA I²C limit. **Changed from 4.7 kΩ when the build moved to perfboard.** |
| `R_SDA`, `R_SCL` | 330 Ω | Fault-current limiting is the primary job: 3.3 V / 330 Ω = 10 mA, comfortably under the 40 mA GPIO maximum. The cost is a divider against the pull-ups when the ESP32 drives low — sensors then see 3.3 V × 330 / (2030 + 330) = 0.46 V, still well under the 0.99 V I²C VIL. Dropping to 220 Ω would improve that margin but push fault current to 15 mA for no real gain. |
| `R_SDS_RX`, `R_SDS_TX` | 1 kΩ | Sized to bound a UART driver fight to 3.3 V / 1 kΩ ≈ 3.3 mA against the 40 mA maximum. Signal cost is nil: 1 kΩ into a few hundred pF settles in ~200 ns against a 104 µs bit at 9600 baud. Also limits clamp current to ~1.4 mA if a 5 V module is ever fitted by mistake. |
| `R_PIR_IN` | 10 kΩ | Base drive for `Q_PIR`. Collector current is only 3.3 V / 10 kΩ = 0.33 mA through `R_PIR_PU`, needing ~33 µA of base current for a forced β of 10. 10 kΩ supplies (3.3 − 0.7) / 10 kΩ = 260 µA — deep saturation with 8× margin, while loading the PIR output with a quarter of a milliamp. |
| `R_PIR_PU` | 10 kΩ | Collector pull-up holding GPIO33 high when the PIR is idle. Keeps `Q_PIR` collector current at 0.33 mA, which is what makes the 10 kΩ base resistor comfortable. |
| `R_PIR_PD` | 100 kΩ | Defines `Q_PIR`'s base if the PIR output floats or is removed. Ten times `R_PIR_IN`, so it costs about 9% of the base drive and cannot prevent turn-on. |
| `R_LED_3V3` | 470 Ω | 3.3 V rail less a ~2.0 V red LED leaves 1.3 V; 1.3 V / 470 Ω = 2.8 mA. Bright enough to read across a room, negligible against the rail budget. |
| `R_LED_SDS`, `R_LED_PIR` | 1 kΩ | 5 V rail less a ~2.0 V LED leaves 3.0 V; 3.0 V / 1 kΩ = 3.0 mA. Deliberately the same order as the 3.3 V indicator so all three read at similar brightness. |
| `R_BEEP_S` | 100 Ω | The one value that is safe across all three transducer types, so it stays until the ohmmeter test names the load. Piezo: `Xc` is about 3.5 kΩ at 2.3 kHz, so 100 Ω costs no audible volume. Active: a can drawing ~25 mA looks like ~130 Ω, so 100 Ω leaves it only ~1.9 V of the 3.3 V — enough to be weak, which is exactly what the step-down rule is for. Magnetic worst case: ~28 mA for 50 ms, under the 40 mA absolute maximum. **Never raise it** — on the active and magnetic loads a larger value is silence, not protection. |

### Five-pin VEML7700 connector

The confirmed module header order is `VIN`, `3Vo`, `GND`, `SCL`, `SDA`.

| `J_VEML` pin | Module label | Carrier connection | Rule |
| ---: | --- | --- | --- |
| 1 | `VIN` | direct `3V3` | Supply the breakout here, even though it accepts a wider VIN range |
| 2 | `3Vo` | **NC** | Regulator output; never drive it and never tie it to `3V3` |
| 3 | `GND` | GND | Common 0 V reference |
| 4 | `SCL` | `SCL_EXT` after `R_SCL` 330 Ω | Pulled up by `R_PU_SCL` 3.3 kΩ |
| 5 | `SDA` | `SDA_EXT` after `R_SDA` 330 Ω | Pulled up by `R_PU_SDA` 3.3 kΩ |

The VEML7700 address is `0x10`. Place `C3` 220 nF between `VIN` and GND beside this connector.

## Complete net-by-net wiring

### ideaspark ESP32 1.14 inch TFT LCD board (`U1`)

Pin names and order are confirmed from
[`docs/hardware/ideaspark-esp32-tft-pinout.png`](../../../docs/hardware/ideaspark-esp32-tft-pinout.png).
Socket pads 1–15 are the left column and 16–30 the right column, both counted from the USB/button
end:

| Pad | Name | Pad | Name |
| ---: | --- | ---: | --- |
| 1 | VIN | 16 | 3V3 |
| 2 | GND | 17 | GND |
| 3 | GPIO13 | 18 | **GPIO15 — TFT CS** |
| 4 | **GPIO12 — flash strap** | 19 | **GPIO2 — TFT DC** |
| 5 | GPIO14 | 20 | **GPIO4 — TFT RST** |
| 6 | GPIO27 | 21 | GPIO16 / RX2 |
| 7 | GPIO26 | 22 | GPIO17 / TX2 |
| 8 | GPIO25 | 23 | GPIO5 |
| 9 | GPIO33 | 24 | **GPIO18 — TFT SCLK** |
| 10 | **GPIO32 — TFT backlight** | 25 | GPIO19 |
| 11 | GPIO35 | 26 | GPIO21 / SDA |
| 12 | GPIO34 | 27 | **GPIO3 — RX0** |
| 13 | GPIO39 / VN | 28 | **GPIO1 — TX0** |
| 14 | GPIO36 / VP | 29 | GPIO22 / SCL |
| 15 | EN | 30 | **GPIO23 — TFT MOSI** |

Bold pins are off-limits to the carrier. The row spacing is still assumed to be 25.4 mm — measure
the actual board before cutting a socket or committing a hole pattern.

| Controller signal | Carrier net/use |
| --- | --- |
| `3V3` | Direct 3.3 V rail for sensors, pull-ups, buzzer and `C1`/`C2` |
| GND | Common ground; both controller GND pins join the ground rail |
| USB/`5V` or `VIN` | `+5V_USB_CONFIRMED`; PIR path only, behind default-open `JP_PIR_5V` |
| GPIO21 (pad 26) | Controller side of `R_SDA` 330 Ω |
| GPIO22 (pad 29) | Controller side of `R_SCL` 330 Ω |
| GPIO25 | `R_BEEP_IN` 2.2 kΩ to buzzer-driver base |
| GPIO33 | Active-low PIR input: Q_PIR collector plus `R_PIR_PU` 10 kΩ to 3.3 V |
| GPIO2, 4, 15, 18, 23, 32 | **Never wire.** The board's own 1.14 inch TFT drives them |
| GPIO12 | **Never wire.** Flash-voltage strap; high at boot can stop the board starting |
| GPIO1, GPIO3, EN | **Never wire.** CP2102 USB-UART and reset |

Fit `C1` 220 nF and `C2` 10–47 µF from 3.3 V to GND close to the controller sockets. `C2` is
polarized: positive to 3.3 V, negative to GND.

### External I²C branch

```text
                                        R_PU_SDA 3k3 ── +3V3
                                                     │
GPIO21 (pad 26) ── R_SDA 330 Ω ── SDA_EXT ───────────┼─ VEML7700 SDA
                                                     └─ SHT41 SDA

                                        R_PU_SCL 3k3 ── +3V3
                                                     │
GPIO22 (pad 29) ── R_SCL 330 Ω ── SCL_EXT ───────────┼─ VEML7700 SCL
                                                     └─ SHT41 SCL
```

The 330 Ω resistors belong near the ESP32 branch point. Do not put capacitors on SDA or SCL.
Operate at 100 kHz for first commissioning. Expected addresses are VEML7700 `0x10` and SHT41
`0x44`. There is no third I²C device: the display is SPI, so a scan that reports `0x3C`/`0x3D`
means something unexpected is on the bus.

### SHT41 (`J_SHT`)

Operator-confirmed order, 2026-08-28.

| Pin | Module label | Carrier connection |
| ---: | --- | --- |
| 1 | `VIN` | direct 3.3 V |
| 2 | `GND` | GND |
| 3 | `SCL` | `SCL_EXT` |
| 4 | `SDA` | `SDA_EXT` |

An earlier revision had pins 3 and 4 as SDA then SCL. Fitting the module against that order would
have crossed the bus and left every transaction failing.

Fit `C4` 220 nF directly between SHT41 VCC and GND at `J_SHT`. Place the module at a ventilated
board edge, away from the ESP32 regulator, PIR regulator, buzzer and enclosure heat sources.

### D-SUN PIR protected interface

The D-SUN header order is operator-confirmed as **GND, OUT, VCC** (2026-08-28). Its supply voltage
and output swing are still unmeasured, so keep `JP_PIR_5V` open until measured.

| Pin | Module label | Carrier net |
| ---: | --- | --- |
| 1 | `GND` | `GND` |
| 2 | `OUT` | `PIR_OUT`, into `R_PIR_IN` 10 kΩ |
| 3 | `VCC` | `PIR_5V_PROTECTED` |

An earlier revision had this header as 5 V / GND / OUT. Fitting the module against that order would
have put 5 V on its ground pin.

```text
confirmed USB/5V ── JP_PIR_5V DEFAULT OPEN ── D_PIR 1N5819 ── PIR protected VCC
                                                              │
                                                            C5 10 µF
                                                              │
                                                             GND

PIR OUT ── R_PIR_IN 10 kΩ ── Q_PIR base
Q_PIR base ── R_PIR_PD 100 kΩ ── GND
Q_PIR emitter ── GND
Q_PIR collector ── GPIO33
GPIO33 ── R_PIR_PU 10 kΩ ── 3.3 V
```

`D_PIR` is in the PIR 5 V *power* path only. Fit its band/cathode toward `PIR_5V_PROTECTED`.
The NPN prevents PIR output voltage from reaching GPIO33 directly and inverts the logic:

| PIR state | Q_PIR | GPIO33 |
| --- | --- | --- |
| inactive/output low | off | HIGH |
| active/output high | on | LOW |

Firmware must therefore treat GPIO33 LOW as motion **once this carrier exists**. Verify the actual
transistor's C/B/E order with a datasheet or diode-test measurement; do not trust flat-face folklore.

Until the carrier exists, the module's OUT reaches GPIO33 directly on the dev board, and the
theoretical expectation was motion HIGH. **Field correction (ROOM-05 / D-035, operator
2026-08-31):** the live `atmosmesh-room-v1` board — still the direct dev-board wiring, no Q_PIR
built — was observed with MQTT occupancy inverted (motion reported present with an empty room and
absent with someone in view). The installed PIR module's own OUT idles HIGH and goes LOW on
motion, matching the carrier's *logical* polarity even though the carrier's inverting transistor
is not physically present. So the canonical `[env:atmosmesh-room-v1]` in `platformio.ini` now
defines `-DATMOSMESH_ROOM_PIR_ACTIVE_LOW` to match reality; `room_pins.hpp`'s un-flagged default
stays active-high only as the theoretical case for a *different* PIR module wired without
inversion. Building the carrier's Q_PIR later does not change anything here, since the live module
already reads active-low without it — re-verify polarity on that occasion rather than assuming.

> **The protection is part of the transistor, not just the inversion.** `Q_PIR` is what keeps PIR
> output voltage off GPIO33, and this module's supply and output swing are still unmeasured. On a
> direct dev-board wire that protection is absent: measure OUT idle and triggered before trusting
> it to a GPIO, or run the module from 3.3 V if it will.

### SDS011 particulate sensor (`J_SDS`)

5 V fan and laser, **3.3 V TTL** UART at 9600 8N1. The sensor reports autonomously at 1 Hz.

| Pin | Carrier net | Goes to |
| ---: | --- | --- |
| 1 | `SDS_5V_PROTECTED` | sensor 5 V, behind `JP_SDS_5V` |
| 2 | `GND` | sensor GND |
| 3 | `SDS_RXD` | sensor **RXD**, from GPIO17/TX2 through `R_SDS_TX` 1 kΩ |
| 4 | `SDS_TXD` | sensor **TXD**, to GPIO16/RX2 through `R_SDS_RX` 1 kΩ |

> **The sensor is terminated by the 4-wire cable from its USB2TT004 adapter kit** (operator-confirmed
> 2026-08-28), not by the bare 7-pin header. That cable remaps the header, and **wire colours vary
> between kits** — so a colour is a claim, not evidence, and no colour convention is recorded here on
> purpose.
>
> **Ring the cable out instead.** With everything unpowered, put a continuity meter between each
> cable end and the pads of the sensor's own 7-pin header, and label the wire by the header position
> it reaches:
>
> | Header pin | Signal | Carrier net |
> | ---: | --- | --- |
> | 3 | 5 V | `SDS_5V_PROTECTED` |
> | 5 | GND | `GND` |
> | 6 | RXD (into the sensor) | `SDS_RXD` |
> | 7 | TXD (out of the sensor) | `SDS_TXD` |
>
> Pins 1 (NC), 2 and 4 (the PWM outputs) are unused. Four continuity readings close this item
> permanently; a photograph or a remembered colour order does not.

#### The UART must be crossed

```text
SDS011 TXD ── R_SDS_RX 1 kΩ ── GPIO16 / RX2   (pad 21)
SDS011 RXD ── R_SDS_TX 1 kΩ ── GPIO17 / TX2   (pad 22)
```

On 2026-08-17 this was wired straight through on the bench: the sensor's TXD landed on the ESP32's
TX2. Both are push-pull outputs, so they fought on one net for roughly 10 ms in every second, and
the ESP32 GPIO absolute maximum is 40 mA. `generate_project.py` now refuses to emit a
straight-through SDS011 UART, and the refusal is mutation-proved.

The 1 kΩ series resistors are the additional protection. They bound a driver fight to about
3.3 V / 1 kΩ ≈ **3.3 mA** instead of a short. At 9600 baud a bit is 104 µs, while 1 kΩ against a
few hundred pF of wiring is a couple of hundred nanoseconds, so they cost nothing in signal terms.

#### Where the 5 V comes from

`JP_5V_SRC` selects the source for `+5V_DOMAIN`, which feeds both `JP_PIR_5V` and `JP_SDS_5V`.

| Shunt | Source | Use |
| --- | --- | --- |
| pins 1–2 | `+5V_USB_CONFIRMED`, the board's `VIN` | normal standalone operation |
| pins 2–3 | `+5V_EXT`, from `J_5V_EXT` | bench bring-up and any run with the SDS011 fan |

A 3-pin header takes **exactly one** 2-pin shunt, so the two sources cannot be bridged. That
matters: bridging them would push a bench supply back into the host's USB port. `generate_project.py`
refuses to flatten this into two independent jumpers.

**Use the external supply for first power-up.** The operator's lab supply has an adjustable current
limit, and a current-limited bring-up is the cheapest protection this project can buy — it turns a
wiring error from a destroyed part into a supply that simply refuses to deliver. Set the limit just
above the expected draw, not at the supply's maximum.

Feeding the 5 V domain externally also **removes the shared-rail problem** rather than measuring
around it. `spec-comparison.md` puts the USB rail near 650 mA peak coincidence before the SDS011
fan is added, and says 700 mA is not comfortable. With the shunt on 2–3 the fan is not on the USB
rail at all. `J_5V_EXT` GND is common with the board — connect it, or nothing has a return path.

#### 5 V supply — and why there is no diode here

`JP_SDS_5V` is **DEFAULT OPEN**, the same pattern as `JP_PIR_5V`. `C6` 10 µF and `C7` 220 nF sit on
the protected side.

There is deliberately **no series Schottky**, unlike the PIR rail. The SDS011 minimum is **4.7 V**
(`spec-comparison.md`), and a 1N5819 drops roughly 0.3–0.4 V at fan current — landing under the
minimum before any USB droop is counted. The jumper provides the same isolation at zero volts.
`generate_project.py` refuses to place a diode on this rail.

**Two power facts are assumed and must be measured before this jumper is closed:**

1. `+5V_USB_CONFIRMED` comes from the board's `VIN` pin (pad 1). On many dev boards `VIN` sits
   behind a diode from USB VBUS, so it may already be near 4.6–4.7 V under load. Measure `VIN` with
   Wi-Fi active before trusting the 4.7 V floor.
2. `spec-comparison.md` already puts the shared 5 V rail at roughly **650 mA peak coincidence**
   without the SDS011, and says 700 mA is not comfortable. Adding a fan to a USB-fed carrier is a
   power-budget claim, not a given.

The SDS011 ripple specification is < 20 mV, and `C6` is **470 µF** to meet it. The electrolytic
assortment runs to 1000 µF, so this is no longer a stock compromise — an earlier 10 µF value was
never shown to hold 20 mV against a fan load. Still measure the rail with a scope during
commissioning with the HANTEK DSO2D15 recorded in
[`elektronik-inventar.md`](../../../docs/elektronik-inventar.md); a chosen value is not a measured
one. The same instrument settles the other assumption on this board: `R_PU_SDA`/`R_PU_SCL` were
sized against an *assumed* ~200 pF of bus capacitance, and the real I²C rise time can be measured
once the perfboard exists.

> **Close `JP_SDS_5V` before applying USB power, not while live.** Closing it onto a charged rail
> dumps the inrush of a discharged 470 µF into the shared 5 V supply and can brown out the ESP32.

### Buzzer (`J_BEEP`)

Operator-confirmed 2026-08-28: a no-name **Keyes 3-pin breakout**, black cylinder with a single
hole, header order **S / VCC / −**. The operator inspected the breakout on 2026-08-28: there are
**no active parts on the little PCB**, only the cylinder and the header.

That does not make it a passive element — the oscillator is inside the can, not on the board.
AtmosMesh v1 drives this same part from GPIO25 with a bare 50 ms `digitalWrite(HIGH)`
(`firmware/src/products/atmosmesh_v1.cpp`), a DC level with no `tone()` and no PWM, and
`firmware/README.md` records that as working boot and PIR-edge behaviour. A piezo disc is a
capacitor, so a DC step gives one tick per edge rather than a 50 ms tone; a passive magnetic coil
would click *and* draw far more from the pin than a GPIO should source. Only a **self-oscillating**
transducer produces the sound v1 actually ships, so no external transistor is fitted.

| Pin | Module label | Carrier net |
| ---: | --- | --- |
| 1 | `S` | `BEEP_S`, from GPIO25 through `R_BEEP_S` 100 Ω |
| 2 | (unlabelled) `VCC` | direct 3.3 V — a no-op on this module class, see below |
| 3 | `−` | GND |

```text
GPIO25 (pad 8) ── R_BEEP_S 100 Ω ── S
                              3V3 ── VCC
                              GND ── −
```

Logic is **active HIGH**, matching v1. There is no flyback diode: a self-oscillating can keeps its
own switching behind its own internals, so no inductive kick reaches the header.

On this module class the transducer sits directly between `S` and `−`, which leaves the middle pin
**not connected** and makes the 3.3 V feed a no-op. It stays wired because it is harmless and it
covers the variant that does use it, but nothing on the carrier may assume it powers anything: the
buzzer's entire operating current is sourced by GPIO25.

> **Settle the transducer type with one ohmmeter reading before Stage 5**, taken across `S` and `−`
> with the module off the carrier and nothing powered:
>
> | Reading | Transducer | Consequence |
> | --- | --- | --- |
> | open / megohms | piezo disc | needs bounded 2–4 kHz PWM, not DC; `R_BEEP_S` barely affects volume |
> | ~16–42 Ω | passive magnetic coil | DC drive is forbidden; needs PWM **and** a low-side NPN |
> | hundreds of Ω to kΩ, **and different when the leads are swapped** | active, internal oscillator | the expected result; v1's DC drive is correct |
>
> The swapped-lead asymmetry is the tell — it is the ohmmeter seeing a semiconductor junction inside
> the can. The reasoning above says this *should* read as active. The measurement is what turns that
> inference into a fact, and it costs one probe touch.

> **If the buzzer is silent, do not raise the drive — lower the resistor, one E24 step at a time.**
> Some Keyes buzzer boards put the sounder straight across `S` and `−` with no onboard transistor.
> On such a module 100 Ω drops most of the supply and it will barely click. Step down through the
> kit — 100 → 47 → 22 Ω — measuring the current into `S` during a beep at each step, and stop at the
> largest value that gives acceptable volume. The current must stay **under 20 mA**; the ESP32 GPIO
> absolute maximum is 40 mA. A wire link is the last resort, not the first move, and if even 22 Ω
> exceeds 20 mA then fit a low-side NPN on the `−` pin rather than driving `S` harder.

`R_BEEP_S` starts at 100 Ω deliberately: the protective value is the default, and the bench
measurement is what authorises reducing it.

### Stage 1 — controller alone

1. Keep all modules removed and `JP_PIR_5V` open.
2. Power the Ideaspark board through USB only, outside the carrier. Measure its labelled `3V3`, GND
   and possible USB/5 V pin. The 3.3 V measurement must be approximately 3.3 V.
3. Remove USB, insert the controller in the verified orientation, and power by USB again.
4. Measure `TP_3V3`, `TP_5V`, SDA and SCL relative to `TP_GND`. Stop immediately if 5 V appears on
   3.3 V, SDA, SCL, GPIO25 or GPIO33.
5. Verify the I²C bus is idle-high and that a scan finds no device before the sensors are fitted.

### Stage 2 — VEML7700

1. Remove USB. Connect `VIN`, `GND`, `SCL`, `SDA`; leave `3Vo` physically isolated.
2. Power USB and verify idle SDA/SCL near 3.3 V.
3. Scan for `0x10` and read a stable lux response under dark and bright conditions.
4. Confirm the TFT backlight does not dominate the lux result; add or adjust the opaque divider.

### Stage 3 — SHT41

1. Remove USB, attach the SHT41 using its photographed pin order, then restore USB.
2. Scan for both `0x10` and `0x44`. Missing devices must be reported as unavailable,
   never numeric zero.
3. Compare temperature/humidity to a nearby reference after thermal settling. Touching or breathing
   on the sensor may be used only as a response test, not calibration evidence.

### Stage 4 — PIR

1. Characterize the PIR separately: required supply, idle output and active output voltage.
2. With USB removed, connect the PIR and close `JP_PIR_5V` only if its 5 V requirement and the
   controller's USB/5 V source pin are confirmed.
3. Restore USB. Measure `PIR_5V_PROTECTED`, Q_PIR base and GPIO33 in idle and motion states.
4. Confirm GPIO33 never exceeds 3.3 V and logic is active-low. Exercise repeated motion and timeout.

### Stage 5 — buzzer

1. Leave `D_BEEP` empty. Connect the buzzer with confirmed polarity and 3.3 V supply.
2. Drive GPIO25 for at most 250 ms. Identify active versus passive behavior as described above.
3. Measure current and verify Q_BEEP remains cool. For passive piezo, test bounded 2–4 kHz PWM.

### Stage 6 — combined run

Run all functions for at least 30 minutes while checking 3.3 V stability, sensor presence, TFT
updates, PIR transitions, buzzer behavior and component temperature. Then test USB power removal and
restoration. Do not leave the station unattended until this passes and the wiring photographs are
reviewed.

## Stop conditions

Disconnect USB immediately for any wrong rail voltage, hot part, smell, unstable reset loop, 5 V on
an I²C/GPIO net, missing ground, unexpected continuity to `3Vo`, or transistor whose lead order is
uncertain. Correct and repeat from the unpowered checks; never troubleshoot by moving live wires.

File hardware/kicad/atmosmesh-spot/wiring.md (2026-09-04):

# AtmosMesh Spot, first unit — bill of materials, layout and wiring

The first Spot is **SHT41 + VEML7700 + HLK-LD2410S on the board and a DS18B20 probe on a
terminal**. No BME280: the outdoor-cable variant drawn on 4 September was withdrawn by the operator
on 5 September, and with it the 4-pole terminal, the 100 Ω series resistors, the rail clamps and
the 2.2 kΩ pull-ups. Story: [`SP-01`](../../../agent-context/stories/SP-01.md). Companion drawings:
[`atmosmesh-spot-layout.svg`](atmosmesh-spot-layout.svg) (hole-by-hole placement) and
[`atmosmesh-spot-wiring.svg`](atmosmesh-spot-wiring.svg) (schematic-style net drawing, every
pin by its printed name).

**One 3.3 V domain.** The SuperMini's `5V` pin is not wired to anything. Every part below is
datasheet-, photo- or scan-confirmed to run from 3.3 V, and no signal on the board can exceed
3.3 V. This document is a build contract, not power approval: the unpowered checks and the staged
bring-up at the end still apply.

Evidence level per part:

| Part | Pin order | Electrical | Source |
| --- | --- | --- | --- |
| ESP32-C3 SuperMini OLED | **photo-confirmed** silkscreen; **OLED at 0x3C on GPIO5/GPIO6 by scan** | 3.3 V logic, on-board LDO | photo pass and `firmware/tools/c3scan`, 4 September |
| HLK-LD2410S | **confirmed**, manual Table 3-2 and silkscreen | **confirmed**, 3.0–3.6 V, all pins 0–3.3 V | [`docs/hardware/datasheets/`](../../../docs/hardware/datasheets/README.md) |
| SHT41, VEML7700 | **photo-confirmed** on the spares, 4 September | 3.3 V into their own LDO and level shifter | photo pass, inventory |
| DS18B20 probe | cable colours are a claim; **ring out** | 3.3 V, powered mode | Maxim datasheet (to file) |

The photos themselves were deleted after evaluation at the operator's request; the facts they
established are in `docs/hardware/inventory.md` under the 4 September photo pass.

## 1. Bill of materials

Everything is in stock. Reference designators match SP-01.

| Ref | Qty | Part | Value / type | From stock | Note |
| --- | ---: | --- | --- | --- | --- |
| `U1` | 1 | ESP32-C3 SuperMini with 0.42" OLED | rev 4, 4 MB, MAC `E4:EC:E6:92:05:D4` | 1 of 5 | The scanned board |
| `U2` | 1 | SHT41 breakout, `SHT4X` board | I²C `0x44` | 1 of 4 (last free one after Room and Room v2) | `J_SHT` |
| `U3` | 1 | VEML7700 breakout, `HW-900` | I²C `0x10` | 1 of 3 | `J_VEML` |
| `U4` | 1 | HLK-LD2410S | 24 GHz presence radar | 1 of 1 | `J_RAD` |
| `U5` | 1 | DS18B20 encapsulated probe, 2.5 m | 1-Wire | 1 of 2 | `J_1W` |
| `PCB` | 1 | perfboard 14 × 20 holes, 2.54 mm, double-sided (4 × 6 cm) | — | stock | edge pads on both short edges |
| `S1`, `S2` | 2 | female header strip, 8-pin | 2.54 mm | header stock | U1 socket rows; the board stays removable |
| `J_SHT` | 1 | female header, 4-pin | 2.54 mm | header stock | |
| `J_VEML` | 1 | female header, 5-pin | 2.54 mm | header stock | pin 2 (`3VO`) left unwired |
| `J_RAD` | 1 | female header, 5-pin | 2.54 mm (measure the radar's pins first) | header stock | radar stands upright |
| `J_1W` | 1 | PCB screw terminal, 3-pole | 5.08 mm assumed — measure | 1 of 10 | probe lead |
| `R_PU_SDA`, `R_PU_SCL` | 2 | resistor | 4.7 kΩ | E24 kit | bus stays on the board |
| `R_1W` | 1 | resistor | 4.7 kΩ | E24 kit | 1-Wire pull-up |
| `C1`, `C_SHT`, `C_VEML`, `C_RAD` | 4 | ceramic capacitor | 100 nF | ceramic assortment | one per supply pin |
| `C_RAD_BULK` | 1 | electrolytic, low ESR | 100 µF, ≥ 6.3 V | Elko assortment | radar transmit peaks (~118 mA) |
| `TP_3V3`, `TP_GND`, `TP_SDA`, `TP_SCL` | 4 | test-point pin | — | stock | |

Removed on 5 September with the BME280: `J_OUT`, `R_OUT_SDA`/`R_OUT_SCL`, `D_CL1`–`D_CL4`, `C_OUT`,
the cable and the shield.

Stock after this build: 4 SuperMinis, 1 SHT41 free (of 4: Room, Room v2, Spot), 1 VEML7700 free,
0 LD2410S, 1 DS18B20, all 6 BME280 unassigned.

## 2. Controller: ESP32-C3 SuperMini OLED (`U1`)

Two rows of eight pins. **Photo-verified silkscreen, 4 September.** With the USB socket toward
row 1 and the OLED facing up, row A is the side carrying the `PWR` LED and the `IO8` LED, row B
the other side. In the layout below row A is column 4 and row B column 11; if your board sits
the other way round when the USB points at row 1, swap the columns, never the net list.

| Row A (col 4), from the USB end | Row B (col 11), from the USB end |
| --- | --- |
| `5V` — **not wired** | `10` GPIO10 |
| `GD` GND | `9` GPIO9 — BOOT button, strapping: unused |
| `3V` 3V3 — the rail | `8` GPIO8 — `IO8` LED, strapping: unused |
| `RX` GPIO20 — UART0 RX ← radar `OT1` | `7` GPIO7 |
| `TX` GPIO21 — UART0 TX → radar `RX` | `6` GPIO6 — SCL (scan-confirmed: OLED at 0x3C) |
| `2` GPIO2 — strapping: unused | `5` GPIO5 — SDA (scan-confirmed) |
| `1` GPIO1 — ADC-capable, kept free | `4` GPIO4 — 1-Wire |
| `0` GPIO0 — ADC-capable, kept free | `3` GPIO3 — radar `OT2` |

> **Why the marked `RX`/`TX` pins carry the radar (changed 5 September).** On this board the
> USB console is the chip's native USB-serial, so UART0 on GPIO20/21 is a free hardware UART
> (`Serial0` in the Arduino core, `Serial` being USB). The Room v1 rule "never put a sensor on
> UART0" does not apply here: that board's UART0 *was* the console. The one side effect is the
> ROM boot log, which the ESP32-C3 prints on `TX` at 115200 baud at every reset and the radar
> therefore receives; it cannot form a radar command (those need the `FD FC FB FA` header and a
> valid length), so it is harmless. Using the labelled pins keeps GPIO0/GPIO1, two of the five
> ADC pins, free for a later analog sensor.

Beyond pin `0`/`3` the module continues for about two more pitches: `RST` and `BOOT` buttons and
a small red part with a white dot, presumed to be the antenna. That end is the keep-out.

> **Row spacing is settled:** the operator pushed the module into this perfboard on 4 September
> and it fits with three free columns on each side, so the rows are **7 pitches (17.78 mm)**
> apart at columns 4 and 11. **The OLED's I²C pins are settled too:** the scanner in
> `firmware/tools/c3scan`, run on this board on 4 September, found the OLED at `0x3C` on
> SDA = GPIO5, SCL = GPIO6 and nothing on any other pair. Nothing about `U1` is an assumption
> any more; only the row-A/row-B side when the USB faces row 1 is checked once at the dry-fit.

Firmware limits Wi-Fi TX power to about 8.5 dBm at start-up (ceramic antenna).

## 3. Board layout — 14 × 20 holes (35.6 × 50.8 mm)

Columns 1–14 left to right, rows 1–20 top to bottom, component side, USB toward row 1. Header and
terminal positions are exact; passives go in the row named for them, exact holes are the
builder's choice within that row.

```text
        col 1   2   3   4   5   6   7   8   9  10  11  12  13  14
       ┌────────────────────────────────────────────────────────────┐
row 1  │              [ USB-C overhangs this edge ]                 │  edge pads under the module: unused
row 2  │  ·   ·   ·   ·   ·   ·   ·   ·   ·   ·   ·   ·   ·   ·   │
row 3  │  ·   ·   ·  (5V)  ·   ·   ·   ·   ·   ·  (G10) ·   ·   ·   │  ← U1 socket pins: col 4 (row A) and col 11 (row B)
row 4  │  ·   ·   ·  (GND) ·   ·   ·   ·   ·   ·  (G9)  ·   ·   ·   │     7 pitches apart (dry-fit confirmed 4 Sept)
row 5  │  ·   ·   ·  (3V3) ·   ·   ·   ·   ·   ·  (G8)  ·   ·   ·   │
row 6  │  ·   ·   ·  (G20) ·   ·   ·   ·   ·   ·  (G7)  ·   ·   ·   │
row 7  │  ·   ·   ·  (G21) ·   ·   ·   ·   ·   ·  (G6)  ·   ·   ·   │
row 8  │  ·   ·   ·  (G2)  ·   ·   ·   ·   ·   ·  (G5)  ·   ·   ·   │
row 9  │  ×   ×   ·  (G1)  ·   ·   ·   ·   ·   ·  (G4)  ·   ×   ×   │  × = keep-out: no copper, no wire,
row 10 │  ×   ×   ·  (G0)  ·   ·   ·   ·   ·   ·  (G3)  ·   ×   ×   │      no coating — buttons and antenna
row 11 │  ×   ×   ×   ×   ×   ×   ×   ×   ×   ×   ×   ×   ×   ×   │      end of the module, rows 11–13
row 12 │  ×   ×   ×   ×   ×   ×   ×   ×   ×   ×   ×   ×   ×   ×   │
row 13 │  ×   ×   ×   ×   ×   ×   ×   ×   ×   ×   ×   ×   ×   ×   │
row 14 │ [R_PU_SDA 4k7] [R_PU_SCL 4k7]    [C1 100n]    ·   ·   ·   │
row 15 │ [J_SHT: VIN GND SCL SDA] · [J_VEML: VIN 3VO GND SCL SDA]   │  both modules standing upright
row 16 │ [C_SHT]   ·   ·   ·  [C_VEML]  ·   ·   ·   ·   ·   ·   ·   │
row 17 │ TP_3V3 TP_GND TP_SDA TP_SCL   ·   ·  [R_1W 4k7]   ·   ·    │
row 18 │ [C_RAD_BULK 100µ] [C_RAD 100n]  ·   ·   ·   ·   ·   ·   ·  │
row 19 │  ·   ·   ·   ·   ·   ·   ·   ·   ·   ·   ·   ·   ·   ·   │  wiring corridor
row 20 │ [J_RAD: 3V3 GND OT1 RX OT2]  · [J_1W: 3V3 · DQ · GND]  ·   │  J_1W: 3-pole terminal, cols 8/10/12
       └────────────────────────────────────────────────────────────┘     radar upright at this edge, face outward
```

Placement rules:

- **Keep-out at the module's far end.** Beyond pins `0`/`3` the module carries the `RST` and
  `BOOT` buttons and the presumed antenna, ending around row 12. Rows 11–13 across the whole
  width, plus columns 1–2 and 13–14 in rows 9–10, carry nothing: no wire on either side, no
  copper, and no conformal coating later. This is the single most important rule on this board.
- **The USB socket overhangs the row-1 edge.** The perfboard's strip of elongated edge pads at
  that edge sits under the module and stays unused.
- **Radar upright at the bottom edge**, antenna face (the side with the two large copper
  patches and the `HLK-LD2410S` print) pointing away from the board; its header is on the back,
  so the label side faces outward when it is plugged in correctly. On a windowsill unit lying
  flat that is the horizontal look into the room. The radar's 20 mm body spans about columns 1–8
  in the air above row 20; `J_1W` sits at columns 8–12 beside it, which clears it because the
  terminal is low.
- **SHT41 and VEML7700 stand upright on their headers** in row 15, in free air above the board.
  The SHT41 is on the far side from the SuperMini's LDO (the warm part) with the whole width of
  the board between them. If the light sensor must look up rather than sideways, put a
  right-angle female header at `J_VEML` and lay the module flat; nothing else changes.
- **The probe terminal at the bottom edge** so the lead leaves the board without crossing it.
- **If the screw terminal turns out to be 2.54 mm**, `J_1W` takes cols 8–10 in row 20; nothing
  else moves.
- Columns 13–14 below row 13 are free; a future spare I²C header goes there if ever wanted.

## 4. Net list by pin name

```text
+3V3 rail (from U1 3V, col 4 row 5):
  ├── C1 100n ── GND                      beside the pin
  ├── R_PU_SDA 4k7 ── SDA
  ├── R_PU_SCL 4k7 ── SCL
  ├── J_SHT  VIN ──┤C_SHT 100n── GND
  ├── J_VEML VIN ──┤C_VEML 100n── GND     (J_VEML 3VO: NOT CONNECTED)
  ├── J_RAD  3V3 ──┬┤C_RAD_BULK 100µ (+)── GND
  │                └┤C_RAD 100n── GND
  ├── J_1W   3V3 ── R_1W 4k7 ── J_1W DQ ── U1 GPIO4
  └── TP_3V3

GND rail (U1 GD, col 4 row 4):
  every GND above, TP_GND

SDA (U1 GPIO5, col 11 row 8):  J_SHT SDA, J_VEML SDA, TP_SDA
SCL (U1 GPIO6, col 11 row 7):  J_SHT SCL, J_VEML SCL, TP_SCL

U1 GPIO3 (col 11 row 10) ── J_RAD OT2      presence in, high = occupied
U1 RX = GPIO20 (col 4 row 6) ── J_RAD OT1  radar UART TX → C3 UART0 RX
U1 TX = GPIO21 (col 4 row 7) ── J_RAD RX   C3 UART0 TX → radar UART RX
U1 GPIO4 (col 11 row 9)  ── J_1W DQ        1-Wire, with R_1W to +3V3
U1 5V    ── nothing
U1 GPIO0, 1, 2, 7, 8, 9, 10 ── nothing
```

Pull-up sum per line: carrier 4.7 kΩ in parallel with the VEML7700's 10 kΩ gives about 3.2 kΩ;
with an assumed 10 kΩ on the OLED about 2.4 kΩ, 1.4 mA sink at 3.3 V. The SHT41 board adds
nothing (its host-side pads are empty). Meter check, unpowered: VEML7700 `SDA` to `VIN` about
10 kΩ, SHT41 the same pair open, SuperMini `5` to `3V` for the OLED's own pull-up.

## 5. Connection diagrams per module

### 5.1 SHT41 (`J_SHT`, 4 pins)

```text
              J_SHT
 +3V3 ──────── 1  VIN
 GND  ──────── 2  GND
 SCL  ──────── 3  SCL
 SDA  ──────── 4  SDA
```

Photo-confirmed on the spare (`SHT4X` board): `VIN GND SCL SDA`. Address `0x44`, no address pin.
The board carries a `662K` 3.3 V LDO and a level shifter, so `VIN` at 3.3 V reaches the sensor
at about 3.2 V, which is fine. Its `103` array serves the shifter's sensor side; the two empty
pads at the top edge are the host-side pull-ups, so **this board contributes no pull-up** to the
bus — the carrier's `R_PU_*` do that job.

### 5.2 VEML7700 (`J_VEML`, 5 pins)

```text
              J_VEML
 +3V3 ──────── 1  VIN
 NC   ──────── 2  3VO     regulator output — never driven, never tied to 3V3
 GND  ──────── 3  GND
 SCL  ──────── 4  SCL
 SDA  ──────── 5  SDA
```

Photo-confirmed on the spare (`HW-900` board, "Vin/logic 3-5V"): `VIN 3VO GND SCL SDA`. Address
`0x10`. Same regulator-plus-level-shifter architecture as the SHT41 board, but with all four
elements of its `103` array in use, so it presents about 10 kΩ per line to the bus. Face the
sensor away from the OLED.

### 5.3 HLK-LD2410S (`J_RAD`, 5 pins) — manual Table 3-2

```text
              J_RAD (J2 on the module, order as printed: 3V3 GND OT1 RX OT2)
 +3V3 ──────── 1  3V3     3.0–3.6 V; C_RAD_BULK 100 µF + C_RAD 100 nF right here
 GND  ──────── 2  GND
 RX (GPIO20) ── 3  OT1     the module's UART TX (0–3.3 V) → C3 UART0 RX
 TX (GPIO21) ── 4  RX      the module's UART RX (0–3.3 V) ← C3 UART0 TX
 GPIO3 ─────── 5  OT2     presence: HIGH = somebody, LOW = nobody (0–3.3 V)
```

Nothing between the module and the GPIOs: the manual gives every pin as 0–3.3 V, so there is no
level to shift and no fault current to limit beyond what a 3.3 V rail can supply. **`OT1` is not
the presence pin.** UART 115200 8N1; the default report is the 5-byte minimal frame
`6E · state · distance-cm (2, little-endian) · 62`, state 0/1 = nobody, 2/3 = somebody. The J1
pads (SWD) are not used.

Photo-confirmed: the front silkscreen reads `HLK-LD2410S` with the header labelled `3V3 GND OT1
RX OT2`, exactly the manual's order; the factory header is on the back, five pins, standard
2.54 mm by appearance against the 20 mm body. Measure it once before soldering `J_RAD`. The
antenna face (labels, two copper patches) looks away from the board.

### 5.4 DS18B20 probe (`J_1W`, 3-pole screw terminal)

```text
 +3V3 ──┬───── J_1W 1  3V3 ────── probe VDD
        R_1W 4k7
 GPIO4 ─┴───── J_1W 2  DQ  ────── probe DATA
 GND  ──────── J_1W 3  GND ────── probe GND
```

Powered mode (VDD wired), not parasite. **Ring the three wires out** against the probe's own
datasheet pin order at the sensor end with a continuity meter before trusting any colour; on the
encapsulated probes in stock the colours are a product claim. The 2.5 m lead is inside the
1-Wire limits with a 4.7 kΩ pull-up, and it is the only thing that may leave the room: held out
of a window it gives an outside temperature with no electronics outside.

### 5.5 Test points

`TP_3V3`, `TP_GND`, `TP_SDA`, `TP_SCL` in row 17. The unpowered checks use them; label them on
the board.

## 6. Build order

1. Dry-fit `U1` into the grid once more in the final orientation: two rows of eight, 7 pitches
   apart (confirmed 4 September), USB overhanging the row-1 edge, row A (the LED side) on the
   column-4 side. Mark the two rows on the copper side before the socket strips go in.
2. Solder `S1`/`S2` socket strips: push the module in as an alignment jig, tack one pin at each
   end of each strip, pull the module out, finish the joints, re-check squareness.
3. Ground and 3.3 V distribution as bare wire on the copper side, staying out of the antenna
   keep-out. Continuity check: 3V3 to every supply pad, GND to every GND pad, **no** continuity
   between 3V3 and GND.
4. `R_PU_SDA`, `R_PU_SCL`, `C1`, then `J_SHT`, `J_VEML`, `C_SHT`, `C_VEML`, `TP_*`.
5. `C_RAD_BULK` (polarity!), `C_RAD`, `J_RAD`.
6. `R_1W`, `J_1W`.
7. Unpowered: resistance SDA to 3V3 and SCL to 3V3 (≈ 4.7 kΩ with no modules plugged in, about
   3.2 kΩ with the VEML7700 plugged in, unchanged by the SHT41); every GPIO pad to 3V3 and to
   GND open circuit; `J_1W` poles to their nets.

## 7. Staged bring-up

1. **Controller alone**, nothing plugged in. USB power. `TP_3V3` ≈ 3.3 V; SDA and SCL idle-high;
   bus scan shows exactly `0x3C` (`firmware/tools/c3scan` does this). Serial hello with product
   and station id once the product firmware exists. Wi-Fi joins at the limited TX power; note
   the RSSI.
2. **SHT41**, unpowered plug-in. Scan: `0x3C 0x44`. Plausible T/RH against Room.
3. **VEML7700.** Scan adds `0x10`. Dark and bright response.
4. **Radar.** Before plugging in: with the module powered from the bench at 3.3 V on its own,
   measure `OT2` with nobody in front (low) and a hand in front (high) — the manual says so, the
   meter confirms it. Then plug in; `presence` follows `OT2`. Sit still for five minutes: stays
   on. Leave the room for five minutes: goes off. Only then connect the UART pins in firmware.
5. **Probe.** After ringing out: `temperature_probe` plausible, responds to a hand.
6. **Soak**: 24 hours, no reconnect gap over 5 minutes.

Stop conditions: any voltage above 3.3 V on any pad (there is no source for one on this board,
so it means a wrong connection to USB 5 V), a warm part other than the SuperMini's LDO, a bus
scan that shows an address not in the list, or a probe lead whose pin order is uncertain.

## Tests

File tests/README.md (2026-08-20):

# Tests

Host-side firmware tests live next to the code they protect:

```bash
pio test -e native
```

Run that from `firmware/` (or `task test` from the repo root). PlatformIO Unity covers:

- `test_native` — OLED banner clipping, D5/D4 pin constants, SSD1306 address selection
  (0x3C then 0x3D), OLED controller/geometry, SDS011 parse/listen logs, MQ135 ADC millivolt
  scale (never CO₂), PIR debounce, VEML7700 formatters.
- `test_mqtt` — MQTT topics (`atmosmesh-0001`, no room), state JSON units/validity, Home
  Assistant discovery configs (no lux), LWT/availability strings, reconnect backoff, and the
  session rule that disconnected ticks publish nothing.

These tests must fail if that behaviour is removed.

Still required later (not yet automated):

- broader sensor stale-state matrix beyond the MQTT contract;
- rendered Kubernetes manifests;
- an end-to-end synthetic measurement from device boundary to dashboard/alert;
- documented manual electrical checks and the 30-minute/48-hour run evidence;
- manual Wi-Fi/broker interrupt after flash (see RLS-05).

Hardware measurements are evidence, not a replacement for host-side automated tests.

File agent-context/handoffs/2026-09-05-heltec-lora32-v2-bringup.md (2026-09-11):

# Heltec WiFi LoRa 32 V2 bring-up handoff — 2026-09-05

- Status: Done for the listen test; TX proof open (needs a second radio or a longer capture)
- Done:
  - Board identified over USB: ESP32-D0WDQ6 rev 1.0, 8 MB flash, MAC `3c:61:05:0e:04:ec` → Heltec V2
    (classic ESP32, SX127x class radio). Facts in `docs/hardware/inventory.md`.
  - Full 8 MB stock flash backed up to
    `PlatformRelay/.tooling/firmware-backups/heltec-wifi-lora32-v2_3c61050e04ec_stock-factory_2026-09-05.bin`.
  - Host tooling repaired: shared venv `PlatformRelay/.tooling/python/atmosmesh` rebuilt with `uv`
    (Python 3.12, esptool 5.3.1, pyserial, meshtastic CLI 2.7.11).
  - Operator gave the go-ahead; Meshtastic 2.7.26 `meshtastic-diy-v1` written at 115200 baud:
    `firmware-…factory.bin` @ `0x0`, `mt-esp32-ota.bin` @ `0x260000`, `littlefs-…bin` @ `0x300000`
    (hash-verified). Region set to `EU_868`. Node id `!050e04ec`.
  - Listen result: `RF95 init success`, 869.525 MHz LongFast, 20 dBm, noise floor −107…−110 dBm;
    ~10 min across two windows: `num_packets_rx=0`, `num_packets_tx=0`, `--nodes` lists only self.
  - Plan and idea list: `docs/hardware/lora-remote-node.md` (§2 has the coverage verdict).
- Evidence: serial captures in the job's tmp dir (not kept); the key lines are quoted in the
  inventory row and plan §2.
- Gotchas learned:
  - Writing the app-only `firmware-*.bin` at `0x0` boot-loops (`flash read err, 1000`); use the
    `*.factory.bin` merged image.
  - Every serial port open resets the board (CP2102 DTR/RTS), so a CLI command and a log capture
    cannot overlap; the node's first NodeInfo broadcast is skipped as "sent <600 s ago".
  - Stay at 115200 baud; 460800/921600 fail after the esptool stub loads.
  - Run serial tools via `sudo -n -u koni -g dialout …` until the login picks up the group.
- Next:
  1. TX proof: keep one capture open for >10 min without any CLI access
     (`meshtastic --port /dev/ttyUSB0 --noproto` works as the terminal) and wait for the node's own
     NodeInfo/telemetry broadcast (`Starting low level send` … `completeSending`), or shorten
     `telemetry.device_update_interval` first. Alternative: any second LoRa radio (LORA-02).
  2. Coverage: repeat the listen for a few hours and once outdoors/at a window with the real
     antenna screwed on; any node in `--nodes` besides `!050e04ec` = RX + neighbours.
  3. Restore the stock image when done testing Meshtastic (plan §2), or keep diy-v1 as the
     home-end listener once a second radio arrives.
- Do not:
  - Power the board with the antenna disconnected.
  - Connect an 18650 before the connector polarity is verified on the board (§4 of the plan).

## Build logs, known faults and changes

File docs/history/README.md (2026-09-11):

# Historical material

These files preserve early AtmosMesh planning and design context. They are not current wiring,
firmware, or acceptance specifications.

- [AtmosMesh vault snapshot (13–14 August 2026)](atmosmesh-vault-snapshot-2026-08.md)
- [Concept wiring SVG (13 August 2026)](../assets/history/atmosmesh-concept-wiring-2026-08-13.svg)

For current information, use the repository [README](../../README.md), the
[hardware inventory](../hardware/inventory.md), [power rules](../hardware/power.md), and
[roadmap](../../agent-context/roadmap.md).

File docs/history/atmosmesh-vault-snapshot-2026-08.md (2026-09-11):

# AtmosMesh vault snapshot (13–14 August 2026)

> Indoor Air Quality Station — local sensing, connected as a mesh.

> [!IMPORTANT]
> This is a historical planning snapshot moved from the personal Obsidian vault. It contains
> superseded pins, scope, and acceptance text. Do not use it for wiring or current project status.
> The current sources of truth are the [hardware inventory](../hardware/inventory.md),
> [power rules](../hardware/power.md), and [roadmap](../../agent-context/roadmap.md).

## Outcome

- 🌬️ Eine dauerhaft laufende Raumluftstation misst Feinstaub, Temperatur, Luftfeuchtigkeit, Luftdruck und einen ausdrücklich als **Gas-/Luftqualitätstrend** bezeichneten MQ135-Wert.
- 🖥️ Ein kleines I²C-OLED zeigt die wichtigsten lokalen Werte und den Verbindungsstatus an.
- 📡 Der ESP32 überträgt Messwerte per WLAN und MQTT an die Home-Automation-Plattform im Kubernetes-Cluster.
- 📊 Home Assistant und Grafana machen aktuelle Werte, Verläufe und Warnzustände sichtbar.
- 🧩 Die Lösung bleibt so modular, dass später ein echter NDIR-CO₂-Sensor ergänzt werden kann.

## Context

- Das Projekt verwendet zunächst vorhandene Teile aus dem [Elektronik-Inventar](../elektronik-inventar.md) und soll nicht von langen Teilelieferungen abhängen.
- Für den MVP vorgesehen: ESP32-WROOM-32, SDS011, DHT22, BMP280, kleines I²C-OLED und optional MQ135.
- Der MQ135 ist **kein echter CO₂-Sensor**. Sein Messwert wird weder als CO₂ noch in ppm ausgegeben, sondern nur als relativer Gas-/Luftqualitätstrend.
- Der 3,5-Zoll-Raspberry-Pi-TFT bleibt zunächst außerhalb des MVP. Das kleine OLED ist sparsamer, einfacher anzusteuern und lässt dem ESP32 genügend Ressourcen für WLAN, MQTT und Sensorik.
- Home Assistant, Mosquitto, Prometheus und Grafana sollen auf dem parallel entstehenden Kubernetes-Cluster laufen.

## Links

- 🧰 Inventar: [Elektronik-Inventar](../elektronik-inventar.md)
- 🖼️ Historische Konzeptverdrahtung: [SVG vom 13. August 2026](../assets/history/atmosmesh-concept-wiring-2026-08-13.svg) — nicht als Bauanleitung verwenden
- 💻 Implementierungs-Repository: dieses Repository
- 🌐 GitHub: [konih/atmosmesh](https://github.com/konih/atmosmesh) — private
- ⚠️ Die zuvor im Projektgespräch erzeugte KI-Grafik ist wegen fehlerhafter Leitungsführung verworfen und darf nicht zum Aufbau verwendet werden.

## Historische Roadmap

| Phase | Stories | Ergebnis | Abschlusskriterium |
|---|---|---|---|
| 1. 🔎 Hardware klären | RLS-01 | Konkrete Module, Pins und Versorgung sind bestätigt | Verdrahtung kann ohne Annahmen aufgebaut werden |
| 2. 🧪 Tischprototyp | RLS-02, RLS-03 | Alle Sensoren und das OLED funktionieren einzeln und gemeinsam | Plausible Livewerte laufen mindestens 30 Minuten fehlerfrei |
| 3. 🖥️ Stations-Firmware | RLS-04 | Lokale Anzeige und robuste Messzyklen funktionieren | Display, Fehlerzustände und Neustartverhalten sind demonstriert |
| 4. 📡 Vernetzung | RLS-05 | Messwerte erreichen MQTT in einem stabilen Schema | Daten laufen nach WLAN- oder Broker-Ausfall selbstständig weiter |
| 5. ☸️ Plattform | RLS-06, RLS-07 | Kubernetes-Dienste, Dashboard und Warnungen sind nutzbar | Ende-zu-Ende-Demo vom Sensor bis zum Dashboard ist bestanden |
| 6. 🏠 Dauerbetrieb | RLS-08 | Station ist sicher aufgestellt und langfristig beobachtbar | 48-Stunden-Test ohne manuellen Eingriff ist bestanden |

### Nicht Bestandteil des MVP

- echter CO₂-Wert, solange kein bestätigter NDIR-Sensor vorhanden ist
- automatische Lüftungs- oder Netzspannungssteuerung
- Betrieb des 480×320-Raspberry-Pi-TFT am ESP32
- Akku- oder Batteriebetrieb
- kalibrierte oder zertifizierte Messungen für Gesundheits- oder Sicherheitszwecke
- eigenes PCB und endgültiges Produktgehäuse

## Historische Stories

### RLS-01 — Hardware identifizieren und Verdrahtung freigeben

**Als Bastler möchte ich** die konkreten Modulvarianten und Pinbeschriftungen bestätigen, **damit** wir keine Bauteile durch falsche Spannung oder Pinbelegung beschädigen.

**Umfang**

- ESP32, beide Mini-OLEDs, BMP280, DHT22, SDS011 samt Adapter, MQ135 und verfügbare 5-V-Versorgung fotografieren.
- OLED-Controller beziehungsweise I²C-Adresse soweit möglich bestimmen.
- BMP280-Modulspannung und I²C-Adresse prüfen.
- MQ135-Ausgangsspannung und geplanten Spannungsteiler bestätigen.
- Gemeinsame Pinbelegung als verbindliche Verdrahtungstabelle festhalten.

**Akzeptanzkriterien**

- [ ] 🔍 Jedes verwendete Modul ist auf Vorder- und Rückseite eindeutig dokumentiert.
- [ ] ⚡ Für jedes Modul sind Versorgungsspannung und Logikpegel bekannt.
- [ ] 🧷 Jeder Anschluss ist genau einem ESP32-Pin oder einer Versorgungsschiene zugeordnet.
- [ ] 🛡️ Kein ESP32-GPIO kann direkt mit 5 V beaufschlagt werden.
- [ ] ✅ Die Verdrahtung wurde vor dem Einschalten gemeinsam anhand der Fotos geprüft.

**Unsere Zusammenarbeit**

- Konrad stellt gut lesbare Fotos und gegebenenfalls Multimeter-Messwerte bereit.
- Der Agent identifiziert die Module, erstellt die endgültige Pin-Tabelle und prüft die Verdrahtung auf Risiken.

---

### RLS-02 — I²C-Basis und Mini-OLED in Betrieb nehmen

**Als Betreiber möchte ich** OLED und BMP280 am gemeinsamen I²C-Bus erkennen, **damit** Anzeige und Luftdruckmessung eine verlässliche technische Basis haben.

**Vorgesehene Verdrahtung**

- SDA → GPIO 21
- SCL → GPIO 22
- OLED und BMP280 → 3,3 V und gemeinsame Masse

**Akzeptanzkriterien**

- [ ] 🔎 Ein I²C-Scan erkennt OLED und BMP280 mit stabilen Adressen.
- [ ] 🖥️ Das OLED zeigt einen Testtext ohne Flackern oder Artefakte.
- [ ] 🌡️ Der BMP280 liefert plausible Temperatur- und Luftdruckwerte.
- [ ] 🔁 Nach einem Neustart initialisieren sich beide Module ohne manuellen Eingriff.
- [ ] 📝 Erkannte Adressen und Modulvarianten sind in dieser Notiz dokumentiert.

**Gemeinsamer Checkpoint:** Foto des Displays plus serielle Ausgabe des I²C-Scans prüfen.

---

### RLS-03 — Alle Messsensoren als Tischprototyp integrieren

**Als Betreiber möchte ich** alle vorgesehenen Sensoren gleichzeitig auslesen, **damit** wir elektrische und softwareseitige Konflikte vor der Vernetzung erkennen.

**Vorgesehene Anschlüsse**

- DHT22 DATA → GPIO 27 mit 10-kΩ-Pull-up nach 3,3 V
- SDS011 TX → ESP32 GPIO 16 / RX2
- SDS011 RX → ESP32 GPIO 17 / TX2
- MQ135 AO → Spannungsteiler → ADC GPIO 34
- SDS011 und MQ135 → stabile 5-V-Versorgung
- alle Komponenten → gemeinsame Masse

**Akzeptanzkriterien**

- [ ] 🌡️ Temperatur und Luftfeuchtigkeit werden vom DHT22 gelesen.
- [ ] 🌬️ PM2.5 und PM10 werden über UART vom SDS011 gelesen.
- [ ] 🎈 Luftdruck und BMP280-Temperatur werden über I²C gelesen.
- [ ] 🧪 Der MQ135 liefert nur einen Rohwert und einen relativen Trend; UI und Code nennen ihn nicht CO₂.
- [ ] ⚡ Die Spannung am ESP32-ADC bleibt auch beim höchsten beobachteten MQ135-Ausgang unter 3,3 V.
- [ ] ⏱️ Alle Sensoren laufen gemeinsam mindestens 30 Minuten ohne Absturz oder Busfehler.

**Gemeinsamer Checkpoint:** serielles Messprotokoll auf Plausibilität, Ausreißer und fehlende Werte untersuchen.

---

### RLS-04 — Lokale Anzeige und Stationszustände bauen

**Als Person im Raum möchte ich** die wichtigsten Werte und den Systemzustand ohne Smartphone sehen, **damit** die Station unmittelbar nützlich ist.

**Anzeigekonzept**

- Seite 1: PM2.5, PM10 und grober Luftqualitätsstatus
- Seite 2: Temperatur, Luftfeuchtigkeit und Luftdruck
- Seite 3: WLAN-, MQTT- und Sensorstatus
- automatischer Seitenwechsel; bei Bedarf später Bedienung per Taster oder Encoder

**Akzeptanzkriterien**

- [ ] 👀 Die Hauptwerte sind aus normaler Nähe lesbar.
- [ ] 🚦 Verbindungs- und Sensorfehler sind klar erkennbar und werden nicht als Messwert `0` dargestellt.
- [ ] 🕒 Das Display zeigt das Alter beziehungsweise die Aktualität der Daten nachvollziehbar an.
- [ ] 🔄 Ein Sensorfehler blockiert weder Anzeige noch die übrigen Sensoren dauerhaft.

**Gemeinsamer Checkpoint:** Layout anhand eines Fotos bewerten und einmal gezielt einen Sensor abziehen.

---

### RLS-05 — Messwerte zuverlässig per MQTT veröffentlichen

**Als Home-Automation-Betreiber möchte ich** strukturierte Messwerte empfangen, **damit** Home Assistant, Prometheus und weitere Verbraucher dieselben Daten nutzen können.

**Vorgeschlagenes Topic-Schema**

```text
home/air/wohnzimmer/state
home/air/wohnzimmer/status
home/air/wohnzimmer/availability
```

**Akzeptanzkriterien**

- [ ] 📦 Nachrichten enthalten Geräte-ID, Zeitstempel, Messwerte, Einheiten und Sensorstatus.
- [ ] 🏷️ Messgrößen haben stabile Namen; Gastrend und echtes CO₂ sind semantisch getrennt.
- [ ] 💓 Ein Availability-Topic zeigt online/offline per MQTT Last Will an.
- [ ] 🔁 Nach WLAN- oder Broker-Ausfall verbindet sich die Station mit begrenztem Backoff selbstständig neu.
- [ ] 🧯 Ein Netzwerkausfall blockiert Sensoren und lokale Anzeige nicht.
- [ ] 🔐 WLAN- und MQTT-Zugangsdaten liegen nicht fest im veröffentlichten Quellcode.

**Gemeinsamer Checkpoint:** MQTT-Nachrichten gemeinsam lesen und das Schema vor der Dashboard-Arbeit einfrieren.

---

### RLS-06 — Home-Automation-Dienste im Kubernetes-Cluster bereitstellen

**Als Plattformbetreiber möchte ich** die benötigten Dienste reproduzierbar im Cluster betreiben, **damit** die Station nicht von einem manuell eingerichteten Einzelserver abhängt.

**MVP-Dienste**

- Mosquitto als MQTT-Broker
- Home Assistant für Geräteansicht und Automationen
- Prometheus-kompatibler Pfad für Zeitreihen
- Grafana für langfristige Visualisierung
- persistente Speicherung und gesicherte Konfiguration

**Akzeptanzkriterien**

- [ ] ☸️ Alle benötigten Workloads werden deklarativ aus dem Repository installiert.
- [ ] 💾 Ein Pod-Neustart verliert weder Konfiguration noch relevante Historie.
- [ ] 🔐 Secrets stehen nicht im Klartext in versionierten Manifesten.
- [ ] 🩺 Für die Dienste existieren sinnvolle Readiness- und Liveness-Prüfungen.
- [ ] 📡 Der ESP32 erreicht den Broker über eine stabile Adresse im Heimnetz.
- [ ] ♻️ Eine dokumentierte Neuinstallation reproduziert den Dienstzustand.

**Gemeinsamer Checkpoint:** Deployments, Services, Persistenz und Zugriffspfad anhand der tatsächlichen Clusterumgebung entwerfen.

---

### RLS-07 — Dashboard, Historie und erste Warnung erstellen

**Als Bewohner möchte ich** aktuelle Werte und zeitliche Entwicklungen erkennen, **damit** ich Lüften, Reinigen oder technische Probleme sinnvoll beurteilen kann.

**Akzeptanzkriterien**

- [ ] 🏠 Home Assistant zeigt alle verfügbaren Messwerte und die Geräteverfügbarkeit.
- [ ] 📊 Grafana zeigt mindestens PM2.5, PM10, Temperatur, Feuchtigkeit und Luftdruck über 24 Stunden.
- [ ] 🚨 Eine erste Warnregel für einen anhaltend auffälligen Feinstaubwert ist vorhanden.
- [ ] ⏳ Die Warnung verwendet eine Dauer beziehungsweise Hysterese und reagiert nicht auf einen einzelnen Ausreißer.
- [ ] 📴 Ein offline gegangenes Gerät ist von einem echten Messwert `0` unterscheidbar.
- [ ] 🧪 Ein künstlich ausgelöster Testwert ist Ende zu Ende in MQTT, Historie, Dashboard und Warnzustand sichtbar.

**Gemeinsamer Checkpoint:** Dashboard gemeinsam auf Informationswert reduzieren und Warnschwellen zunächst als experimentell kennzeichnen.

---

### RLS-08 — Station für sicheren Dauerbetrieb härten

**Als Betreiber möchte ich** die Station 48 Stunden unbeaufsichtigt betreiben können, **damit** aus dem Tischaufbau ein verlässliches Home-Automation-Gerät wird.

**Akzeptanzkriterien**

- [ ] 🏠 Leitungen, Platinen und Stromversorgung sind mechanisch gesichert und berührungsgeschützt aufgestellt.
- [ ] 🌬️ SDS011, DHT22 und BMP280 erhalten ausreichenden Luftaustausch und werden nicht durch ESP32- oder Netzteilwärme verfälscht.
- [ ] 🔥 Kabel, Spannungsregler und Module zeigen keine auffällige Erwärmung.
- [ ] 🐕 Ein Watchdog beziehungsweise kontrollierter Neustart fängt festgefahrene Zustände ab.
- [ ] 📈 Neustarts, Verbindungsstatus und Alter des letzten Messwerts sind beobachtbar.
- [ ] ⏱️ Ein 48-Stunden-Test läuft ohne manuellen Eingriff und ohne unerklärte Datenlücken.
- [ ] 📖 Verdrahtung, Firmwarestand, Wiederherstellung und bekannte Einschränkungen sind dokumentiert.

**Gemeinsamer Checkpoint:** Nach dem Dauertest Logs und Messkurven prüfen und erst danach über ein endgültiges Gehäuse entscheiden.

## Optionale Folgestories

### RLS-09 — Echten CO₂-Sensor ergänzen

- Erst starten, wenn ein vorhandenes Modul eindeutig als NDIR-Sensor identifiziert oder ein passendes Modul beschafft wurde.
- Kandidaten: SCD40/SCD41, SCD30, MH-Z19B oder Senseair.
- CO₂ wird erst nach Plausibilitäts- und Frischlufttest in ppm angezeigt.
- Der MQ135-Trend bleibt eine getrennte Messgröße oder wird entfernt.

### RLS-10 — Großes lokales Display evaluieren

- Controller, Pinout und Touch-Controller des 3,5-Zoll-480×320-TFT identifizieren.
- ESP32-Prototyp nur als technische Machbarkeitsprüfung betrachten.
- Bevorzugte Alternative: Raspberry Pi mit Home-Assistant- oder Grafana-Dashboard im Kioskmodus.

## Definition of Done für den MVP

- [ ] ✅ RLS-01 bis RLS-08 sind erfüllt.
- [ ] 📡 Ein realer Messwert ist vom Sensor bis Home Assistant und Grafana nachvollziehbar.
- [ ] 🔄 Strom-, WLAN-, Broker- und Sensorunterbrechungen wurden kontrolliert getestet.
- [ ] 🧪 MQ135-Daten werden nirgends als CO₂-Messung ausgegeben.
- [ ] 📝 Aufbau, Pinbelegung, Konfiguration und Wiederanlauf sind so dokumentiert, dass wir die Station erneut aufbauen können.
- [ ] 🏠 Die Station hat den 48-Stunden-Dauertest bestanden.

## Historischer Plan

1. RLS-01 gemeinsam durchführen und die tatsächliche Hardware bestätigen.
2. RLS-02 und RLS-03 auf dem Tisch aufbauen; jeden Sensor zunächst einzeln testen.
3. RLS-04 und RLS-05 als erste vollständige ESP32-Firmware liefern.
4. RLS-06 an den tatsächlichen Kubernetes-Cluster und dessen Storage-/Ingress-Konzept anpassen.
5. RLS-07 Ende zu Ende demonstrieren.
6. RLS-08 mit provisorischem, aber sicherem Aufbau und 48-Stunden-Beobachtung abschließen.

## Historische Tasks

- [ ] 📸 Für RLS-01 Fotos der konkreten Module und ihrer Rückseiten aufnehmen
- [ ] 🔌 Verfügbare stabile 5-V-Versorgung auswählen und Typenschild dokumentieren
- [ ] 🧷 Endgültige Pin-Tabelle freigeben
- [ ] 🧪 I²C-Testfirmware erstellen und ausführen
- [ ] 🌬️ Sensor-Testfirmware erstellen und ausführen
- [ ] 🖥️ OLED-Layout abstimmen
- [ ] 📡 MQTT-Schema abstimmen
- [ ] ☸️ Cluster-Randbedingungen für Storage, Secrets und Heimnetz-Zugriff erfassen
- [ ] 📊 Dashboard und Warnregel erstellen
- [ ] ⏱️ 48-Stunden-Dauertest durchführen und auswerten

## Notes / Log

- 2026-08-13: Projekt aus dem vorhandenen Elektronik-Inventar geplant; Mini-OLED für den MVP gewählt. MQ135 ausdrücklich nur als Gas-/Luftqualitätstrend eingeordnet. Großer Raspberry-Pi-TFT und echter NDIR-CO₂-Sensor als optionale Folgestories aufgenommen.
- 2026-08-13: Fehler in der ersten KI-generierten Konzeptgrafik erkannt: 5-V- und 3,3-V-Leitungen waren visuell falsch geführt. Grafik verworfen und durch einen deterministischen SVG-Plan ersetzt. ESP32 wird darin separat über USB versorgt; SDS011 und MQ135 erhalten externe 5 V, alle Komponenten teilen nur GND. MQ135-ADC-Teiler auf 15 kΩ/10 kΩ geändert (maximal 2,0 V am ADC bei 5,0 V am AO).
- 2026-08-14: Eigenständiges Git-Repository angelegt. Das Repository ist ab jetzt die Implementierungsquelle mit `AGENTS.md`, Live-Kontext, Architektur, Hardwaregrenzen und einzeln claimbaren Stories RLS-01 bis RLS-10; diese Vault-Notiz bleibt die persönliche Übersicht.
- 2026-08-14: Projekt von „Raumluft-Netzstation“ in **AtmosMesh** umbenannt; alter Name bleibt als Alias erhalten.

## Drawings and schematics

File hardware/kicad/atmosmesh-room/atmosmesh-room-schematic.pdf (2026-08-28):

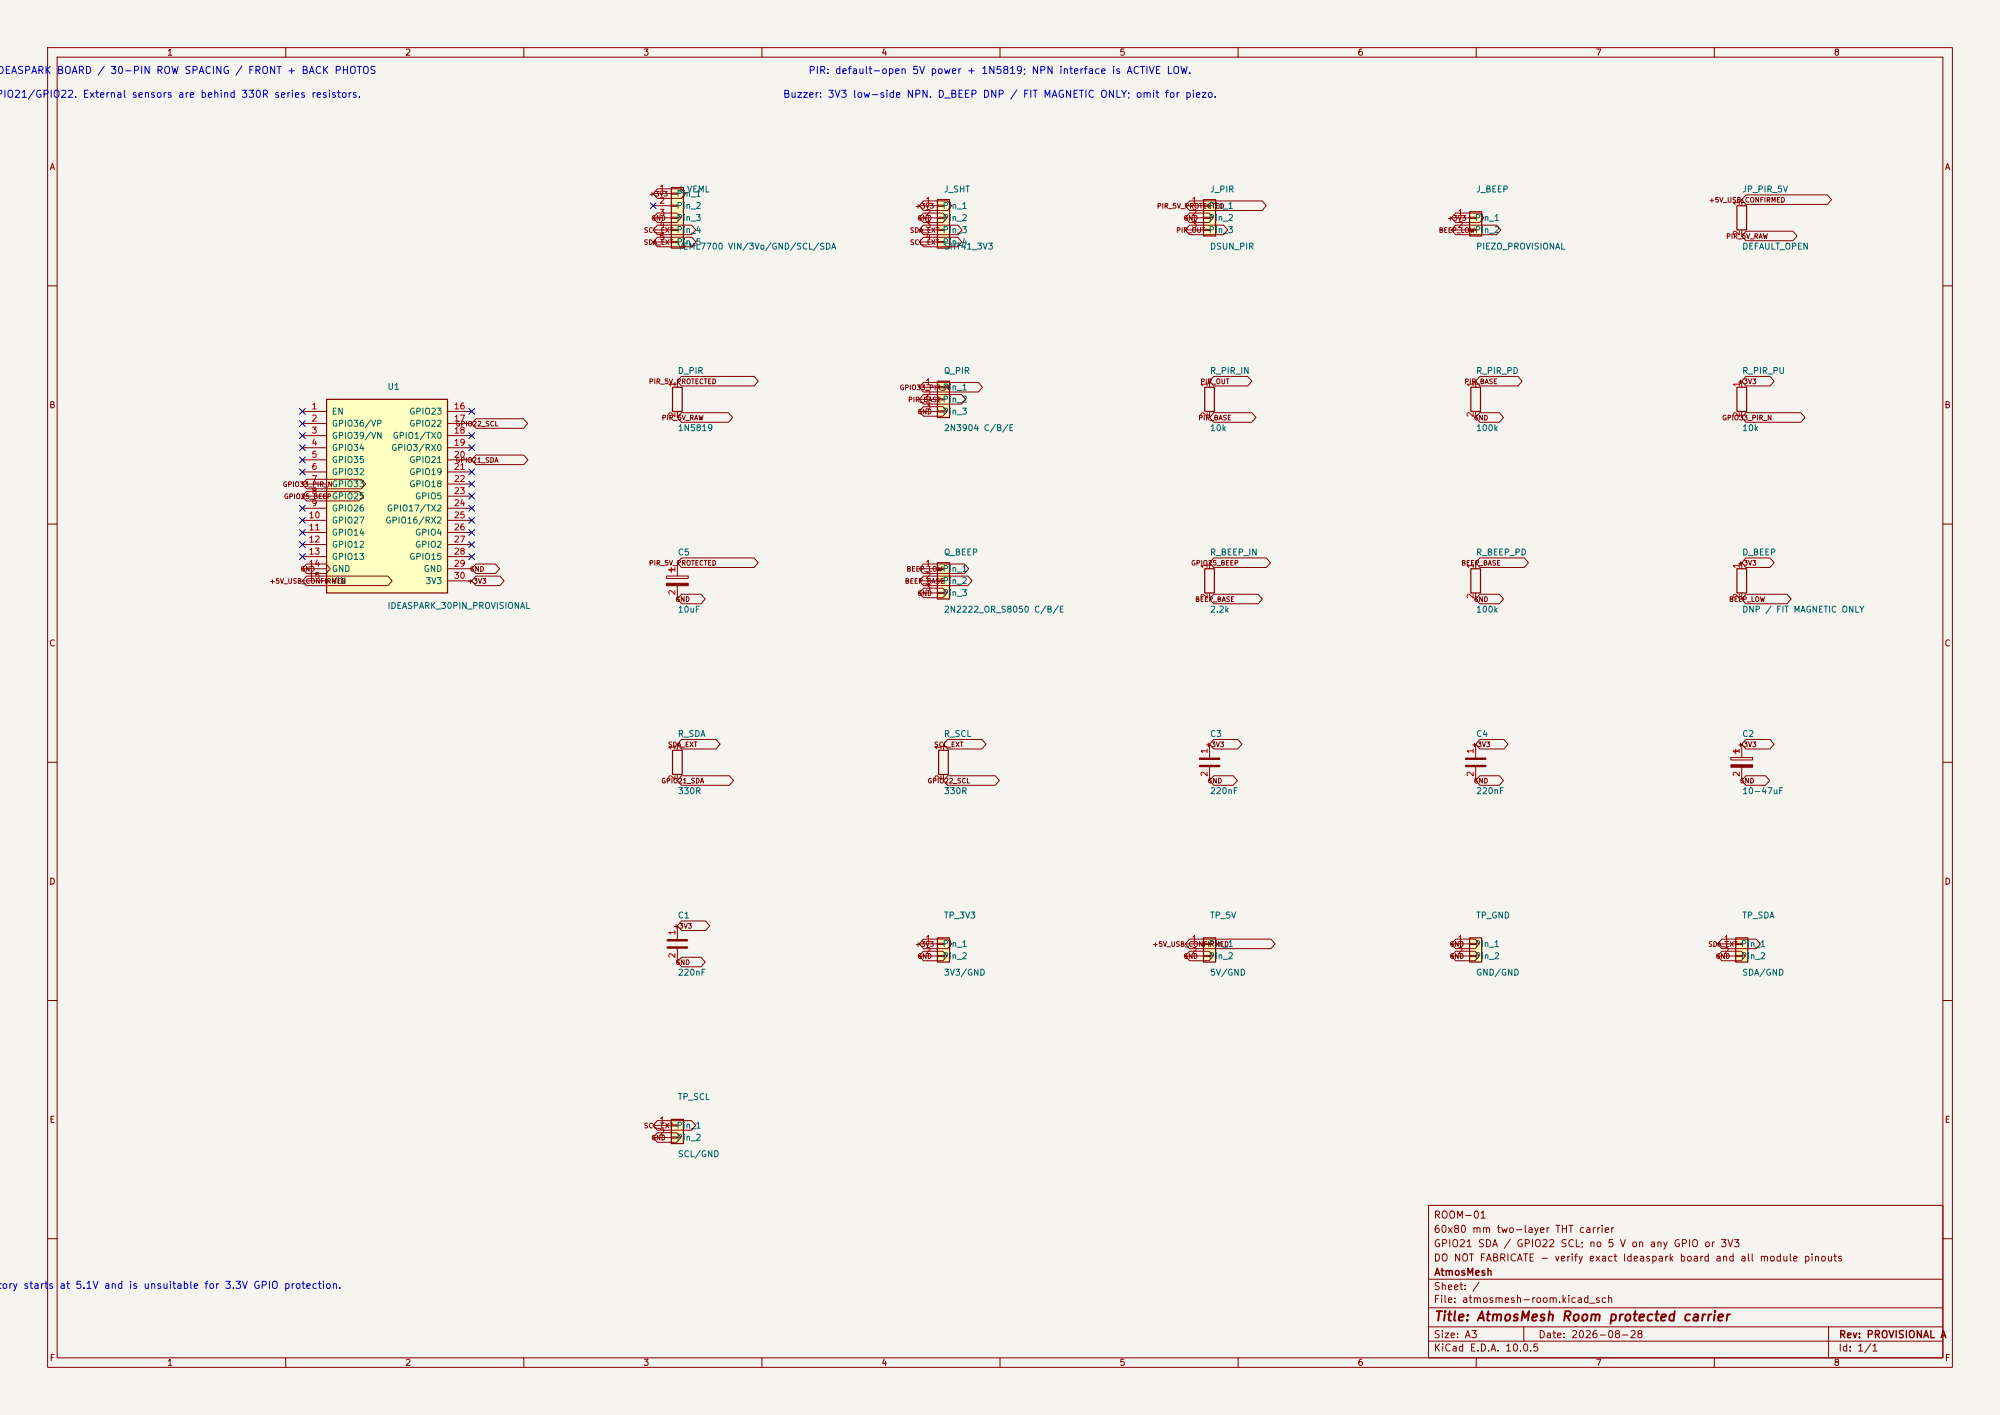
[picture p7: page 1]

DO NOT FABRICATE - VERIFY EXACT IDEASPARK BOARD / 30-PIN ROW SPACING / FRONT + BACK PHOTOS

PIR: default-open 5V power + 1N5819; NPN interface is ACTIVE LOW.

J_VEML VEML7700 VIN/3Vo/GND/SCL/SDA

DNP / FIT MAGNETIC ONLY 1 2 R_PIR_PU

ROOM-01
60x80 mm two-layer THT carrier
GPIO21 SDA / GPIO22 SCL; no 5 V on any GPIO or 3V3
DO NOT FABRICATE - verify exact Ideaspark board and all module pinouts
AtmosMesh
Sheet: /
File: atmosmesh-room.kicad_sch
Title: AtmosMesh Room protected carrier

No Zener clamps: known inventory starts at 5.1V and is unsuitable for 3.3V GPIO protection.

F Date: 2026-08-28

KiCad E.D.A. 10.0.5 | Id: 1/1

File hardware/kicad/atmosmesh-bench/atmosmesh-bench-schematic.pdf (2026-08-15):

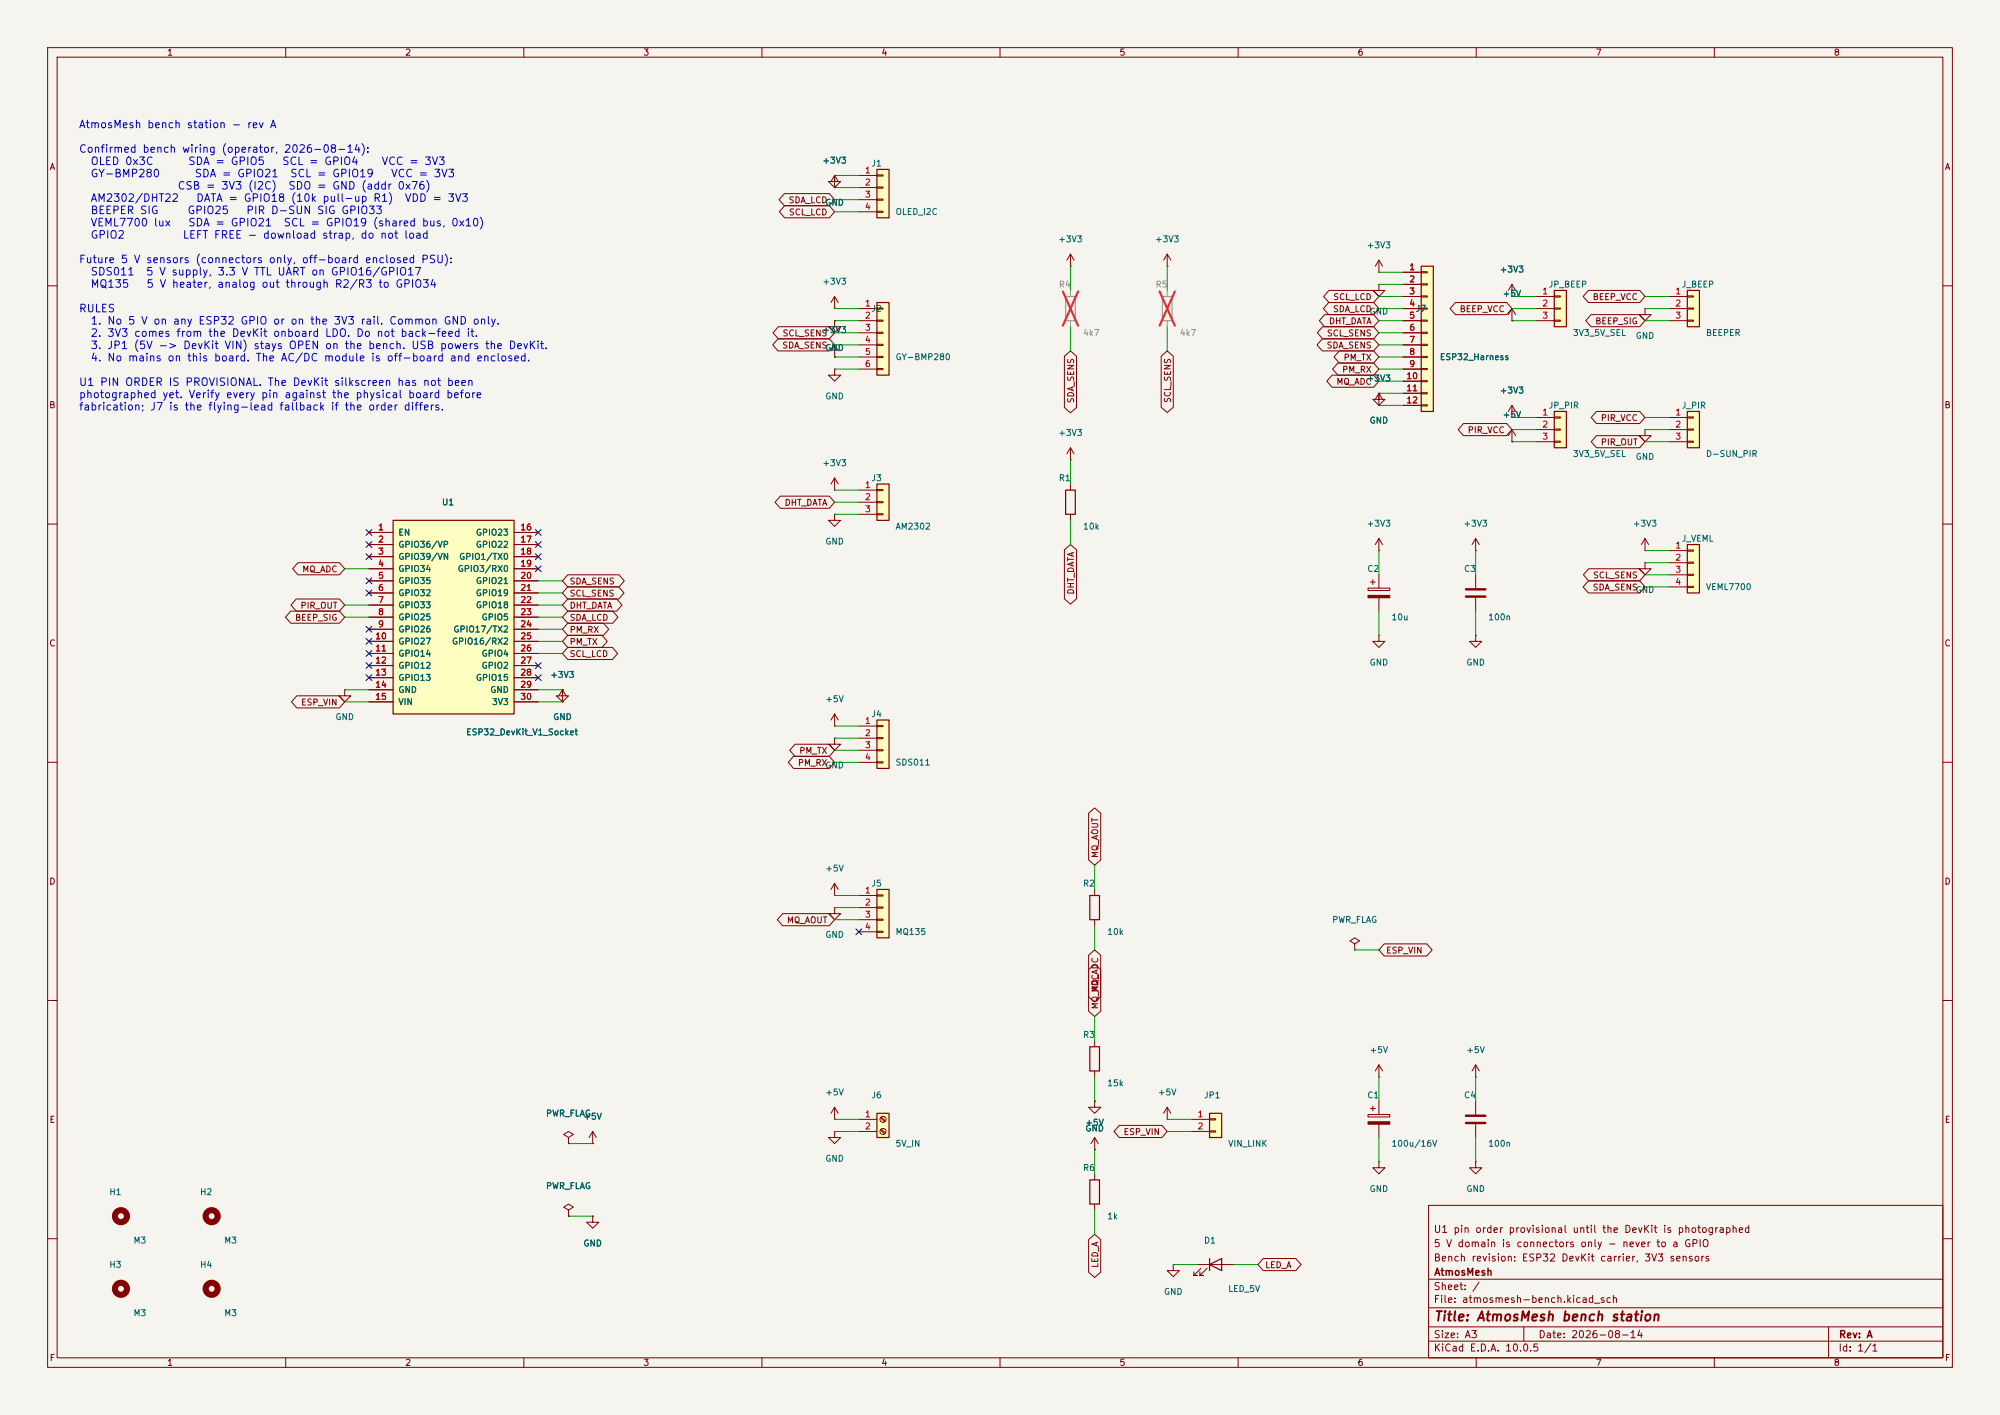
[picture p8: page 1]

BEEP_VCC AtmosMesh bench station - rev A

Confirmed bench wiring (operator, 2026-08-14):

CSB = 3V3 (I2C) SDO = GND (addr 0x76)

Future 5 V sensors (connectors only, off-board enclosed PSU):
SDS011 5 V supply, 3.3 V TTL UART on GPIO16/GPIO17

RULES
1. No 5 V on any ESP32 GPIO or on the 3V3 rail. Common GND only.
2. 3V3 comes from the DevKit onboard LDO. Do not back-feed it.
3. JP1 (5V -> DevKit VIN) stays OPEN on the bench. USB powers the DevKit.
4. No mains on this board. The AC/DC module is off-board and enclosed.

U1 PIN ORDER IS PROVISIONAL. The DevKit silkscreen has not been
photographed yet. Verify every pin against the physical board before

U1 pin order provisional until the DevKit is photographed +5V

Bench revision: ESP32 DevKit carrier, 3V3 sensors 5 V domain is connectors only - never to a GPIO

AtmosMesh
Sheet: /
File: atmosmesh-bench.kicad_sch
Title: AtmosMesh bench station

Size: A3 | Rev: A | F Date: 2026-08-14
KiCad E.D.A. 10.0.5 | Id: 1/1

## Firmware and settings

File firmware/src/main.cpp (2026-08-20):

#include <Arduino.h>
#include <Adafruit_BMP280.h>
#include <Adafruit_VEML7700.h>
#include <DHT.h>
#include <U8g2lib.h>
#include <Wire.h>

#include "atmosmesh/am2302_frame.hpp"
#include "atmosmesh/bmp_address.hpp"
#include "atmosmesh/digital_edge.hpp"
#include "atmosmesh/display_text.hpp"
#include "atmosmesh/i2c_bus.hpp"
#include "atmosmesh/mq135_scale.hpp"
#include "atmosmesh/mqtt_runtime.hpp"
#include "atmosmesh/oled_address.hpp"
#include "atmosmesh/oled_profile.hpp"
#include "atmosmesh/pins.hpp"
#include "atmosmesh/sds011_frame.hpp"
#include "atmosmesh/veml7700_text.hpp"

namespace {

DHT am2302(atmosmesh::kAm2302DataGpio, DHT22);
Adafruit_BMP280 bmp280(&Wire1);
Adafruit_VEML7700 veml7700;
U8G2* oled = nullptr;
atmosmesh::OledProfile oled_profile{};
bool oled_ready = false;
int bmp_address = -1;
bool bmp_ok = false;
atmosmesh::Sds011Stream sds011{};
bool pm_ok = false;
float pm25_ug_m3 = 0.0F;
float pm10_ug_m3 = 0.0F;
unsigned long last_pm_ms = 0;
constexpr unsigned long kPmStaleMs = 5000;
constexpr unsigned long kLoopSliceMs = 10;
atmosmesh::DebouncedLevel pir_edge{};
bool pir_motion = false;
bool veml_ok = false;
float veml_lux = 0.0F;
bool am_ok = false;
float humidity = 0.0F;
float temperature = 0.0F;
atmosmesh::Am2302Hold am_hold{};
float bmp_t_c = 0.0F;
float bmp_p_hpa = 0.0F;
bool bmp_read_ok = false;
int mq_raw = 0;
unsigned long last_env_ms = 0;
unsigned long last_am_ms = 0;
unsigned long last_bmp_ms = 0;
unsigned long last_mq_ms = 0;
unsigned long last_pir_ms = 0;

atmosmesh::MqttStationState build_mqtt_state(unsigned long now) {
    atmosmesh::MqttStationState state{};
    state.temperature.valid = am_hold.show;
    state.temperature.value = am_hold.temperature_c;
    state.temperature.age_ms = am_hold.show && last_am_ms != 0 ? (now - last_am_ms) : 0;
    state.humidity.valid = am_hold.show;
    state.humidity.value = am_hold.humidity_rh;
    state.humidity.age_ms = state.temperature.age_ms;

    state.pressure.valid = bmp_read_ok;
    state.pressure.value = bmp_p_hpa;
    state.pressure.age_ms = bmp_read_ok && last_bmp_ms != 0 ? (now - last_bmp_ms) : 0;
    state.bmp_temperature.valid = bmp_read_ok;
    state.bmp_temperature.value = bmp_t_c;
    state.bmp_temperature.age_ms = state.pressure.age_ms;

    state.pm25.valid = pm_ok;
    state.pm25.value = pm25_ug_m3;
    state.pm25.age_ms = pm_ok && last_pm_ms != 0 ? (now - last_pm_ms) : 0;
    state.pm10.valid = pm_ok;
    state.pm10.value = pm10_ug_m3;
    state.pm10.age_ms = state.pm25.age_ms;

    state.gas_index.valid = true;
    state.gas_index.value = static_cast<float>(atmosmesh::mq135_gas_index(mq_raw));
    state.gas_index.age_ms = last_mq_ms != 0 ? (now - last_mq_ms) : 0;
    state.mq135_raw = mq_raw;
    state.mq135_raw_valid = true;

    state.motion.valid = true;
    state.motion.value = pir_motion;
    state.motion.age_ms = last_pir_ms != 0 ? (now - last_pir_ms) : 0;
    return state;
}

void publish_mqtt_state(unsigned long now) {
    atmosmesh::mqtt_runtime_publish_state(build_mqtt_state(now));
}

void log_scan(const char* label, const atmosmesh::I2cBusMap& pins, const std::uint8_t* found,
              std::size_t count) {
    Serial.printf("i2c scan %s sda=%d scl=%d devices=%u\n", label, pins.sda_gpio, pins.scl_gpio,
                  static_cast<unsigned>(count));
    for (std::size_t i = 0; i < count; ++i) {
        Serial.printf("  addr=0x%02X\n", found[i]);
    }
}

void release_oled() {
    delete oled;
    oled = nullptr;
}

U8G2* make_u8g2(const atmosmesh::OledProfile& profile) {
    const int scl = atmosmesh::kOledSclGpio;
    const int sda = atmosmesh::kOledSdaGpio;
    if (profile.controller == atmosmesh::OledController::Sh1106) {
        return new U8G2_SH1106_128X64_NONAME_F_HW_I2C(U8G2_R0, U8X8_PIN_NONE, scl, sda);
    }
    if (profile.height_px == atmosmesh::kOledHeightPxAlt) {
        return new U8G2_SSD1306_128X32_UNIVISION_F_HW_I2C(U8G2_R0, U8X8_PIN_NONE, scl, sda);
    }
    // 128×48 uses 64-row full buffer then SET MUX 0x2F (U8g2 has no 128×48 ctor).
    return new U8G2_SSD1306_128X64_ALT0_F_HW_I2C(U8G2_R0, U8X8_PIN_NONE, scl, sda);
}

void show_lines(const std::string* lines, std::size_t count) {
    if (!oled_ready || oled == nullptr) {
        return;
    }
    oled->clearBuffer();
    oled->setDrawColor(1);
    oled->setFont(u8g2_font_6x10_tf);
    const int baseline_adjust = oled->getAscent();
    for (std::size_t i = 0; i < count; ++i) {
        int y = atmosmesh::oled_live_row_y_px(static_cast<int>(i)) + baseline_adjust;
        if (y > oled_profile.clip_max_y) {
            y = oled_profile.clip_max_y;
        }
        oled->drawStr(oled_profile.column_offset_px, y, lines[i].c_str());
    }
    oled->sendBuffer();
}

void pulse_beeper() {
    digitalWrite(atmosmesh::kBeeperGpio, HIGH);
    delay(atmosmesh::kBeeperPulseMs);
    digitalWrite(atmosmesh::kBeeperGpio, LOW);
}

void refresh_oled() {
    const auto lines = atmosmesh::live_sensor_lines(
        am_hold.show, am_hold.temperature_c, am_hold.humidity_rh, bmp_read_ok, bmp_p_hpa, pm_ok,
        pm25_ug_m3, pm10_ug_m3, mq_raw, pir_motion, veml_ok, veml_lux, bmp_t_c,
        atmosmesh::oled_right_cell_for_ms(millis()));
    show_lines(lines.data(), lines.size());
}

void setup_extras() {
    pinMode(atmosmesh::kBeeperGpio, OUTPUT);
    digitalWrite(atmosmesh::kBeeperGpio, LOW);
    pinMode(atmosmesh::kPirGpio, INPUT_PULLDOWN);
    Serial.printf("beeper: GPIO%d output, %d ms boot pulse\n", atmosmesh::kBeeperGpio,
                  atmosmesh::kBeeperPulseMs);
    Serial.printf("pir: GPIO%d digital INPUT_PULLDOWN\n", atmosmesh::kPirGpio);
    pulse_beeper();
    Serial.println(atmosmesh::format_beep_boot_log().c_str());
}

void poll_extras() {
    const unsigned long now = millis();
    const bool pir_sample = digitalRead(atmosmesh::kPirGpio) == HIGH;
    if (atmosmesh::update_debounced_level(pir_edge, pir_sample, now, atmosmesh::kDigitalDebounceMs)) {
        const bool rose = pir_edge.stable && !pir_motion;
        pir_motion = pir_edge.stable;
        last_pir_ms = now;
        Serial.println(atmosmesh::format_pir_log(pir_motion).c_str());
        if (rose) {
            pulse_beeper();
        }
        refresh_oled();
        publish_mqtt_state(now);
    }
}

bool try_oled_bus(const char* label, const atmosmesh::I2cBusMap& pins, atmosmesh::I2cDevice* out) {
    std::uint8_t found[16];
    const std::size_t count = atmosmesh::scan_i2c_bus(Wire, pins, found, sizeof(found));
    log_scan(label, pins, found, count > sizeof(found) ? sizeof(found) : count);
    const int address = atmosmesh::pick_oled_address(found, count);
    if (address < 0) {
        return false;
    }
    out->address = static_cast<std::uint8_t>(address);
    out->pins = pins;
    return true;
}

bool begin_oled(std::uint8_t address, const atmosmesh::OledProfile& profile) {
    release_oled();
    Wire.setClock(atmosmesh::kOledI2cHz);
    oled = make_u8g2(profile);
    oled->setI2CAddress(static_cast<uint8_t>(address << 1));
    oled->setBusClock(atmosmesh::kOledI2cHz);
    Serial.printf("oled: begin renderer=u8g2 constructor=%s addr=0x%02X\n",
                  atmosmesh::u8g2_hw_i2c_constructor_name(profile), address);
    if (!oled->begin()) {
        Serial.printf("oled: init error controller=%s addr=0x%02X height=%d\n",
                      atmosmesh::oled_controller_name(profile.controller), address,
                      profile.height_px);
        release_oled();
        return false;
    }
    oled_profile = profile;
    oled->setFlipMode(static_cast<uint8_t>(atmosmesh::compiled_oled_flip_mode()));
    Serial.println(atmosmesh::format_oled_flip_log().c_str());
    if (atmosmesh::oled_should_set_mux(profile)) {
        oled->sendF("ca", atmosmesh::kSsd1306SetMultiplex, atmosmesh::kSsd1306MuxRatio48);
        oled->sendF("ca", atmosmesh::kSsd1306SetDisplayOffset, atmosmesh::kSsd1306DisplayOffset0);
        oled->setClipWindow(0, 0, profile.width_px - 1, profile.clip_max_y);
        Serial.println(atmosmesh::format_oled_mux48_log().c_str());
    }
    Serial.println(atmosmesh::format_oled_init_log(profile, address).c_str());
    Serial.printf("oled: sda=%d scl=%d column_offset=%d vcc=3V3 (never 5V if pull-ups are on VCC)\n",
                  atmosmesh::kOledSdaGpio, atmosmesh::kOledSclGpio, profile.column_offset_px);
    return true;
}

void prove_oled_glass() {
    if (oled == nullptr) {
        return;
    }
    oled->setPowerSave(0);
    Serial.println(atmosmesh::format_oled_display_on_log().c_str());
    oled->setContrast(255);
    Serial.println(atmosmesh::format_oled_contrast_log().c_str());
    oled->sendF("c", 0x0a6);
    Serial.println(atmosmesh::format_oled_invert_off_log().c_str());

    oled->clearBuffer();
    oled->setDrawColor(1);
    for (int i = 0; i < atmosmesh::oled_boot_bar_count(); ++i) {
        oled->drawBox(0, atmosmesh::oled_boot_bar_y_px(i), atmosmesh::kOledWidthPx,
                      atmosmesh::oled_telltale_bar_height_px());
    }
    oled->sendBuffer();
    Serial.println(atmosmesh::format_oled_boot_bars_log().c_str());
    delay(atmosmesh::oled_boot_bar_hold_ms());
}

void setup_oled() {
    atmosmesh::I2cDevice device{};
    const atmosmesh::I2cBusMap primary{atmosmesh::kOledSdaGpio, atmosmesh::kOledSclGpio};
    const atmosmesh::I2cBusMap swapped{atmosmesh::kOledSclGpio, atmosmesh::kOledSdaGpio};

    bool found = try_oled_bus("oled d5=sda d4=scl", primary, &device);
    if (!found) {
        found = try_oled_bus("oled swapped", swapped, &device);
    }
    if (!found) {
        Serial.println("oled: no i2c device at 0x3C/0x3D on GPIO5/GPIO4");
        return;
    }

    Serial.printf("oled address=0x%02X sda=%d scl=%d\n", device.address, device.pins.sda_gpio,
                  device.pins.scl_gpio);

    const auto compiled = atmosmesh::compiled_oled_profile();
    const atmosmesh::OledProfile candidates[] = {
        compiled,
        atmosmesh::resolve_oled_profile(atmosmesh::OledController::Ssd1306, 64),
        atmosmesh::resolve_oled_profile(atmosmesh::OledController::Sh1106, 64),
    };

    bool started = false;
    for (const auto& candidate : candidates) {
        if (begin_oled(device.address, candidate)) {
            started = true;
            break;
        }
    }
    if (!started) {
        Serial.println("oled: init failed");
        return;
    }

    oled_ready = true;
    prove_oled_glass();
}

void setup_bmp280() {
    const atmosmesh::I2cBusMap pins{atmosmesh::kSensorSdaGpio, atmosmesh::kSensorSclGpio};
    std::uint8_t found[16];
    const std::size_t count = atmosmesh::scan_i2c_bus(Wire1, pins, found, sizeof(found));
    log_scan("bmp sda=21 scl=19", pins, found, count > sizeof(found) ? sizeof(found) : count);
    bmp_address = atmosmesh::pick_bmp_address(found, count);
    if (bmp_address < 0) {
        Serial.println("bmp280: no i2c device on GPIO21/GPIO19");
        Serial.println("bmp280: CSB must be 3V3, SDO to GND for 0x76, VCC to 3V3");
        return;
    }

    Wire1.beginTransmission(static_cast<std::uint8_t>(bmp_address));
    Wire1.write(0xD0);
    if (Wire1.endTransmission() != 0) {
        Serial.printf("bmp280: failed to select chip-id register at 0x%02X\n", bmp_address);
        bmp_address = -1;
        return;
    }
    if (Wire1.requestFrom(static_cast<std::uint8_t>(bmp_address), static_cast<std::uint8_t>(1)) != 1) {
        Serial.println("bmp280: chip-id read failed");
        bmp_address = -1;
        return;
    }
    const std::uint8_t chip_id = static_cast<std::uint8_t>(Wire1.read());
    Serial.printf("bmp280: addr=0x%02X chip_id=0x%02X\n", bmp_address, chip_id);
    if (!atmosmesh::is_bmp_family_id(chip_id)) {
        Serial.println("bmp280: unexpected chip id (0x58=BMP280, 0x60=BME280)");
        bmp_address = -1;
        return;
    }

    // Adafruit_BMP280::begin() calls Wire1.begin() with no pins; restore GPIO21/19.
    if (!bmp280.begin(static_cast<std::uint8_t>(bmp_address), chip_id)) {
        Serial.printf("bmp280: begin failed at 0x%02X\n", bmp_address);
        bmp_address = -1;
        return;
    }
    Wire1.begin(atmosmesh::kSensorSdaGpio, atmosmesh::kSensorSclGpio);
    Wire1.setClock(atmosmesh::kOledI2cHz);
    bmp280.setSampling(Adafruit_BMP280::MODE_NORMAL, Adafruit_BMP280::SAMPLING_X2,
                       Adafruit_BMP280::SAMPLING_X16, Adafruit_BMP280::FILTER_X16,
                       Adafruit_BMP280::STANDBY_MS_500);
    bmp_ok = true;
}

void setup_veml7700() {
    Serial.printf("veml7700: Wire1 SDA=GPIO%d SCL=GPIO%d addr=0x%02X VCC=3V3 (shared with BMP280)\n",
                  atmosmesh::kSensorSdaGpio, atmosmesh::kSensorSclGpio,
                  atmosmesh::kVeml7700Address);
    // Adafruit_I2CDevice::begin() may call Wire1.begin() with no pins; restore 21/19.
    veml_ok = veml7700.begin(&Wire1);
    Wire1.begin(atmosmesh::kSensorSdaGpio, atmosmesh::kSensorSclGpio);
    Wire1.setClock(atmosmesh::kOledI2cHz);
    if (!veml_ok) {
        Serial.println(atmosmesh::format_veml7700_serial(false, 0.0F).c_str());
        return;
    }
    veml7700.setGain(VEML7700_GAIN_1);
    veml7700.setIntegrationTime(VEML7700_IT_100MS);
}

void poll_sds011() {
    while (Serial2.available() > 0) {
        const auto sample = sds011.feed(static_cast<std::uint8_t>(Serial2.read()));
        if (!sample.ok) {
            continue;
        }
        pm_ok = true;
        pm25_ug_m3 = sample.pm25_ug_m3;
        pm10_ug_m3 = sample.pm10_ug_m3;
        last_pm_ms = millis();
        Serial.printf("sds011: pm25=%.1f ug/m3 pm10=%.1f ug/m3\n", static_cast<double>(pm25_ug_m3),
                      static_cast<double>(pm10_ug_m3));
    }
    if (!pm_ok) {
        Serial.println(atmosmesh::format_sds011_no_frame_log().c_str());
        return;
    }
    if ((millis() - last_pm_ms) > kPmStaleMs) {
        pm_ok = false;
        Serial.println(atmosmesh::format_sds011_no_frame_log().c_str());
    }
}

}  // namespace

void setup() {
    Serial.begin(atmosmesh::kSerialBaud);
    delay(200);
    Serial.println("atmosmesh bench bring-up");
    Serial.println("OLED VCC=3V3; BMP280 VCC=3V3 CSB=3V3 SDO=GND; AM2302 VDD=3V3 data=GPIO18");
    Serial.println(atmosmesh::format_sds011_listen_log().c_str());
    Serial.println("mq135: analog GPIO34 ADC1 atten~11dB. Divider 10k series + 20k to GND.");
    Serial.println("mq135: GPIO sees 2/3 of AOUT. 5V AOUT => 3.33V on GPIO34 (no headroom). Never apply 5V to GPIO.");

    analogReadResolution(12);
    analogSetPinAttenuation(atmosmesh::kMq135AdcGpio, ADC_11db);

    setup_oled();
    setup_bmp280();
    setup_veml7700();
    am2302.begin();
    last_env_ms = millis();
    Serial.printf("am2302: data=GPIO%d min_interval_ms=%d\n", atmosmesh::kAm2302DataGpio,
                  atmosmesh::kAm2302MinIntervalMs);
    Serial2.begin(atmosmesh::kSds011Baud, SERIAL_8N1, atmosmesh::kSds011RxGpio,
                  atmosmesh::kSds011TxGpio);
    Serial.printf("sds011: uart2 rx=GPIO%d tx=GPIO%d baud=%d\n", atmosmesh::kSds011RxGpio,
                  atmosmesh::kSds011TxGpio, atmosmesh::kSds011Baud);
    Serial.println(atmosmesh::format_sds011_listen_log().c_str());
    setup_extras();
    atmosmesh::mqtt_runtime_begin();
}

void loop() {
    poll_sds011();
    poll_extras();
    const unsigned long now = millis();
    atmosmesh::mqtt_runtime_tick(now);
    if ((now - last_env_ms) < static_cast<unsigned long>(atmosmesh::kAm2302MinIntervalMs)) {
        delay(kLoopSliceMs);
        return;
    }
    last_env_ms = now;
    // Adafruit DHT caches for MIN_INTERVAL (2 s): humidity does the bus read, temperature reuses it.
    humidity = am2302.readHumidity();
    temperature = am2302.readTemperature();
    am_ok = !isnan(humidity) && !isnan(temperature);
    atmosmesh::update_am2302_hold(am_hold, am_ok, temperature, humidity,
                                  atmosmesh::kAm2302HoldMisses);
    if (am_ok) {
        last_am_ms = now;
        Serial.printf("am2302: t=%.1fC rh=%.1f%%\n", temperature, humidity);
    } else {
        Serial.println("am2302: read failed (need 3V3, 10k pull-up to 3V3 if the module has none)");
    }

    mq_raw = analogRead(atmosmesh::kMq135AdcGpio);
    last_mq_ms = now;
    Serial.println(atmosmesh::format_mq135_serial(mq_raw).c_str());

    bmp_t_c = 0.0F;
    bmp_p_hpa = 0.0F;
    bmp_read_ok = false;
    if (bmp_ok) {
        bmp_t_c = bmp280.readTemperature();
        bmp_p_hpa = bmp280.readPressure() / 100.0F;
        bmp_read_ok = !isnan(bmp_t_c) && (bmp_p_hpa > 300.0F) && (bmp_p_hpa < 1100.0F);
        if (bmp_read_ok) {
            last_bmp_ms = now;
            Serial.println(atmosmesh::format_bmp280_serial(bmp_t_c, bmp_p_hpa).c_str());
        } else {
            Serial.println("bmp280: read failed");
        }
    }

    if (veml_ok) {
        veml_lux = veml7700.readLux();
        Serial.println(atmosmesh::format_veml7700_serial(true, veml_lux).c_str());
    }

    refresh_oled();
    publish_mqtt_state(now);
    delay(kLoopSliceMs);
}

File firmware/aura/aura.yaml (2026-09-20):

# AtmosMesh Aura — giftable air-quality station
#
# Implements: AU-01 (geometry), AU-02 (bus), AU-03 (reading states + air bands), AU-04 (Now
# screen), AU-06 (live sensors with honest failure).
# NOT implemented here: AU-05 provisioning, AU-07 Open-Meteo, AU-08 MQTT.
#
# Sunton ESP32-2432S028 "Cheap Yellow Display", portrait 240x320.
# Sensors on CN1: SGP41 @ 0x59 (VOC + NOx Index), BME280 @ 0x76 (temperature, humidity, pressure).
#
# Rules this file holds up:
#   G4    — everything on the Now screen renders with no network at all.
#   G5    — a dead sensor must never leave its last number on screen.
#   D-002 as amended by D-036 — no eCO2, no ppm, no CO2 anywhere.
#   AU-01 — orientation comes from `transform:` ONLY. Never LVGL `rotation:`: ili9xxx does not
#           register hardware rotation, so LVGL rotates in software and the flush path stretches.

substitutions:
  device_id: atmosmesh-aura
  friendly: Aura

  # --- palette (AU-04). One accent at a time, taken from the current air band. -----------------
  col_bg: "0x0B1220"
  col_surface: "0x151E2E"
  col_text: "0xE9EEF7"
  col_dim: "0x8899AE"
  col_fresh: "0x4ADE80"
  col_fine: "0x38BDF8"
  col_stuffy: "0xFBBF24"
  col_alert: "0xF87171"
  col_unknown: "0x64748B"

esphome:
  name: ${device_id}
  friendly_name: ${friendly}
  # Two of these are being built. Without a MAC suffix both claim the same hostname and the same
  # mDNS name on one LAN, and AU-05's fallback AP would advertise one SSID for both units.
  name_add_mac_suffix: true

esp32:
  board: esp32dev
  framework:
    type: arduino

logger:
  # INFO, not DEBUG: at DEBUG the SGP41 prints its serial number and one "Stabilizing" line per
  # second for 90 s. A handover image should not narrate itself.
  level: INFO

i2c:
  - id: bus_cn1
    sda: GPIO27
    scl: GPIO22
    scan: true
    frequency: 100kHz

spi:
  - id: spi_tft
    clk_pin: GPIO14
    mosi_pin: GPIO13
    miso_pin: GPIO12
  - id: spi_touch
    clk_pin: GPIO25
    mosi_pin: GPIO32
    miso_pin: GPIO39

# --------------------------------------------------------------------------------------------
# AU-01 — display geometry, settled on the bench after five wrong theories.
# MADCTL 0x28. `swap_xy` is what puts the controller into the addressing mode where all
# 240x320 pixels are reachable; declaring the dimensions alone does not.
# --------------------------------------------------------------------------------------------
display:
  - platform: ili9xxx
    id: tft
    model: ILI9341
    invert_colors: false
    spi_id: spi_tft
    cs_pin: GPIO15
    dc_pin: GPIO2
    dimensions:
      width: 240
      height: 320
    transform:
      swap_xy: true
      mirror_x: false
      mirror_y: false
    auto_clear_enabled: false
    update_interval: never

touchscreen:
  - platform: xpt2046
    id: touch
    spi_id: spi_touch
    cs_pin: GPIO33
    interrupt_pin: GPIO36
    threshold: 400
    # PROVISIONAL. These are the landscape community numbers and this product runs portrait with
    # swap_xy. Nothing on the Now screen is tappable, so a wrong axis is invisible until AU-05's
    # keyboard - where it would present as "resistive typing is intolerable" rather than as a
    # calibration bug. AU-01 must close this with a four-corner test before AU-05 starts.
    calibration:
      x_min: 280
      x_max: 3860
      y_min: 340
      y_max: 3860
    transform:
      swap_xy: true

output:
  - platform: ledc
    pin: GPIO21
    id: backlight_pwm
    frequency: 20000Hz

light:
  - platform: monochromatic
    output: backlight_pwm
    id: backlight
    name: Backlight
    restore_mode: ALWAYS_ON
    default_transition_length: 400ms

# --------------------------------------------------------------------------------------------
# AU-03 — freshness bookkeeping.
# `on_value` alone cannot implement the state machine: when a read fails, both drivers return
# WITHOUT publishing (sgp4x.cpp:229 sets UINT16_MAX and skips publish_state; bme280_base does the
# same). So a callback-only UI freezes on the last good number forever - exactly the failure G5
# forbids. These timestamps let a timer notice the silence.
# --------------------------------------------------------------------------------------------
globals:
  - id: t_voc
    type: uint32_t
    restore_value: false
    initial_value: "0"
  - id: t_nox
    type: uint32_t
    restore_value: false
    initial_value: "0"
  - id: t_climate
    type: uint32_t
    restore_value: false
    initial_value: "0"
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

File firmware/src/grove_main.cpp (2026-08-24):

#include <Arduino.h>
#include <Adafruit_BMP085.h>
#include <DHT.h>
#include <U8g2lib.h>
#include <Wire.h>

#include <cmath>

#include "atmosmesh/grove_status.hpp"
#include "atmosmesh/product_profile.hpp"

namespace {

constexpr unsigned long kSampleIntervalMs = 2500;
constexpr std::uint32_t kI2cClockHz = 100000;
constexpr std::uint8_t kOledAddresses[] = {0x3C, 0x3D};
constexpr std::uint8_t kBmp180Address = 0x77;

const auto& profile = atmosmesh::grove_profile();
DHT dht(profile.dht_data_gpio, DHT11);
Adafruit_BMP085 bmp180;
U8G2_SSD1306_128X32_UNIVISION_F_HW_I2C oled(U8G2_R0, U8X8_PIN_NONE,
                                             profile.i2c_scl_gpio, profile.i2c_sda_gpio);
atmosmesh::GroveReadings readings{};
bool oled_ready = false;
bool bmp_ready = false;
unsigned long last_sample_ms = 0;

bool i2c_address_present(std::uint8_t address) {
    Wire.beginTransmission(address);
    return Wire.endTransmission() == 0;
}

int find_oled_address() {
    for (const auto address : kOledAddresses) {
        if (i2c_address_present(address)) {
            return address;
        }
    }
    return -1;
}

void render() {
    if (!oled_ready) {
        return;
    }
    const auto lines = atmosmesh::grove_oled_lines(readings);
    oled.clearBuffer();
    oled.setFont(u8g2_font_5x7_tf);
    constexpr int kBaselines[] = {7, 15, 23, 31};
    for (std::size_t i = 0; i < lines.size(); ++i) {
        oled.drawStr(0, kBaselines[i], lines[i].c_str());
    }
    oled.sendBuffer();
}

void setup_oled() {
    const int address = find_oled_address();
    if (address < 0) {
        Serial.println("oled: error not found at 0x3C/0x3D");
        return;
    }
    oled.setI2CAddress(static_cast<std::uint8_t>(address << 1));
    oled.setBusClock(kI2cClockHz);
    oled_ready = oled.begin();
    Serial.printf("oled: %s addr=0x%02X geometry=%dx%d\n", oled_ready ? "ok" : "error",
                  address, profile.oled_width_px, profile.oled_height_px);
}

void setup_bmp180() {
    if (!i2c_address_present(kBmp180Address)) {
        Serial.println("bmp180: error not found at 0x77");
        return;
    }
    bmp_ready = bmp180.begin(BMP085_STANDARD, &Wire);
    // Keep the operator's non-default bus pins explicit even if a library calls Wire.begin().
    Wire.begin(profile.i2c_sda_gpio, profile.i2c_scl_gpio);
    Wire.setClock(kI2cClockHz);
    Serial.printf("bmp180: %s addr=0x77\n", bmp_ready ? "ok" : "error");
}

bool prepare_bmp180_sample() {
    const bool address_present = i2c_address_present(kBmp180Address);
    switch (atmosmesh::grove_bmp_action(address_present, bmp_ready)) {
        case atmosmesh::GroveBmpAction::Unavailable:
            if (bmp_ready) {
                Serial.println("bmp180: lost addr=0x77; prior reading invalidated");
            }
            bmp_ready = false;
            atmosmesh::invalidate_grove_bmp(readings);
            return false;
        case atmosmesh::GroveBmpAction::Initialize:
            bmp_ready = bmp180.begin(BMP085_STANDARD, &Wire);
            // Adafruit_BMP085 may call Wire.begin(); restore the wired D2/D3 bus explicitly.
            Wire.begin(profile.i2c_sda_gpio, profile.i2c_scl_gpio);
            Wire.setClock(kI2cClockHz);
            Serial.printf("bmp180: %s addr=0x77 after probe\n",
                          bmp_ready ? "recovered" : "initialize error");
            if (!bmp_ready) {
                atmosmesh::invalidate_grove_bmp(readings);
            }
            return bmp_ready;
        case atmosmesh::GroveBmpAction::Read:
            return true;
    }
    return false;
}

void sample_sensors() {
    const float humidity = dht.readHumidity();
    const float dht_temperature = dht.readTemperature();
    const bool dht_valid = std::isfinite(humidity) && std::isfinite(dht_temperature);
    readings.humidity = {dht_valid, dht_valid ? humidity : 0.0F};
    readings.dht_temperature = {dht_valid, dht_valid ? dht_temperature : 0.0F};

    bool bmp_valid = false;
    float bmp_temperature = 0.0F;
    float pressure_hpa = 0.0F;
    if (prepare_bmp180_sample()) {
        bmp_temperature = bmp180.readTemperature();
        pressure_hpa = bmp180.readPressure() / 100.0F;
        bmp_valid = std::isfinite(bmp_temperature) && std::isfinite(pressure_hpa) &&
                    pressure_hpa >= 300.0F && pressure_hpa <= 1100.0F;
    }
    if (bmp_valid) {
        readings.bmp_temperature = {true, bmp_temperature};
        readings.pressure = {true, pressure_hpa};
    } else {
        atmosmesh::invalidate_grove_bmp(readings);
    }

    if (dht_valid) {
        Serial.printf("dht11: ok temperature=%.1f C humidity=%.1f %%RH\n",
                      static_cast<double>(dht_temperature), static_cast<double>(humidity));
    } else {
        Serial.println("dht11: error reading unavailable");
    }
    if (bmp_valid) {
        Serial.printf("bmp180: ok temperature=%.1f C pressure=%.1f hPa\n",
                      static_cast<double>(bmp_temperature), static_cast<double>(pressure_hpa));
    } else {
        Serial.println("bmp180: error reading unavailable");
    }
    Serial.printf("health: %s\n", atmosmesh::grove_health_text(readings).c_str());
    render();
}

}  // namespace

void setup() {
    Serial.begin(115200);
    delay(200);
    Serial.printf("product=%s variant=%s station_id=%s\n", profile.product_name,
                  profile.product_variant, profile.station_id);
    Serial.printf("i2c: SDA=D2/GPIO%d SCL=D3/GPIO%d clock=%lu Hz\n", profile.i2c_sda_gpio,
                  profile.i2c_scl_gpio, static_cast<unsigned long>(kI2cClockHz));
    Serial.println("boot-warning: D3/GPIO0 must remain HIGH during reset");
    Serial.printf("dht11: DATA=D5/GPIO%d (profile assumption; verify physical joint)\n",
                  profile.dht_data_gpio);
    Serial.println("power: OLED, BMP180 and DHT11 are 3V3 only");

    Wire.begin(profile.i2c_sda_gpio, profile.i2c_scl_gpio);
    Wire.setClock(kI2cClockHz);
    setup_oled();
    setup_bmp180();
    dht.begin();
    Serial.println("dht11: initialized; first read follows minimum interval");
    render();
    last_sample_ms = millis();
}

void loop() {
    const unsigned long now = millis();
    if (now - last_sample_ms >= kSampleIntervalMs) {
        last_sample_ms = now;
        sample_sensors();
    }
    delay(10);
}

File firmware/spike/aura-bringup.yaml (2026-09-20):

# AtmosMesh Aura — one-day bring-up spike (ESPHome)
#
# THIS IS NOT THE PRODUCT. It is a throwaway diagnostic whose only job is to answer, in one day
# and with no C++ written, the five questions that otherwise stay open until story AU-09.
# See README.md in this directory for the runbook and the results table to fill in.
#
# Target: Sunton ESP32-2432S028 "Cheap Yellow Display", portrait 240x320.
# Pin map below is the community reference (docs/hardware/inventory.md) and is a HYPOTHESIS.
# If the display stays black, the pin map is the first thing to doubt, not the last.

substitutions:
  name: aura-spike
  # Pigtail sensors on the CN1 header. HenrysCat's working sketch on this exact board uses
  # SDA=27 / SCL=22; we keep that orientation so the 4-pin cable colours line up.
  i2c_sda: GPIO27
  i2c_scl: GPIO22

esphome:
  name: ${name}
  friendly_name: Aura Spike
  # The spike must prove G4: sensors render with no network at all. ESPHome does not block
  # startup on Wi-Fi, but make it explicit so a failed join never gates the display.
  on_boot:
    priority: 600
    then:
      - light.turn_on:
          id: status_led
          red: 100%
          green: 60%
          blue: 0%
          brightness: 30%

esp32:
  board: esp32dev
  framework:
    type: arduino

logger:
  level: DEBUG

# ---------------------------------------------------------------------------------------------
# Q2 — does the CN1 I2C bus work, and do all three sensors ACK?
# `scan: true` prints every responding address at boot. Expect:
#   0x38 AHT20 (fixed)   0x52 or 0x53 ENS160 (ADDR pin)   0x76 BME280 (SDO low)
# A missing address here is a wiring or pull-up problem, NOT a sensor fault. Record what you see.
# ---------------------------------------------------------------------------------------------
i2c:
  - id: bus_cn1
    sda: ${i2c_sda}
    scl: ${i2c_scl}
    scan: true
    # Start conservative. The sensor breakouts carry their own 10k pull-ups; adding 4.7k in
    # parallel lands near 2.4k effective, which is legal but should be measured, not assumed.
    frequency: 100kHz

# Two SPI buses: the TFT has its own, and the XPT2046 touch controller has its own pins.
spi:
  - id: spi_tft
    clk_pin: GPIO14
    mosi_pin: GPIO13
    miso_pin: GPIO12
  - id: spi_touch
    clk_pin: GPIO25
    mosi_pin: GPIO32
    miso_pin: GPIO39

# ---------------------------------------------------------------------------------------------
# Q1 — WHICH DISPLAY CONTROLLER IS FITTED?
#
# ESPHome cannot read the controller's ID register, so this spike identifies it EMPIRICALLY.
# Start with ILI9341 below. Then judge against the test card the UI draws:
#
#   correct geometry, correct colours          -> ILI9341, no inversion.     Record it.
#   correct geometry, colours look negative    -> add `invert_colors: true`.
#   nothing, or a shifted/garbled image        -> switch to `model: ST7789V`.
#
# The dual Micro-USB + Type-C sockets on these units point at the ST7789 "CYD2USB" variant, so
# do not be surprised if ILI9341 is wrong. Whichever renders the RED/GREEN/BLUE bars in the right
# order, at the right size, with no dead band, is the answer -- write it into inventory.md.
#
# Note `rotation: 0` = native portrait 240x320, which is what the product wants and which also
# sidesteps the rotation fault the cyd-dashboard firmware showed on this board.
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

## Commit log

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2026-08-14 :wrench: fix(firmware): remap bench pins off GPIO2
    LCD SDA moves to GPIO5 so flash is no longer blocked by a GPIO2 I2C pull-up. BMP SCL is GPIO19 and AM2302 data is GPIO18.
    [main.cpp]
2026-08-14 :wrench: chore(firmware): pin agent Python venv for esptool
    Stop host-tool failures from system python (no pyserial/esptool) by
    documenting a shared venv and wrapping task flash/monitor with it.
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2026-08-14 :sparkles: feat(pcb): add KiCad bench-station carrier board
    Two-layer through-hole carrier for the bench revision: the ESP32-WROOM-32
    DevKit sits in 2x 1x15 sockets, the three 3.3 V sensors get connectors, and
    SDS011/MQ135 get 5 V connectors in a fenced-off block so no 5 V net can reach
    a GPIO or the 3V3 rail. Common GND only; the AC/DC module stays off-board.
    Wired to the operator's rewired bench map: LCD on GPIO5/GPIO4, BMP280 on
    GPIO21/GPIO19 with CSB=3V3 and SDO=GND, AM2302 on GPIO18. GPIO2 is left
    unconnected so USB flashing needs no jumper, which retires the old LCD
    flash-jumper workaround.
    Symbols and footprints are vendored into project-local libraries so the
    project resolves stand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
    [atmosmesh-bench.kicad_pcb, atmosmesh-bench.kicad_sch]
2026-08-14 :bug: fix(firmware): correct OLED geometry/controller for missing lines
    Cheap 0.96" SSD1306 clones drop every other row with Adafruit's alternate
    COM (0x12). Init at 100 kHz with sequential COM (0x02), log controller
    geometry, and keep SH1106 plus 128x32 behind compile flags.
    [i2c_bus.cpp, main.cpp, oled_profile.cpp]
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2026-08-15 :bug: fix(firmware): use U8g2 SSD1306 ALT0 sequential COM
    Cheap 0.96" panels skip rows with alternate COM 0x12; ALT0 uses 0x02.
    SH1106 stays a compile fallback. Brief HI then live sensor page.
    [main.cpp, oled_profile.cpp]
2026-08-15 :sparkles: feat(firmware): show T RH hPa PM and gas index on OLED
    Read BMP280 C/hPa on Wire1, drop slash PM and CO2 labels, and draw five short live rows instead of cramped address/volt dump.
    [main.cpp, mq135_scale.cpp]
2026-08-15 :bug: fix(firmware): drive 128x32 OLED with a 2x3 value matrix
    Five 12 px rows only showed the last two lines on a 32 px glass. Default U8g2 to Univision 128x32 and pack T/RH/hPa plus PM2.5/PM10/gas on two 6x10 lines.
    [main.cpp, oled_profile.cpp]
2026-08-15 :bug: fix(firmware): drive 128x48 OLED with a 3x2 value matrix
    U8g2 has no 128x48 constructor; ALT0 128x64 RAM plus mux 0x2F shows 48 rows.
    [main.cpp, oled_profile.cpp]
2026-08-15 :bug: fix(firmware): drive full 128x64 OLED with three live rows
    ALT0 sequential COM is the default; mux 0x2F and Univision 128x32 were
    only lighting the top of the glass. Layout uses y=4/24/44 plus a boot
    telltale bar at y=62.
    [main.cpp, oled_profile.cpp]
2026-08-15 :bug: fix(firmware): pack live OLED rows into lower 32 px
    After ALT0 only RAM y~40-63 mapped to glass. Boot bars at 0/16/32/48/62
    then T/RH, hPa, PM at y=34/46/58. Flip stays 0 (ATMOSMESH_OLED_FLIP).
    [main.cpp, oled_profile.cpp]
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2026-08-15 :bug: fix(firmware): hold last AM2302 T/RH on OLED misses
    A single DHT22 checksum/timeout was blanking line 1 to -- every 2.5 s poll.
    Keep the last good sample for four consecutive misses and wait 2.5 s after begin before the first read.
    [main.cpp]
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2026-08-15 :sparkles: feat(firmware): add VEML7700 lux on shared Wire1
    Drop clap/mic GPIO paths. Probe lux at 0x10 on BMP280 SDA/SCL so the
    OLED can show lx without burning a new pin; absent part is an expected miss.
    [main.cpp]
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2026-08-15 :books: docs: land PCB extras outcome and schematic-review verdict
    Record that firmware and extras now live on main. Leave the stale
    concept-wiring SVG out — its GPIO map is wrong.
2026-08-20 :memo: docs(pcb): document drill export in the fab-output recipe
    The gerber set uploaded to JLCPCB had no Excellon drill files, so the
    board showed zero holes and the order was rejected. `pcb export gerbers`
    never emits drill data; `pcb export drill` is a separate command and the
    README documented only ERC/DRC/netlist/PDF, so the step was easy to miss.
    Add the full recipe (gerbers + drill + zip), the origin-flag warning that
    prevents holes-offset-from-pads, and three pre-upload checks: hole counts
    (132 PTH incl. 27 vias, 4 NPTH at 3.2 mm), drill-inside-outline
    alignment, and a 12-file zip manifest.
2026-08-20 :memo: docs(hardware): record LDO incident and 5 V bench bring-up
    Capture the 2026-08-17 LDO replacement and the 3V3-pass / 5V-fail sensor partition,
    including the SDS011 straight-through UART contention hazard.
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2026-08-20 :sparkles: feat(mqtt): publish HA discovery from atmosmesh-0001
    Add a host-tested MQTT contract and async ESP client so the station publishes
    JSON state plus Home Assistant discovery to kumulus Mosquitto on LAN :1883.
    Topics are id-based (no room), lux is omitted until fitted, and missing
    secrets.hpp keeps sensors and OLED running without networking.
    [main.cpp, mqtt_contract.cpp, mqtt_runtime.cpp]
2026-08-20 :bug: fix(mqtt): use IDF 4.x esp_mqtt config on Arduino-ESP32
    Nested IDF 5 mqtt client fields do not compile on this platform; switch to the
    flat uri/username/password/lwt API. Verified on kum3 LAN :1883 with discovery
    and state publishes for atmosmesh-0001.
    [mqtt_runtime.cpp]
2026-08-24 :bug: fix(grove): invalidate BMP180 readings on loss
    [grove_main.cpp]
2026-08-24 :bug: fix(grove): bound reconnect and preserve readings
    [grove_mqtt_runtime.cpp]
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2026-08-24 :bug: fix(mqtt): acknowledge accepted v1 state
    [mqtt_runtime.cpp]
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2026-08-26 :bug: fix(aqua): close review findings on the Aqua lane
    Independent review (F1-F3): add missing task build/flash/monitor/clean
    targets for the new atmosmesh-aqua-v1 environment and fold into build-all
    per ADR-0001 step 4; add the Aqua row to ADR-0001's product matrix; delete
    the dead, never-called aqua_core_sensors_ok() and its test (Aqua has no
    status LED per AQ-01 scope).
2026-08-26 :memo: docs(aqua): record real hardware bring-up and first flash
    Board soldered/wired without the pre-wiring photo step; documents the
    electrical-characterization trail that replaced it (contaminated board
    readings, isolated probe/board measurements, 1.3V peak wet AOUT, external
    10k/10k divider added for safety), the esptool health check, and the first
    successful flash with live SHT41/water-probe serial confirmation.
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2026-08-26 :sparkles: feat(grove): calibrate soil moisture LED thresholds
    Enable soil calibration on the canonical Grove build (D-021): raw ADC
    >=200 reads dry (red), <=100 reads well-watered (green), the band
    between reads needs-watering (amber). Native tests keep calibration
    compiled disabled so the fail-safe-default coverage still holds.
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2026-08-28 :bug: fix(room): make the polarity symbols survive their own gates
    The independent review asked for real polarity and C/B/E semantics so ERC can
    catch a reversed diode or transistor. Fitting D_Schottky, D and Q_NPN_CBE and
    adding per-instance descriptions did that, but left three gates red:
    - The local library and the schematic's embedded copy were built from separate
    sources and given different Description text, so all 27 symbols raised
    lib_symbol_mismatch. Both now derive from the one list the schematic embeds,
    which also carries U1's passive pin types across.
    - D_BEEP's new anode marker sits 7.62 mm right of the part origin and clipped
    mounting hole H2's mask at x=168. Moved to x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
    [atmosmesh-room.kicad_pcb, atmosmesh-room.kicad_sch]
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2026-08-28 :bug: fix(room): wire the buzzer the module actually has
    Operator identified it: a no-name Keyes 3-pin breakout, black cylinder with a
    single hole, header order S / VCC / -. It is the same part AtmosMesh v1 uses,
    and firmware/README.md records v1 driving it with a bare 50 ms
    digitalWrite(HIGH) on GPIO25. So it is an active module with its own driver.
    The carrier presented a 2-pin header and switched the load's low side. Against
    a 3-pin S/VCC/- module that could not have worked at all: the module's S input
    had no connection. Q_BEEP, R_BEEP_IN, R_BEEP_PD and the D_BEEP flyback are
    removed. GPIO25 now drives S through R_BEEP_S 100R, active HIGH, matching v1.
    No flyback is fitted because an int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
    [BOM.csv, atmosmesh-room.kicad_pcb, atmosmesh-room.kicad_sch]
2026-08-28 :sparkles: feat(room): add the SDS011 with the protection the bench fault earned
    ROOM-02. The operator asked for the SDS011 that already worked on AtmosMesh v1,
    with additional protection. The protection is aimed at a specific, recorded
    failure rather than at hazards in general.
    On 2026-08-17 this sensor was wired straight through: its push-pull TXD landed
    on the ESP32's push-pull TX2 and the two fought on one net for roughly 10 ms in
    every second, against a 40 mA absolute maximum. So:
    - The UART is crossed. Sensor TXD reaches GPIO16/RX2, GPIO17/TX2 reaches sensor
    RXD, each through 1k. That bounds a driver fight to about 3.3 mA. At 9600 baud
    a bit is 104 us while 1k into a few hundred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
    [BOM.csv, atmosmesh-room.kicad_pcb, atmosmesh-room.kicad_sch]
2026-08-28 :sparkles: feat(room): build on the perfboard and with the parts that exist
    ROOM-03 and ROOM-04. The operator solders this by hand on a 31x27 perfboard and
    does not need the PCB, and the inventory landed in the repo, so several values
    that were chosen "because those parts are available" no longer have to be.
    Perfboard becomes the build target (D-027):
    - perfboard.md carries the grid facts, placement zones, hole budget and build
    order. The 7x9 cm label and the 31x27 hole count are reconciled: the extra
    millimetres are unholed lead-in strips.
    - validate_room_perfboard.py gates it. A build plan with no gate is exactly the
    pattern this repo keeps hitting. All five assertions are mutation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
    [BOM.csv, atmosmesh-room.kicad_pcb, atmosmesh-room.kicad_sch]
2026-08-28 :bug: fix(room): stop the schematic labelling the TFT pins as power rails
    Final review of the generated artifacts. U1's nets were right, but its symbol
    was still the bench project's ESP32_DevKit_V1_Socket, whose pin names run from
    the opposite end of the row. KiCad writes each unconnected pad's own pin name
    into a placeholder net, which is where this surfaced:
    pad 30 showed 3V3 - it is really GPIO23, the TFT MOSI line
    pad 4 showed GPIO34 - it is really GPIO12, the flash-voltage strap
    That is precisely the hazard D-024 names: knowing the pin order makes the
    socket more dangerous, because a builder can now confidently reach the wrong
    pin. A schematic that prints "3V3" next to TFT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
    [atmosmesh-room.kicad_pcb, atmosmesh-room.kicad_sch]
2026-08-28 :memo: docs(inventory): record 4x VEML7700 and 4x SHT41 with their fixed addresses
    Both types have a fixed I2C address - VEML7700 at 0x10 and SHT41 at 0x44 - so
    holding four of each does not allow two of the same sensor on one bus. The
    spares enable parallel Room, Aqua and bench builds instead. No I2C multiplexer
    is recorded in stock. Also carries the operator-confirmed breakout pin orders
    into the inventory, where the Room design already relies on them.
2026-08-28 :white_check_mark: test(room): gate the pad table a builder actually reads
    The build rule is authoritative-by-pin-name, so wiring.md's hand-authored
    30-row socket table is the document a perfboard builder works from. Nothing
    kept it honest against IDEASPARK_PINS - it happened to agree, but only by
    hand. The validator now cross-checks every pad, mutation-proved by drifting
    pad 26 from GPIO21 to GPIO19.
    Also corrects ROOM-01's stale evidence: the intentional unrouted ratsnest is
    62 items now, not the 52 recorded from the previous session, because the
    pull-ups and the SDS011 block were added and the buzzer driver removed.
2026-08-28 :sparkles: feat(room): indicate live domains, and delete the switch the sensor makes unnecessary
    Two improvements from the updated inventory, and one of them removes hardware
    rather than adding it.
    Domain indicators (D-029). Both 5 V jumpers are default-open and the build plan
    requires them to stay open until measurements are recorded, but there was no way
    to see whether a domain was live - on the one board in this project whose whole
    risk story is an unverified 5 V rail. D_LED_3V3 (470R), D_LED_SDS and D_LED_PIR
    (1k each) fix that. The 5 V indicators are fed downstream of their own jumpers,
    so a lit LED is direct evidence that the jumper it reports on is closed. Red or
    green only: a blue L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
    [BOM.csv, atmosmesh-room.kicad_pcb, atmosmesh-room.kicad_sch]
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2026-08-28 :pencil2: fix(room): the buzzer's oscillator is in the can, not on the breakout
    The operator inspected the Keyes breakout and found no active parts on the
    PCB, which falsifies D-025's stated reason -- that the *module* carried its
    own driver. The rule survives on different evidence, and the rationale is
    rewritten to rest on it: v1 sounds this part with a bare 50 ms DC
    digitalWrite(HIGH), which neither a piezo disc (one tick per edge, not a
    50 ms tone) nor a passive coil (a click, plus far more current than a GPIO
    should source) can do. Only a self-oscillating transducer does that, so no
    external transistor is fitted.
    This nearly went the other way. Sizing R_BEEP_S on a capacitive-load model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
2026-08-28 :white_check_mark: fix(room): anchor the SDS011 colour gate to headings, not a magic offset
    The gate I added one commit ago sliced the SDS011 section as the 2500 bytes
    before the crossed-UART heading. That window opened at 11628 while the section
    actually starts at 12799, so it was scanning 1171 bytes of D-SUN PIR prose it
    had no business reading, and its failure message named the wrong section.
    Both drift directions were live faults. Lengthen the SDS text and the window
    truncates from the top, letting a wire colour added there escape the ban
    silently -- a gate that reports PASS while the thing it guards is broken.
    Shorten it and unrelated prose gets pulled in, producing a FAIL nobody can
    a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
2026-08-28 :sparkles: feat(room): colour TFT bring-up for VEML7700 + SHT41, and an I2C bus that reports instead of hanging
    New product composition root atmosmesh-room-v1 for the ideaspark ESP32-WROOM-32
    with its on-board 1.14 inch ST7789. Bring-up scope only: the two 3.3 V I2C
    sensors and the display. No Wi-Fi, no MQTT, no 5 V devices -- the SDS011, PIR
    and buzzer are not in this build.
    Display uses Adafruit GFX + ST7789 rather than TFT_eSPI, so every pin is set in
    code and there is no User_Setup header for a dependency update to overwrite.
    Chrome is drawn once and only changed values and bars repaint, so the panel
    does not flicker at 1 Hz. Values are colour-coded by comfort band and each has
    a propor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
2026-08-28 :sparkles: feat(room): PIR, particulates and a beeper that answers to them
    The room board grows three inputs and one output. PIR occupancy on GPIO33, the SDS011 listened
    to on UART2, and the beeper on GPIO25 sounding when particulates cross into unhealthy.
    The alarm is a tested policy rather than a comparison in the loop. A single threshold makes a
    reading that happens to sit on it chatter the beeper once a second, because the SDS011 reports
    at 1 Hz and real air does not hold still, so PmAlarm carries separate alarm and clear levels and
    re-announces at most once a minute while the air stays bad. Missing frames are Unknown, never
    Good: silence from a particulate sensor is not clean air, and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
    [sds011_frame.cpp]
2026-08-28 :bug: fix(room): a flapping particulate sensor must not earn an extra beep
    mark_no_data() reset the re-announce timer along with the level, so an SDS011 dropping frames in
    genuinely bad air beeped on every recovery - once per dropout rather than once per minute, which
    is the exact spam the hysteresis was built to prevent. The timer now survives the gap. A dropout
    longer than the interval still announces on return, and clean air in between still makes the next
    rise a new event that announces immediately. Three tests pin the distinction, replacing one that
    had encoded the old behaviour as intended.
    draw_status_dots() refused to paint over the bus-fault splash at one call site and not the othe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
2026-08-30 :sparkles: feat(mqtt): an AtmosMesh Room contract, and a discovery switch that cannot fall through
    Adds RoomMqttState, kRoomContract and the room discovery spec list on
    atmosmesh-room-0001, plus room_mqtt_state_json.
    Room deliberately uses the nested {value, unit, valid, age_ms} payload and the
    `if valid else none` template rather than grove/aqua's flat `| default(none)`.
    The room is the case that needs it: an SDS011 that has stopped sending frames
    must reach Home Assistant as unavailable, never as clean air, and a PIR inside
    its warm-up must not publish "no motion" as though that were a measurement.
    discovery_specs() becomes an exhaustive switch with no default. The if-chain it
    replaces f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
    [mqtt_contract.cpp]
2026-08-30 :sparkles: feat(room): a chirp that is 60 ms, a motion cell that says what it means, and the room in Home Assistant
    Three things the operator asked for, and two bugs found while proving them.
    The boot chirp was a drone. beeper.start() drives GPIO25 HIGH and only
    service() lowers it, and service() was reachable from loop() alone -- so the
    pin stayed HIGH through the I2C scan and the 1600 ms splash delay(). Measured
    before the fix: one ~1.8 s tone. setup() now waits via wait_servicing(), which
    also keeps the PIR poll and the SDS011 drain alive across the splash. Measured
    after: 60 ms.
    The particulate alarm had the same shape of bug one level down. It fired at the
    top of the 1 Hz block, in fr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
    [room_mqtt_runtime.cpp]
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2026-08-31 :memo: docs(backlog): log archive, enclosure heat, Room PIR flip, and Grove LED
    Field notes from 2026-08-31: retire disassembled atmosmesh-0001, fix Grove/Aqua
    housing-biased temps, invert Room occupancy to match reality, and unblock the
    Grove LED that never reaches green.
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2026-09-04 :memo: docs(inventory): record two ENS160+AHT20 combo modules
    Read out on 4 September 2026, not photo-verified. Two pieces, eight pins each. Recorded in both
    inventories with the facts that shape their use: the AHT20 sits on a fixed I2C address, so the
    pair serves two builds rather than one bus, and the ENS160's eCO2 figure is derived from VOC and
    must not be labelled CO2. The English row lives in its own section at the end of the file.
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2026-09-04 :memo: docs(inventory): the H34A board is a 433 MHz transmitter, and it has a receiver
    Confirmed on 4 September 2026: two H34A transmitters and two H3V4F receivers. The NDR4208 SAW
    resonator recorded earlier fixes the transmitter at 433.92 MHz, which closes the open question
    about what the H34A board does.
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2026-09-04 :memo: docs(inventory): count the power modules, and resolve the 5M001 mystery
    Counted on 4 September 2026: three 5V07/12V04 boards, four SANMIM SM-PLG06A, two SANMIM SM-PLB03A
    and one MB102-type breadboard supply. The SM001 marking that was filed as an unidentified mini
    power module is the coil on the SM-PLB03A boards.
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2026-09-04 :memo: docs(spot): file the HLK-LD2410S datasheets and draw the first Spot's BOM, layout and wiring
    Official Hi-Link user manual V1.3 and serial protocol V1.00 retrieved
    from the manufacturer's Drive folder with SHA-256 provenance. They settle
    the radar: 3.0-3.6 V supply, every pin 0-3.3 V, J2 order 3V3 GND OT1 RX
    OT2 where OT2 is the presence output and OT1 is the UART TX, 115200 8N1,
    average current under 1 mA with ~118 mA peaks. SP-01 and both inventories
    corrected to the real pin names. The first Spot is the In/Out variant with
    the probe; hardware/kicad/atmosmesh-spot/ holds its bill of materials,
    14 x 20 layout with header coordinates, net list, per-module diagrams,
    cable rules, build o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
    [BOM.csv]
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2026-09-04 :white_check_mark: docs(spot): the OLED is at 0x3C on GPIO5/GPIO6, scanned on the real board
    The c3scan firmware was flashed over the board's native USB after adding
    the operator to dialout: ESP32-C3 rev 4, 4 MB flash, one device on the
    bus at 0x3C with SDA on GPIO5 and SCL on GPIO6, every other pair empty.
    SP-01 open question 1 and acceptance criterion 1 close; the SuperMini row
    in both inventories and the Spot wiring document carry the result. The
    scanner's note formatting is fixed.
    [main.cpp]
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2026-09-20 :memo: docs(hardware): bench results from the CYD spike, flashed and measured
    Flashed unit 1 (20:50:0d:34:46:3c) with the ESPHome spike and recorded what
    the board actually does, replacing community reference with measurement.
    The display renders correctly as ILI9341 with invert_colors false, BGR
    order, Mirror_x, MADCTL 0x48, at 240x320. Not a register read, but the
    panel takes the ILI9341 command set and produces correct colour and
    geometry. The community pin map is correct on this unit, and the XPT2046
    returns sensible coordinates and pressure under a real finger.
    The flash worry resolves in the good direction. The review estimated
    1.6-1.9 MB and warned of overflowing the Arduino default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
    [aura-bringup.yaml]
2026-09-20 :memo: docs(hardware): CYD sensor wiring, and set the spike to rotation 90
    Bench result: the logical/physical mapping on this unit is the opposite of
    what the driver numbers suggest. rotation 0 gives LVGL a 240x320 buffer the
    driver calls portrait, but on the glass it appears landscape and only 240
    of the panel 320 scanned columns are written, leaving the right quarter
    unpainted. rotation 90 gives LVGL 320x240, which addresses all 320 columns
    and lands the long axis vertically. The number that reads landscape is the
    one that produces portrait here.
    Adds the wiring doc for the two I2C modules on CN1. Four wires from one
    header to both modules in parallel, no address collisions at 0x38, 0x52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
    [aura-bringup.yaml]
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2026-09-20 :sparkles: feat(aura): spec the Aura stories and build the offline core
    Ten stories AU-01..AU-10 written against what the bench actually proved,
    plus roadmap rows. They replace the summary table in the design doc,
    which assumed bespoke C++ and the ENS160 - both since reversed.
    Firmware is ESPHome. The bring-up spike settled the bespoke-vs-ESPHome
    question on hardware, which was the earlier review's CRITICAL C3.
    This commit is the offline core: display geometry, both sensors, the Now
    screen, the air-band logic and LDR dimming. Provisioning, Open-Meteo and
    MQTT are not written yet.
    Geometry is MADCTL 0x28 - dimensions 240x320 with transform swap_xy.
    LVGL rotation is deliberately unused: ili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
    [aura-bringup.yaml, aura.yaml, geometry-probe.yaml]
2026-09-20 :sparkles: feat(aura): table-driven readings, redesigned screen, carrier board spec
    Acts on the architecture review, which was BLOCK on two counts.
    The state machine was really two states. Both drivers return WITHOUT
    publishing when a read fails - sgp4x.cpp:229 sets UINT16_MAX and skips
    publish_state, bme280_base does the same - so a callback-only UI freezes
    on the last good number forever, which is the failure G5 exists to
    forbid. A 2 s timer now owns every pixel, and OK/WARMING/STALE/FAULT are
    each a distinct colour. FAULT is also painted at boot, where no on_value
    can ever fire because a failed component is never scheduled again.
    buffer_size drops 50% -> 25%. It was raised to test a flu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
    [aura.yaml]
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

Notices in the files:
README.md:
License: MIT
